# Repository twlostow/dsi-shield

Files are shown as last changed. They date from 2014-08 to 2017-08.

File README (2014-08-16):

DSI Core Readme
------------------------

0. Disclaimer

This project implements a MIPI DSI (MIPI Display Serial Interface) Verilog core.
Since the DSI specification is non-public and requires an NDA, the core was built
using bits and pieces available throughout the Web: presentations, display controller/SOC
datasheets, various application notes and Android kernel drivers. The author is not 
associated in any way with the MIPI Alliance. The core is provided as-is, it has never been
verified for compliance with the DSI standard and it probably lacks many of its features.
You use it at your own risk, there's no warranty.

1. License

- All HDL (unless otherwise noted) is released under LGPL v3.0
- All software (unless otherwise noted), is GPL v 3.0 or later.
- PCB design and schematics are licensed under CERN Open Hardware License v 1.2.

2. Acknowledgements

- Special thanks go to Sebastien Bourdeauducq, the creator of the Milkymist project, for his 
  excellent IP cores (HPDMC, FML and LM32 Xilinx port) used by in the DSI shield firmware.

- Andrew "Bunnie" Huang, for his EDID generation tools (Chumby WebTV project).

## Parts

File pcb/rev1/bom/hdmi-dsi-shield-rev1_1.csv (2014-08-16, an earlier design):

Comment | Description | Designator | Footprint | Mounted | Quantity | Value
100n | Capacitor | C1 | CAPC1608X87N | Yes | 1 | 100n
100n | Capacitor | C2 | CAPC1608X87N | Yes | 1 | 100n
100n | Capacitor | C3 | CAPC1608X87N | Yes | 1 | 100n
100n | Capacitor | C4 | CAPC1608X87N | Yes | 1 | 100n
100n | Capacitor | C5 | CAPC1608X87N | Yes | 1 | 100n
1u X5R | Capacitor | C6 | CAPC1608X87N | Yes | 1 | 1u X5R
100n | Capacitor | C7 | CAPC1608X87N | Yes | 1 | 100n
100n | Capacitor | C8 | CAPC1608X87N | Yes | 1 | 100n
1u X5R | Capacitor | C9 | CAPC1608X87N | Yes | 1 | 1u X5R
100n | Capacitor | C10 | CAPC1608X87N | Yes | 1 | 100n
100n | Capacitor | C11 | CAPC1608X87N | Yes | 1 | 100n
100n | Capacitor | C12 | CAPC1608X87N | Yes | 1 | 100n
100n | Capacitor | C13 | CAPC1608X87N | Yes | 1 | 100n
1u X5R | Capacitor | C14 | CAPC1608X87N | Yes | 1 | 1u X5R
100n | Capacitor | C15 | CAPC1608X87N | Yes | 1 | 100n
100n | Capacitor | C16 | CAPC1608X87N | Yes | 1 | 100n
100n | Capacitor | C17 | CAPC1608X87N | Yes | 1 | 100n
100n | Capacitor | C18 | CAPC1608X87N | Yes | 1 | 100n
1u X5R | Capacitor | C19 | CAPC1608X87N | Yes | 1 | 1u X5R
100n | Capacitor | C20 | CAPC1608X87N | Yes | 1 | 100n
100n | Capacitor | C21 | CAPC1608X87N | Yes | 1 | 100n
100n | Capacitor | C22 | CAPC1608X87N | Yes | 1 | 100n
100n | Capacitor | C23 | CAPC1608X87N | Yes | 1 | 100n
1u X5R | Capacitor | C24 | CAPC1608X87N | Yes | 1 | 1u X5R
100n | Capacitor | C25 | CAPC1608X87N | Yes | 1 | 100n
100n | Capacitor | C26 | CAPC1608X87N | Yes | 1 | 100n
100n | Capacitor | C27 | CAPC1608X87N | Yes | 1 | 100n
100n | Capacitor | C28 | CAPC1608X87N | Yes | 1 | 100n
1u X5R | Capacitor | C29 | CAPC1608X87N | No | 1 | 1u X5R
100n | Capacitor | C30 | CAPC1608X87N | No | 1 | 100n
100n | Capacitor | C31 | CAPC1608X87N | No | 1 | 100n
100n | Capacitor | C32 | CAPC1608X87N | No | 1 | 100n
100n | Capacitor | C33 | CAPC1608X87N | No | 1 | 100n
100n | Capacitor | C34 | CAPC1608X87N | No | 1 | 100n
1u X5R | Capacitor | C35 | CAPC1608X87N | No | 1 | 1u X5R
100n | Capacitor | C36 | CAPC1608X87N | No | 1 | 100n
100n | Capacitor | C37 | CAPC1608X87N | No | 1 | 100n
100n | Capacitor | C38 | CAPC1608X87N | No | 1 | 100n
100n | Capacitor | C40 | CAPC1608X87N | No | 1 | 100n
100n | Capacitor | C41 | CAPC1608X87N | No | 1 | 100n
1u X5R | Capacitor | C42 | CAPC1608X87N | Yes | 1 | 1u X5R
1u X5R | Capacitor | C43 | CAPC1608X87N | Yes | 1 | 1u X5R
1u X5R | Capacitor | C44 | CAPC1608X87N | Yes | 1 | 1u X5R
4.7u X5R | Capacitor | C45 | CAPC1608X87N | Yes | 1 | 4.7u X5R
10u X5R | Capacitor | C46 | INDC2012-0805 | Yes | 1 | 10u X5R
1u X5R | Capacitor | C47 | CAPC1608X87N | Yes | 1 | 1u X5R
1u X5R | Capacitor | C48 | CAPC1608X87N | Yes | 1 | 1u X5R
22p | Capacitor | C49 | CAPC1608X87N | Yes | 1 | 22p
10u X5R | Capacitor | C50 | INDC2012-0805 | Yes | 1 | 10u X5R
4.7u X5R | Capacitor | C51 | CAPC1608X87N | Yes | 1 | 4.7u X5R
1u X5R | Capacitor | C52 | CAPC1608X87N | Yes | 1 | 1u X5R
8.2p | Capacitor | C53 | CAPC1608X87N | Yes | 1 | 8.2p
10u X5R | Capacitor | C54 | INDC2012-0805 | Yes | 1 | 10u X5R
4.7u X5R | Capacitor | C55 | CAPC1608X87N | Yes | 1 | 4.7u X5R
4.7u X5R | Capacitor | C56 | CAPC1608X87N | Yes | 1 | 4.7u X5R
6.8p | Capacitor | C57 | CAPC1608X87N | Yes | 1 | 6.8p
10u X5R | Capacitor | C58 | INDC2012-0805 | Yes | 1 | 10u X5R
33p | Capacitor | C59 | CAPC1608X87N | Yes | 1 | 33p
47u | Polarized Capacitor Tantalum | C60 | TC3528-1411 | Yes | 1 | 47u
47u | Polarized Capacitor Tantalum | C61 | TC3528-1411 | Yes | 1 | 47u
1u X5R | Capacitor | C62 | INDC2012-0805 | Yes | 1 | 1u X5R
4.7u X5R | Capacitor | C63 | CAPC1608X87N | Yes | 1 | 4.7u X5R
1u X5R | Capacitor | C64 | CAPC1608X87N | Yes | 1 | 1u X5R
100n | Capacitor | C65 | CAPC1608X87N | Yes | 1 | 100n
10n | Capacitor | C66 | CAPC1608X87N | Yes | 1 | 10n
100n | Capacitor | C67 | CAPC1608X87N | Yes | 1 | 100n
10n | Capacitor | C68 | CAPC1608X87N | Yes | 1 | 10n
10n | Capacitor | C69 | CAPC1608X87N | Yes | 1 | 10n
10n | Capacitor | C70 | CAPC1608X87N | Yes | 1 | 10n
100n | Capacitor | C71 | CAPC1608X87N | Yes | 1 | 100n
100n | Capacitor | C72 | CAPC1608X87N | Yes | 1 | 100n
100n | Capacitor | C73 | CAPC1608X87N | Yes | 1 | 100n
100n | Capacitor | C75 | CAPC1608X87N | Yes | 1 | 100n
1u X5R | Capacitor | C76 | CAPC1608X87N | Yes | 1 | 1u X5R
100n | Capacitor | C77 | CAPC1608X87N | Yes | 1 | 100n
HDMI | Connector HDMI 19 Male + 1 Shield | CN1 | MOLEX_500254-1927 | Yes | 1 | MOLEX 500254-1927
USB | 5 Pin + 1 Shield USB Receptacle | CN2 | TYCO_1734035-1 | Yes | 1 | TYCO_1734035-1
DSI | Header, 15-Pin, Dual row | CN3 | CONN_2x15_2mm_side | Yes | 1
JTAG | Header, 6-Pin | CN4 | HDR1X6 | Yes | 1
IOH |  | CN5 | Header 10x1 8.5mm | Yes | 1
POWER |  | CN6 | Header 8x1 8.5mm | Yes | 1
IOL |  | CN7 | Header 8x1 8.5mm | Yes | 1
AD |  | CN8 | Header 6x1 8.5mm | Yes | 1
BAS170W | Diode | D1 | SOD323 | Yes | 1
BAS170W | Diode | D2 | SOD323 | Yes | 1
BAS170W | Diode | D3 | SOD323 | Yes | 1
BAS170W | Diode | D4 | SOD323 | Yes | 1
BZT52C24S | Zener Diode | D5 | SOD323 | Yes | 1 | BZT52C24S
BAS170W | Diode | D6 | SOD323 | Yes | 1
IP4292CZ10 | HDMI ESD protection diode | D7 | SOT1176-1 | Yes | 1 | IP4292CZ10
IP4292CZ10 | HDMI ESD protection diode | D8 | SOT1176-1 | Yes | 1
BAS170W | Diode | D9 | SOD323 | Yes | 1
XC6SLX9-3TQG144I | Spartan-6 LX 1.2V FPGA, 102 User I/Os, 144-Pin TQFP (0.5mm Pitch), Speed Grade 3, Industrial Grade, Pb-Free | IC1 | QFP50P2200X2200X160-144N | Yes | 1
M25P80-VMN6P | 8 Mbit, 2.7V to 3.6V Serial Flash Embedded Memory | IC2 | SOIC127P600X175-8N | Yes | 1
ADV7611 | HDMI receiver | IC3 | TSQFP50P1200X1200-65L | No | 1
LM26480 | 2xLDO, 2xBuck PMIC | IC4 | QFN50P400X400-24W2M | Yes | 1 | LM26480SQ-AA
TPS61041 |  | IC5 | SOT23-5AL | Yes | 1 | TPS61041DBVR
TPS61041 |  | IC6 | SOT23-5AL | Yes | 1 | TPS61041DBVR
CP2103 | USB-UART bridge | IC7 | QFN50P400X400-28W9M | Yes | 1 | CP2103-GM
PRTR5V0U2X | Ultra Low Capacitance Double Rail-to-Rail ESD Protection Diode | IC8 | SOT190P230X110-4N | Yes | 1
PRTR5V0U2X | Ultra Low Capacitance Double Rail-to-Rail ESD Protection Diode | IC9 | SOT190P230X110-4N | Yes | 1
MT46V32M16P-5B:F | 512MBit x16 DDR SDRAM | IC10 | TSOP66 | Yes | 1
PRTR5V0U2X | Ultra Low Capacitance Double Rail-to-Rail ESD Protection Diode | IC11 | SOT190P230X110-4N | Yes | 1 | PRTR5V0U2X
25 MHz 2x3.2mm | SMD oscillator 3.3V (Elfa) | IC12 | OSC_5x32mm | Yes | 1 | 25 MHz 2x3.2mm
f.bead | Inductor With Magnetic core | L1 | INDC1608-0603 | Yes | 1 | f.bead
4.7 uH | Inductor With Magnetic core | L2 | IND_PANASONIC_ELLVEG | Yes | 1 | ELLVEG4R7N
2.2 uH | Inductor With Magnetic core | L3 | IND_PANASONIC_ELLVEG | Yes | 1 | ELLVEG2R2N
2.2 uH | Inductor With Magnetic core | L4 | IND_PANASONIC_ELLVEG | Yes | 1 | ELLVEG2R2N
4.7 uH | Inductor With Magnetic core | L5 | IND_PANASONIC_ELLVEG | Yes | 1 | ELLVEG4R7N
BSS84 | P MOSFET 50V, 0.36W, 0.15A | Q1 | SOT23-3 | Yes | 1 | BSS84
2N7002 | N-Channel MOSFET | Q2 | SOT23-3 | Yes | 1
2N7002 | N-Channel MOSFET | Q3 | SOT23-3 | Yes | 1
2N7002 | N-Channel MOSFET | Q4 | SOT23-3 | Yes | 1
22R | Resistor | R1A | RESC1608X55N | Yes | 1 | 22R
22R | Resistor | R1B | RESC1608X55N | Yes | 1 | 22R
22R | Resistor | R1C | RESC1608X55N | Yes | 1 | 22R
22R | Resistor | R1D | RESC1608X55N | Yes | 1 | 22R
22R | Resistor | R1E | RESC1608X55N | Yes | 1 | 22R
160R | Resistor | R2A | RESC1608X55N | Yes | 1 | 160R
160R | Resistor | R2B | RESC1608X55N | Yes | 1 | 160R
160R | Resistor | R2C | RESC1608X55N | Yes | 1 | 160R
160R | Resistor | R2D | RESC1608X55N | Yes | 1 | 160R
160R | Resistor | R2E | RESC1608X55N | Yes | 1 | 160R
51R | Resistor | R3A | RESC1608X55N | Yes | 1 | 51R
51R | Resistor | R3B | RESC1608X55N | Yes | 1 | 51R
51R | Resistor | R3C | RESC1608X55N | Yes | 1 | 51R
51R | Resistor | R3D | RESC1608X55N | Yes | 1 | 51R
51R | Resistor | R3E | RESC1608X55N | Yes | 1 | 51R
51R | Resistor | R4A | RESC1608X55N | Yes | 1 | 51R
51R | Resistor | R4B | RESC1608X55N | Yes | 1 | 51R
51R | Resistor | R4C | RESC1608X55N | Yes | 1 | 51R
51R | Resistor | R4D | RESC1608X55N | Yes | 1 | 51R
51R | Resistor | R4E | RESC1608X55N | Yes | 1 | 51R
160R | Resistor | R5A | RESC1608X55N | Yes | 1 | 160R
160R | Resistor | R5B | RESC1608X55N | Yes | 1 | 160R
160R | Resistor | R5C | RESC1608X55N | Yes | 1 | 160R
160R | Resistor | R5D | RESC1608X55N | Yes | 1 | 160R
160R | Resistor | R5E | RESC1608X55N | Yes | 1 | 160R
22R | Resistor | R6A | RESC1608X55N | Yes | 1 | 22R
22R | Resistor | R6B | RESC1608X55N | Yes | 1 | 22R
22R | Resistor | R6C | RESC1608X55N | Yes | 1 | 22R
22R | Resistor | R6D | RESC1608X55N | Yes | 1 | 22R
22R | Resistor | R6E | RESC1608X55N | Yes | 1 | 22R
3.3k | Resistor | R7 | RESC1608X55N | Yes | 1 | 3.3k
3.3k | Resistor | R8 | RESC1608X55N | Yes | 1 | 3.3k
3.3k | Resistor | R9 | RESC1608X55N | Yes | 1 | 3.3k
3.3k | Resistor | R10 | RESC1608X55N | Yes | 1 | 3.3k
51 | Resistor | R11 | RESC1608X55N | Yes | 1 | 51
51 | Resistor | R12 | RESC1608X55N | Yes | 1 | 51
51 | Resistor | R13 | RESC1608X55N | Yes | 1 | 51
51 | Resistor | R14 | RESC1608X55N | Yes | 1 | 51
51 | Resistor | R15 | RESC1608X55N | Yes | 1 | 51
51 | Resistor | R16 | RESC1608X55N | Yes | 1 | 51
51 | Resistor | R17 | RESC1608X55N | Yes | 1 | 51
51 | Resistor | R18 | RESC1608X55N | Yes | 1 | 51
33 | Resistor | R19 | RESC1608X55N | Yes | 1 | 33
180 | Resistor | R20 | RESC1608X55N | Yes | 1 | 180
220 | Resistor | R21 | RESC1608X55N | Yes | 1 | 220
3.3k | Resistor | R22 | RESC1608X55N | Yes | 1 | 3.3k
1k | Resistor | R23 | RESC1608X55N | Yes | 1 | 1k
3.3k | Resistor | R24 | RESC1608X55N | Yes | 1 | 3.3k
3.3k | Resistor | R25 | RESC1608X55N | Yes | 1 | 3.3k
3.3k | Resistor | R26 | RESC1608X55N | Yes | 1 | 3.3k
1M | Resistor | R27 | RESC1608X55N | Yes | 1 | 1M
3.3k | Resistor | R28 | RESC1608X55N | Yes | 1 | 3.3k
3.3k | Resistor | R29 | RESC1608X55N | Yes | 1 | 3.3k
3k3 | Resistor | R30 | RESC1608X55N | Yes | 1 | 3k3
3k3 | Resistor | R31 | RESC1608X55N | Yes | 1 | 3k3
1k | Resistor | R32 | RESC1608X55N | No | 1 | 1k
3.3k | Resistor | R33 | RESC1608X55N | No | 1 | 3.3k
3.3k | Resistor | R34 | RESC1608X55N | No | 1 | 3.3k
100k | Resistor | R35 | RESC1608X55N | Yes | 1 | 100k
280k | Resistor | R36 | RESC1608X55N | Yes | 1 | 280k
200k | Resistor | R37 | RESC1608X55N | Yes | 1 | 200k
750k | Resistor | R38 | RESC1608X55N | Yes | 1 | 750k
100k | Resistor | R39 | RESC1608X55N | Yes | 1 | 100k
187k | Resistor | R40 | RESC1608X55N | Yes | 1 | 187k
464k | Resistor | R41 | RESC1608X55N | Yes | 1 | 464k
100k | Resistor | R42 | RESC1608X55N | Yes | 1 | 100k
178k | Resistor | R43 | RESC1608X55N | Yes | 1 | 178k
100k | Resistor | R44 | RESC1608X55N | Yes | 1 | 100k
560k | Resistor | R45 | RESC1608X55N | Yes | 1 | 560k
100k | Resistor | R46 | RESC1608X55N | Yes | 1 | 100k
100 | Resistor | R47 | RESC1608X55N | Yes | 1 | 100
0 | Resistor | R48 | RESC1608X55N | Yes | 1 | 0
100 | Resistor | R67 | RESC1608X55N | Yes | 1 | 100
1k | Resistor | R68 | RESC1608X55N | Yes | 1 | 1k
1k | Resistor | R69 | RESC1608X55N | Yes | 1 | 1k
3.3k | Resistor | R70 | RESC1608X55N | Yes | 1 | 3.3k
3.3k | Resistor | R71 | RESC1608X55N | Yes | 1 | 3.3k
0 | Resistor | R72 | RESC1608X55N | Yes | 1 | 0
0R | Resistor network 0804 PHYCOMP (Farnell) | RP1 | YC124 | Yes | 1 | 0R
0R | Resistor network 0804 PHYCOMP (Farnell) | RP2 | YC124 | Yes | 1 | 0R
0R | Resistor network 0804 PHYCOMP (Farnell) | RP3 | YC124 | Yes | 1 | 0R
0R | Resistor network 0804 PHYCOMP (Farnell) | RP4 | YC124 | Yes | 1 | 0R
0R | Resistor network 0804 PHYCOMP (Farnell) | RP6 | YC124 | Yes | 1 | 0R
0R | Resistor network 0804 PHYCOMP (Farnell) | RP7 | YC124 | No | 1 | 0R
0R | Resistor network 0804 PHYCOMP (Farnell) | RP8 | YC124 | No | 1 | 0R

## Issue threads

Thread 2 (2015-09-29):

Voltage on FPGA pin <PROGRAM_B_2> in Schematic main.sch

jojowolf, 2015-09-29:
hi Tomasz
Thanks for sharing this very interesting & good design

maybe not an important issue , but according to the Spartan6 Configuration specs (UG380.PDF)
on page 42 for "FPGA SPI Configuration Interface"
it says the Spartan-6 FPGA VCCO_2 supply must be the same voltage as VCC of the SPI device

so in the dsi-shield <main.sch> schematic , maybe it should be connected to 3V3 instead of 2V5 ?
(but anyway i guess it works also with 2V5 , but simply fyi about the official Xilinx specs)

Thanks again for sharing this project

jojowolf, 2015-09-29:
in fact some Xilinx boards have the SPI device with VCC 3V0 , and the VCCO_2 to +2.5V
so i guess it is OK with the FPGA pin <PROGRAM_B_2> connected to +2.5V (even if the UG380 does mention a different recommendation)

sorry for opening the issue : your design is CORRECT : so this issue can be CLOSED
Thanks

Closed 2015-09-29.

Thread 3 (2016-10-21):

License - CERN OHL or GPL?

evancox10, 2016-10-21:
Hi, I have a question about which license applies to the design files and documentation. The PCB has a silk screen that states its licensed under CERN OHL v1.2. However, the LICENSE file at the top of the repo is GNU LGPL v3. Can you clarify what the license is for the material?

Thanks,
Evan

evancox10, 2016-10-21:
Woops. If I had read the first page readme I would have seen that you covered this. Sorry!

Also, I noticed that many of the files in the IP Cores folder have no license information, some have a LGPL v2.1 license. I wanted to double check that incorporating these into this LGPL v3 project was ok. According to https://www.gnu.org/licenses/gpl-faq.html#AllCompatibility , does the combined work need to be released as GPLv3? Am I misunderstanding this?

Second, do you have any good resources you could point me to on the use of LGPL licensed HDL in an ASIC? This is clearly an evolving legal issue, and there may be no definitive answers. I am primarily concerned with the usage of the HDL in a commercial ASIC and whether or not that virally infects the rest of the chip.

Third, why not release the HDL under the CERN OHL? Do you know what CERN's position is on using the OHL vs (L)GPL for HDL?

From what I can tell, you seem to be at the forefront of many of these issues :)

dreamcat4, 2019-04-13:
Hi there. Stumbled across this project today while looking for a way to drive smartphone displays. And it seems like the only one!

In regards to licensing, it would be nice to take a general interest in these licensing and similar issues. And just remain contactable into the future about it. Which will help these project(s) to continue moving forwards without you, for other people to contribute their own work and improve the solution further.

Because there is a difference between Copyright and Licensing. The above is a good example of the linking clause being an issue. Well what to do about it?

https://en.wikipedia.org/wiki/GPL_linking_exception

This requires amendment(s) to the existing license, which can only be performed by the original (legal) copyright holder. So remaining contactable is important. Otherwise who else will want to come along be motivated to make a v3.0 with improved performance? Maybe on a bigger / faster FPGA ?

Because it seems one of the more significant use cases for this device would be 'open source VR heatsets'. However that really requires some extra performance above what was comented in the project's log over on the hackaday pages.

dreamcat4, 2019-04-13:
@twlostow In fact, this project might make for a good fit for the RISC-V open hardware project

https://en.wikipedia.org/wiki/RISC-V

So please also consider talking with stakeholders and experts over there, to see if there is any interest to develop this further. If you are looking for a more reputable place for this work to find a new home. Kind Regards

Closed 2017-03-31.

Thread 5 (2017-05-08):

Could you provide KiCad schematic/board ?

bvernoux, 2017-05-08:
Could you provide KiCad or other format (as it seems it is not done with KiCad) for schematic/board ?
As I have found only PDF files and you mention PCB design and schematics are licensed under CERN Open Hardware License v 1.2, so we could think it is fully open source including Schematics & Board ...

twlostow, 2017-08-31:
Done. Check out the repo.

Closed 2017-08-31.

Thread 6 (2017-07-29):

Adding Galaxy S4 AMOLED Adapter

Marccos, 2017-07-29:
Hi twlostow,

I saw at hackaday, that you managed to get a S4 Galaxy display working.
https://hackaday.io/project/364-mipi-dsi-display-shieldhdmi-adapter/log/16504-galaxy-s4-amoled-screen-working

I am interested to use this display for a small project. Could you upload the schematic/layout for this adapter or give me some hints where to find datasheets for this screen? if you give me some hints where to start, I can redesign the adapter(in KiCad) and upload my results in this case.

What changes in hdl/software need to be made to use this display (with revision 1.1 which is uploaded)?

--Marccos

BiatuAutMiahn, 2017-07-29:
I too am interested in this

BiatuAutMiahn, 2017-11-19:
Any updates on this?

mybays, 2019-08-31:
I too am interested in this

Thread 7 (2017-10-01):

Problem opening the kicad rev2 project

FacepalmMute, 2017-10-01:
Hey twlostow,

there are some problems when i try to open your rev2 kicad project.

1: Opening the .sch file gives me a dialog which says that some library's missing in /mnt/big/CernLib/KiCad/SchLib/... . Which library's do you use?

2: By opening the pcb file i get an error which says that my kicad version is to old, which is not the case. (newest 4.0.7+dfsg1-1)

twlostow, 2017-10-05:
1) these are my own libraries, not published yet. Using the rescue option
you can read the full schematic

2) open it in a nightly build

Tom

2017-10-01 13:17 GMT+02:00 Nikita Schewtschuk <notifications@github.com>:

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

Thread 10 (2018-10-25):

Cant find PCB and schematics

aziz2403, 2018-10-25:
Hi,

I cant find the PCB and Schematics that are published on here all I see is a bunch of code and no actual schematics for this.

twlostow, 2018-10-25:
https://github.com/twlostow/dsi-shield/tree/master/pcb/rev2

Closed 2018-10-25.

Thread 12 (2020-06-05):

Is Raspberry Pi Official Display supported?

GuzioMG, 2020-06-05:
On https://www.elektroda.pl/rtvforum/topic2913667.html I heard this module supports

> _720p@60 Hz lub_ [or] _1080p@48 Hz_

screens, but RaspPI screen is 480p@I_HAVE_NO_IDEA Hz, so I'm not sure, whether it's going to work or if something's going to blow up/don't work/burn/get damaged/glitch out.

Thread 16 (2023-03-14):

Mass production

xfce, 2023-03-14:
Hi
    @twlostow  and all,
I think I can help to mass product, as I am interested in FPGA, also use spatarn6 and adv7611( the hdmilight project on github),
my project is here [https://hackaday.io/project/189703-pinuo-fpga-hdmi-ambilight-control-system](url)

twlostow, 2023-03-15:
Hi,

Cool project (HDMILight)!. In the case of the MIPI adapter, the problem is not in the mass production, but in the mass support. Over the course of many years (since 2014 when this got published first), I've got hundreds of emails asking to sell the device, adapted to a particular display (meaning a PCB variant and quite often reverse engineering the init sequence). Potential buyers are eager to pay $100 or less... I don't think this is really worth the effort.

T.

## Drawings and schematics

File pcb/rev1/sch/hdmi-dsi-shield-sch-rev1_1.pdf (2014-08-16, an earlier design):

A

A

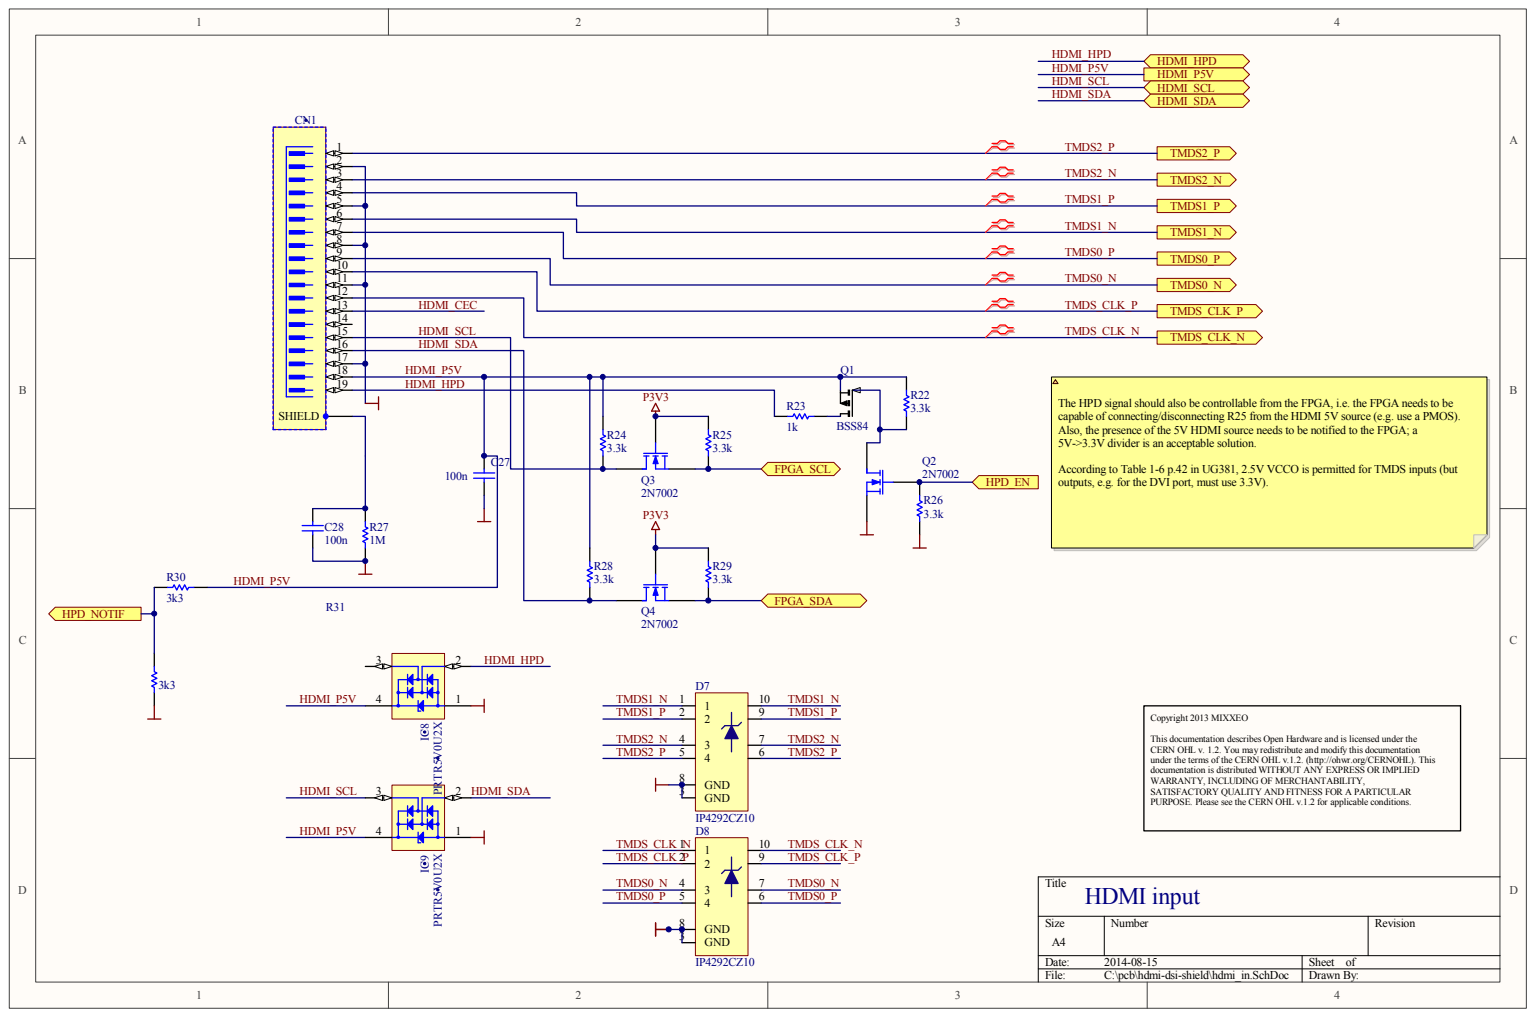
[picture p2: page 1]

The HPD signal should also be controllable from the FPGA, i.e. the FPGA needs to be
capable of connecting/disconnecting R25 from the HDMI 5V source (e.g. use a PMOS).
Also, the presence of the 5V HDMI source needs to be notified to the FPGA; a
5V->3.3V divider is an acceptable solution.

According to Table 1-6 p.42 in UG381, 2.5V VCCO is permitted for TMDS inputs (but
outputs, e.g. for the DVI port, must use 3.3V).

This documentation describes Open Hardware and is licensed under the
CERN OHL v. 1.2. You may redistribute and modify this documentation
under the terms of the CERN OHL v.1.2. (http://ohwr.org/CERNOHL). This
documentation is distributed WITHOUT ANY EXPRESS OR IMPLIED
WARRANTY, INCLUDING OF MERCHANTABILITY,
SATISFACTORY QUALITY AND FITNESS FOR A PARTICULAR
PURPOSE. Please see the CERN OHL v.1.2 for applicable conditions.

A | A

## SDRAM_A0

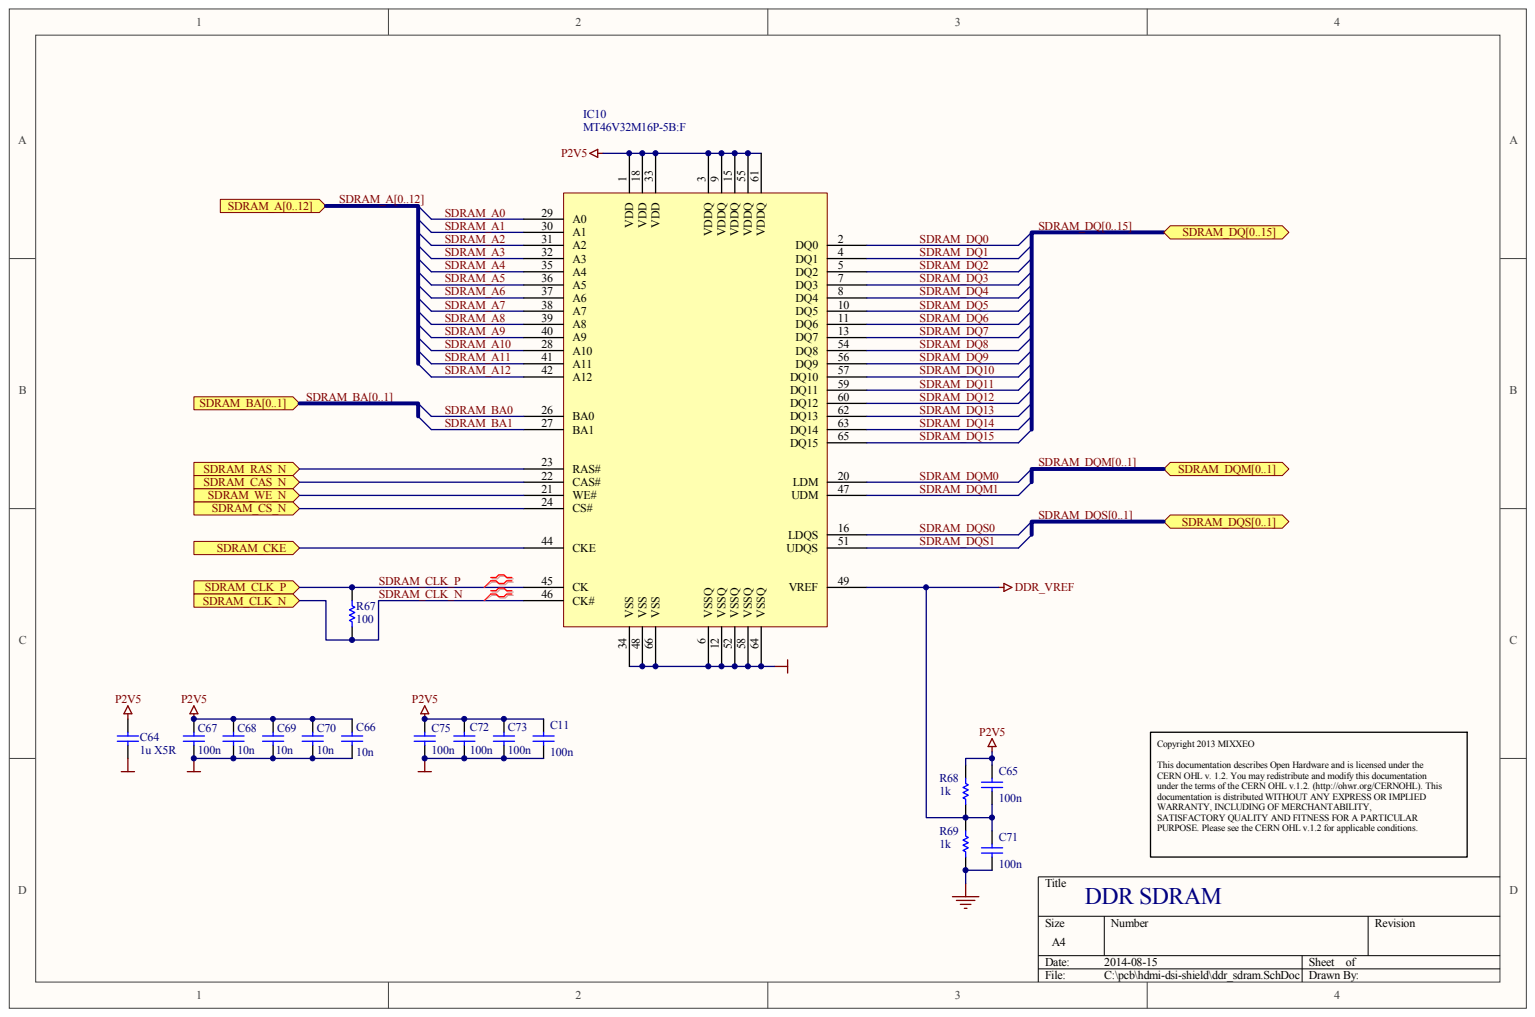
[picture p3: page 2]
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

A | A

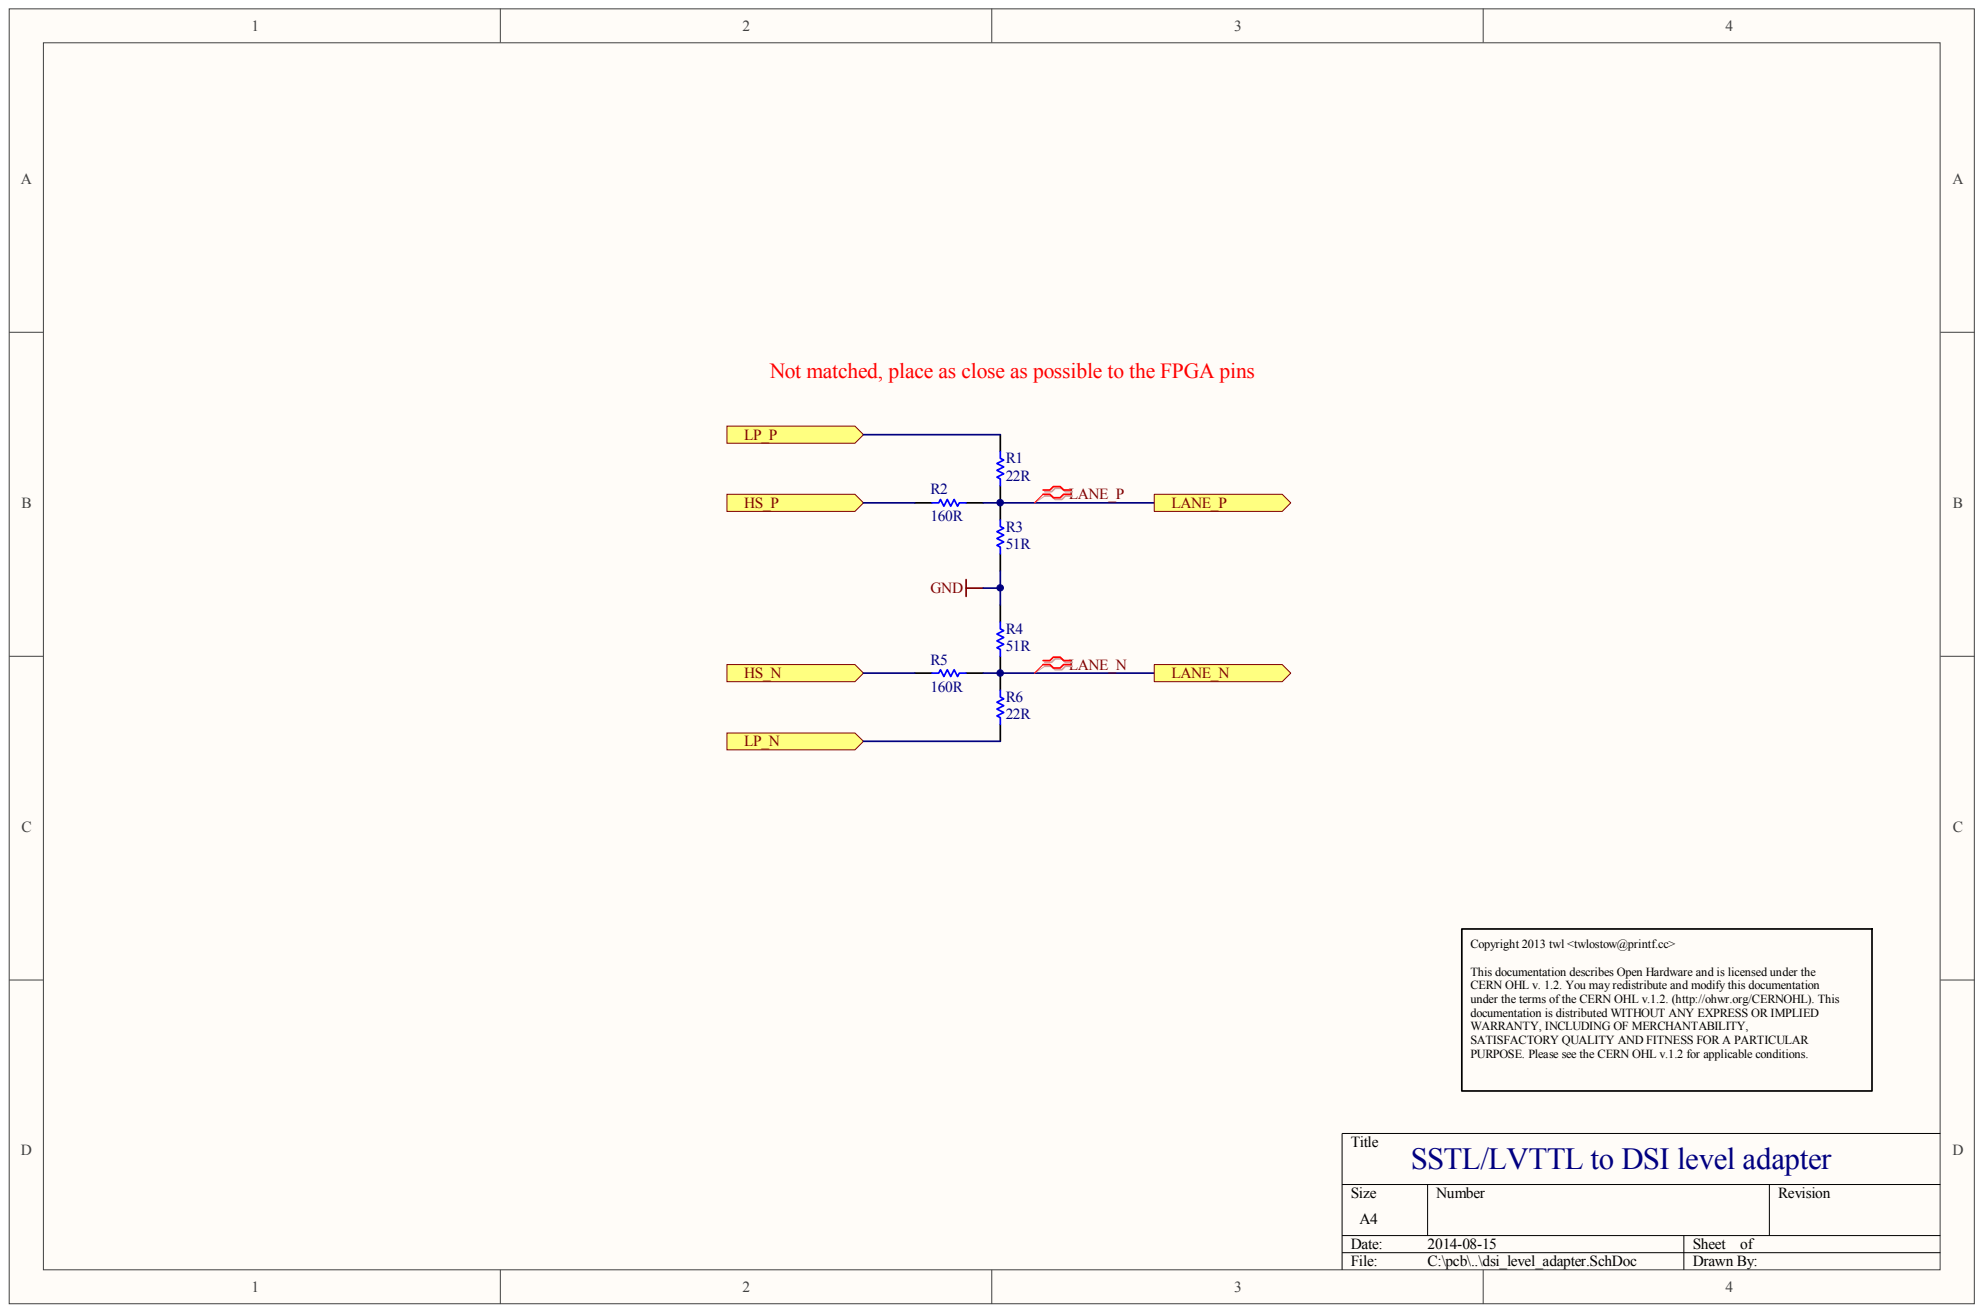
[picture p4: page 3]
Size; Number; Revision; File:; C:\pcb\..\dsi_level_adapter.SchDoc; Drawn By:; GND; LANE_P; LANE_N

Not matched, place as close as possible to the FPGA pins

Copyright 2013 twl <twlostow@printf.cc>

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

Title
SSTL/LVTTL to DSI level adapter

JTAG & configuration flash | TMS

## Host interface

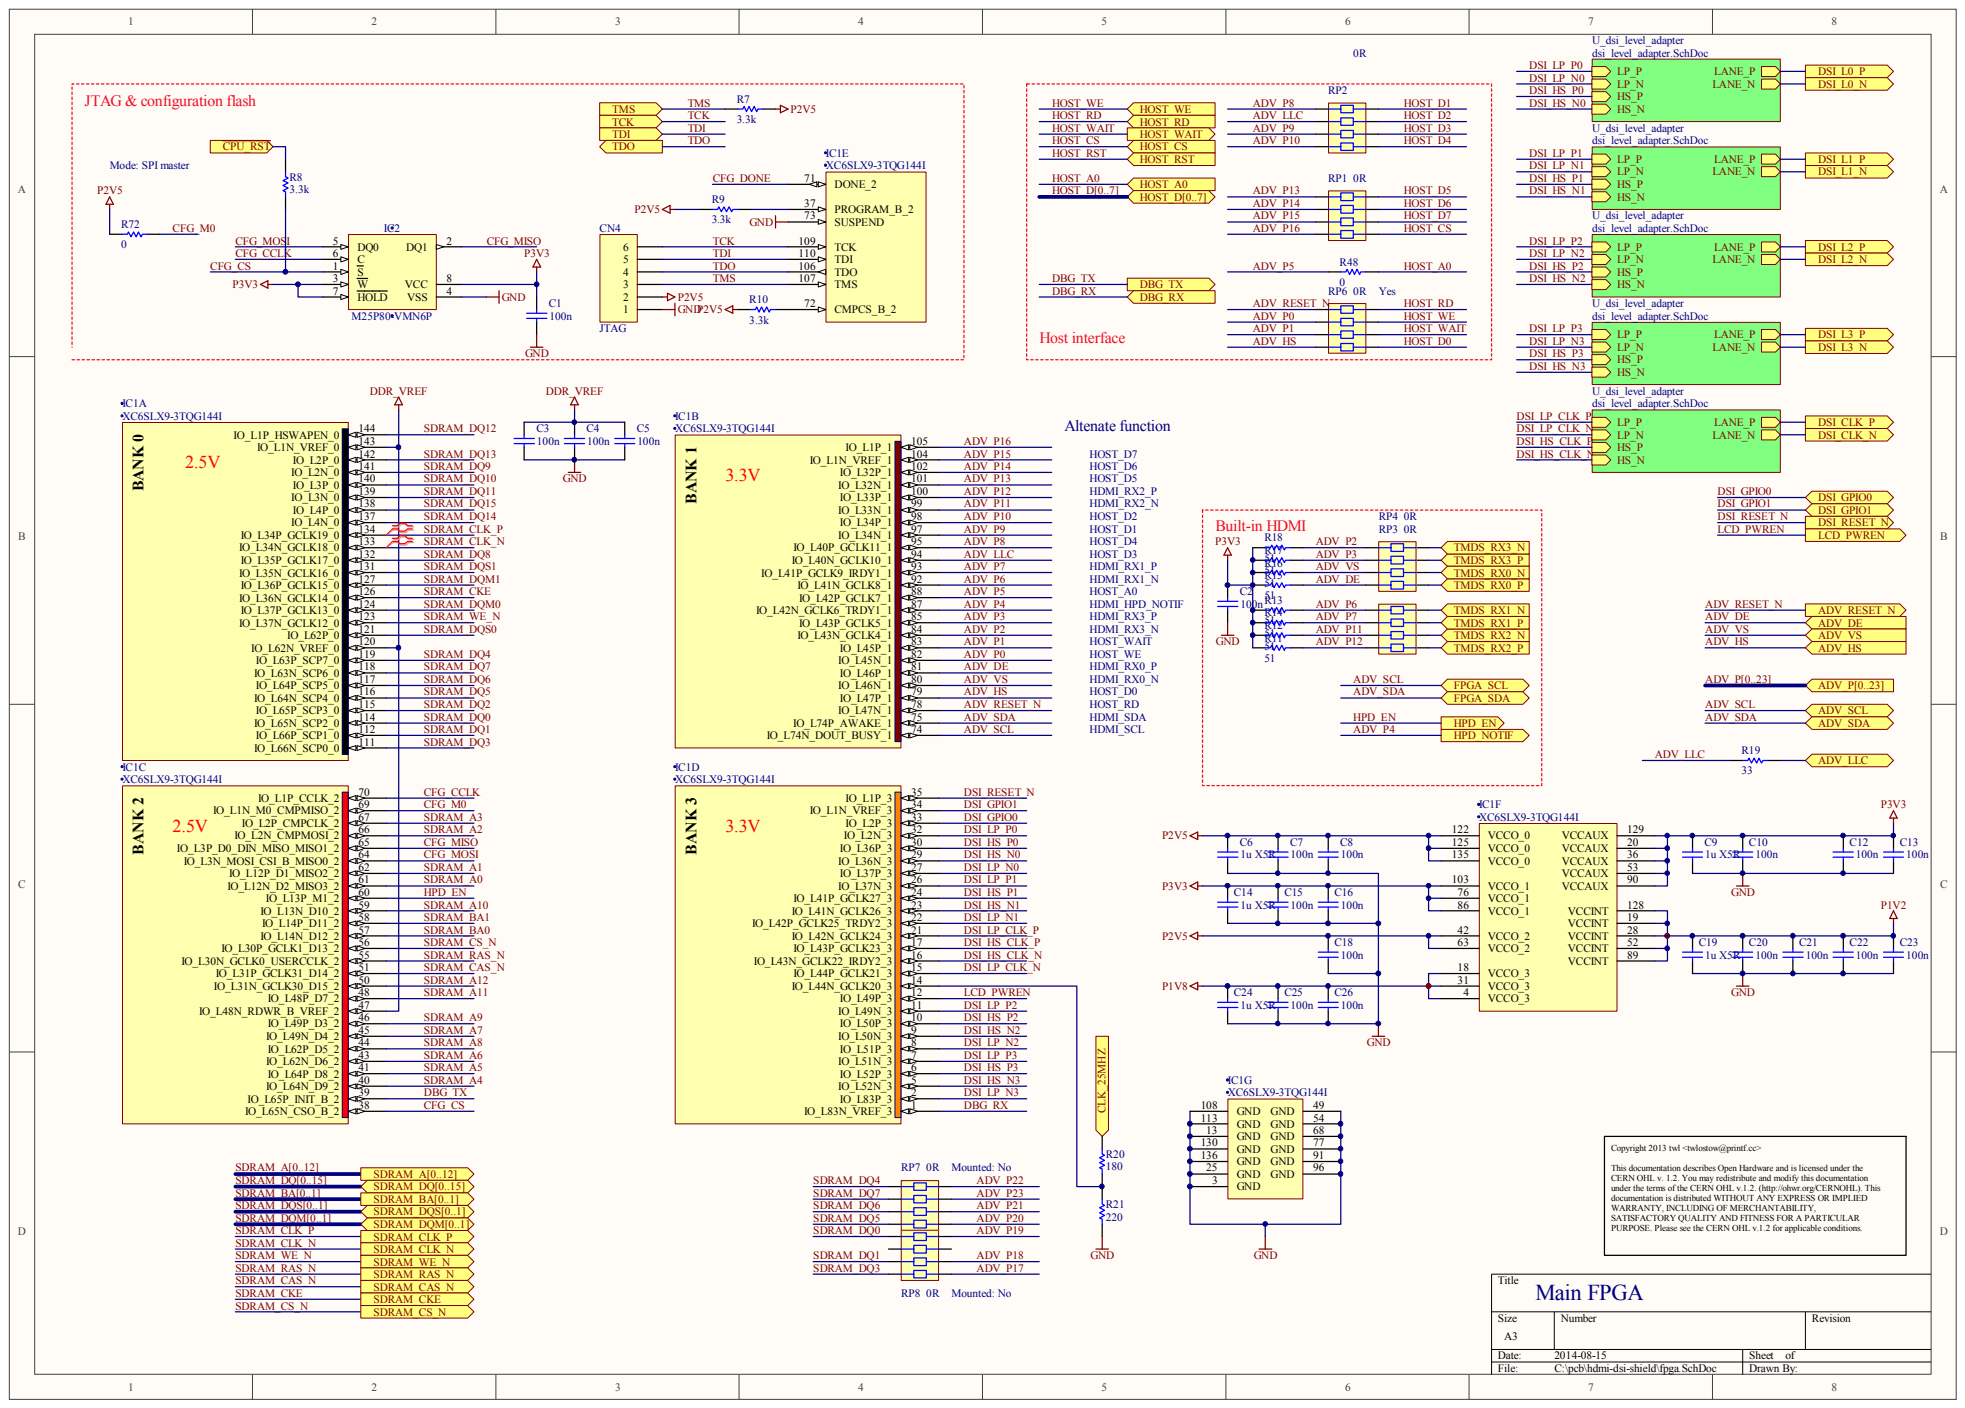
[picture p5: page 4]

Copyright 2013 twl <twlostow@printf.cc>

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

A

A

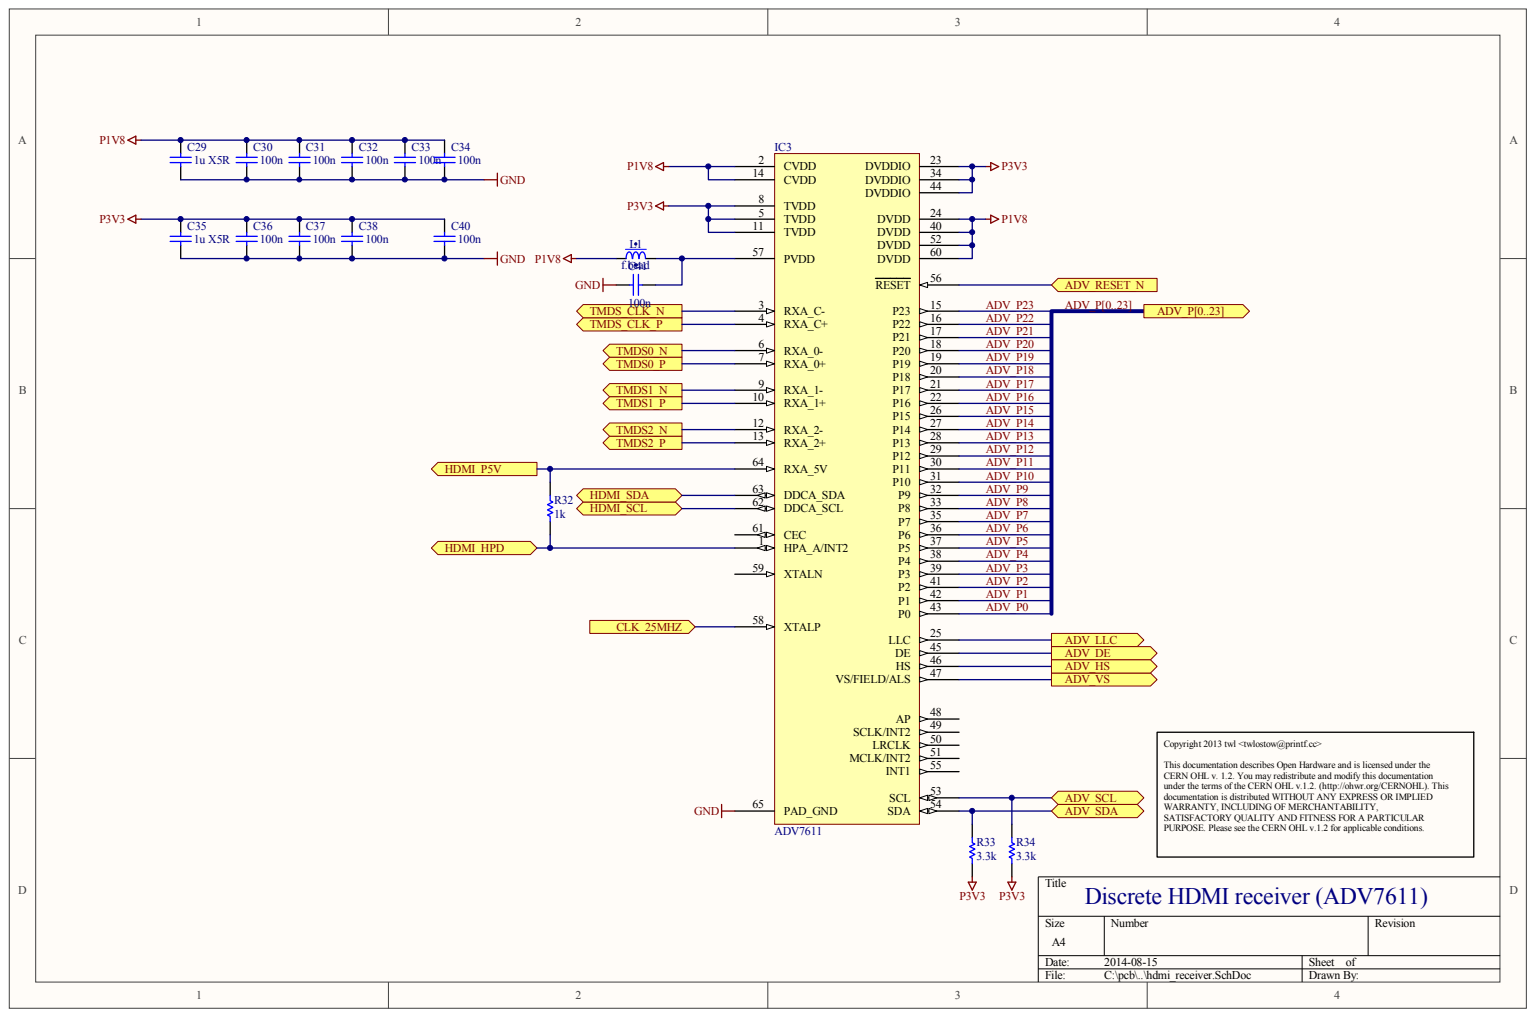
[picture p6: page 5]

Copyright 2013 twl <twlostow@printf.cc>

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

A

A

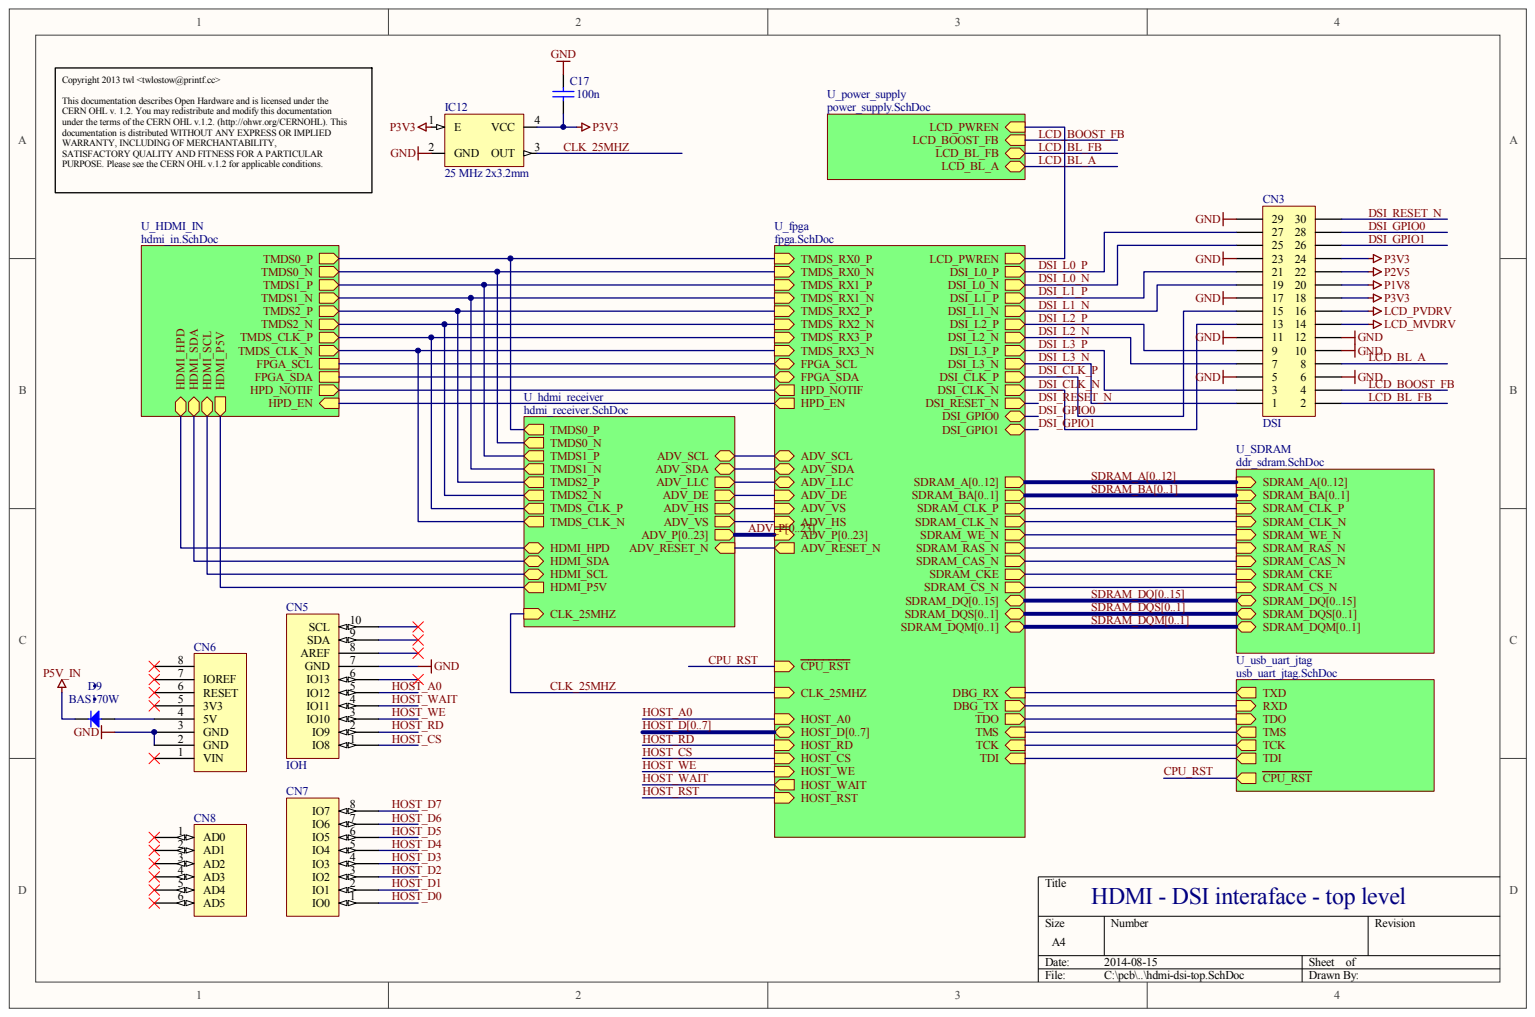
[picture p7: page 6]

Copyright 2013 twl <twlostow@printf.cc>

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

Title
HDMI - DSI interaface - top level

A | A
VINLDO12 1 | SYNC | 2

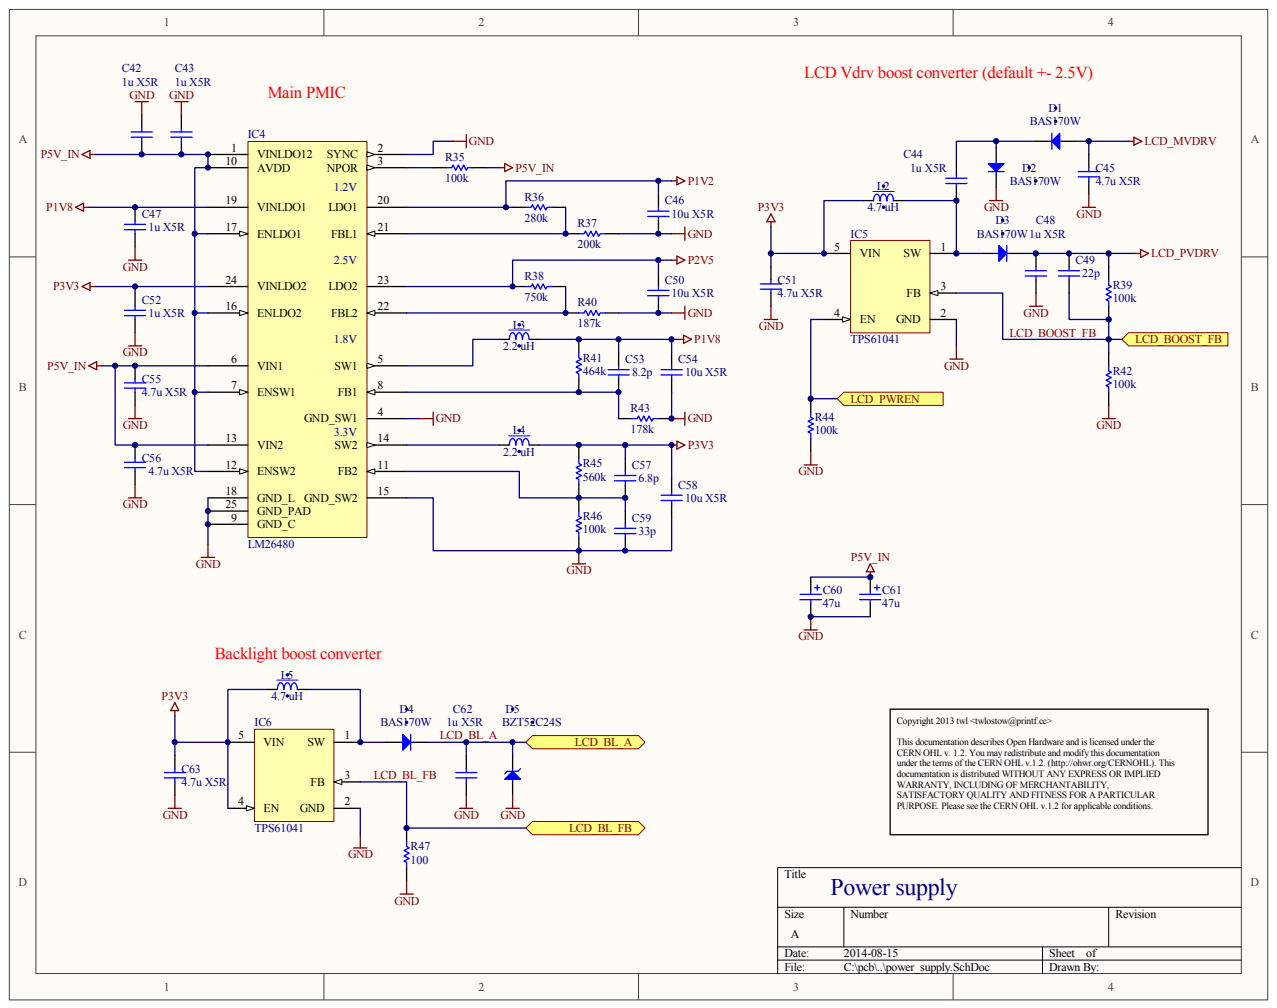
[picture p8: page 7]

LCD Vdrv boost converter (default +- 2.5V)

Copyright 2013 twl <twlostow@printf.cc>

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

A | A

P3V3

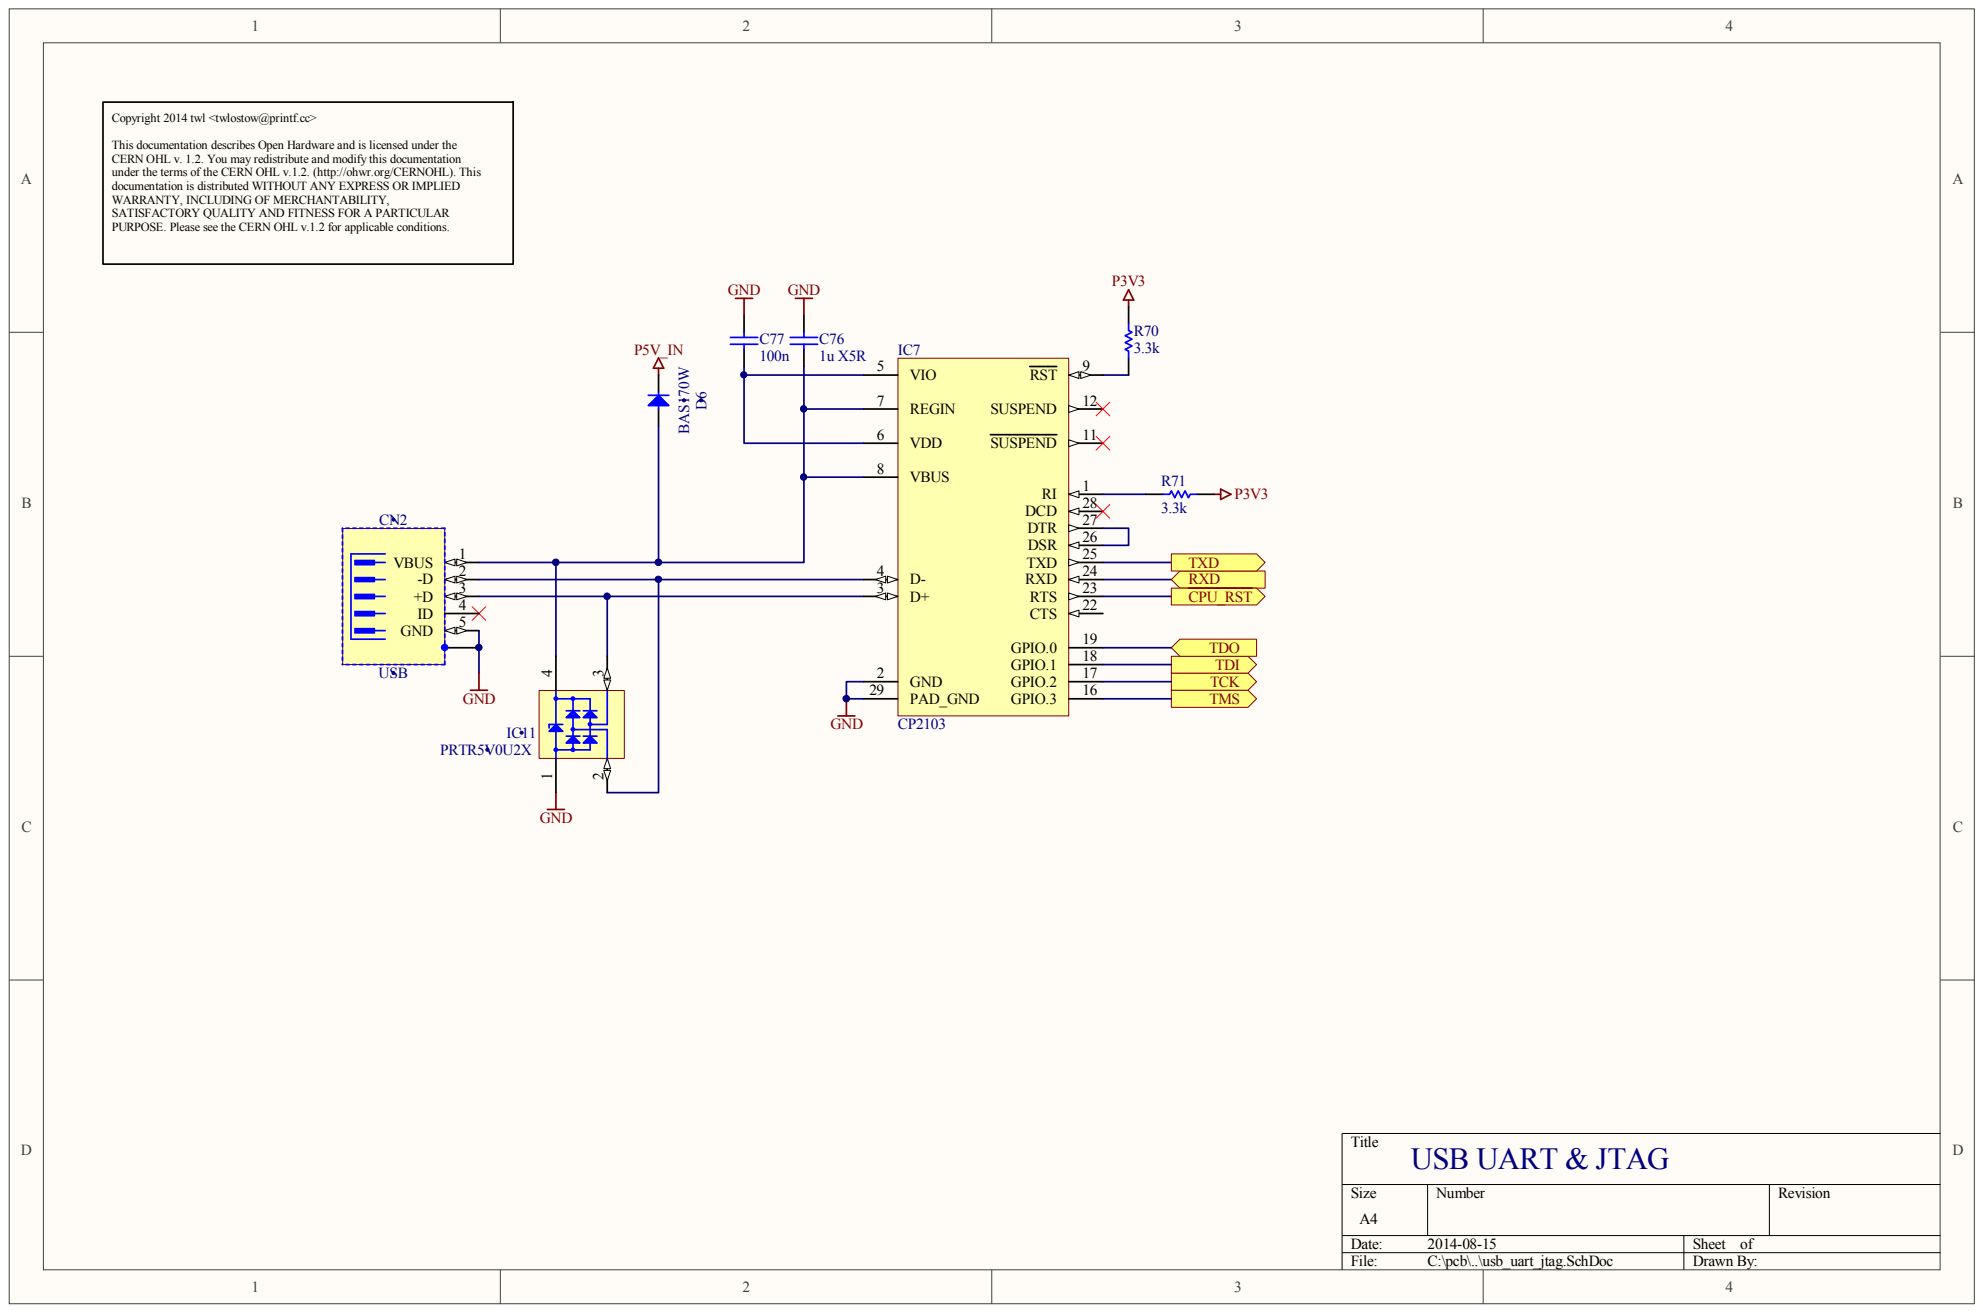
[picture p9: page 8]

Copyright 2014 twl <twlostow@printf.cc>
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

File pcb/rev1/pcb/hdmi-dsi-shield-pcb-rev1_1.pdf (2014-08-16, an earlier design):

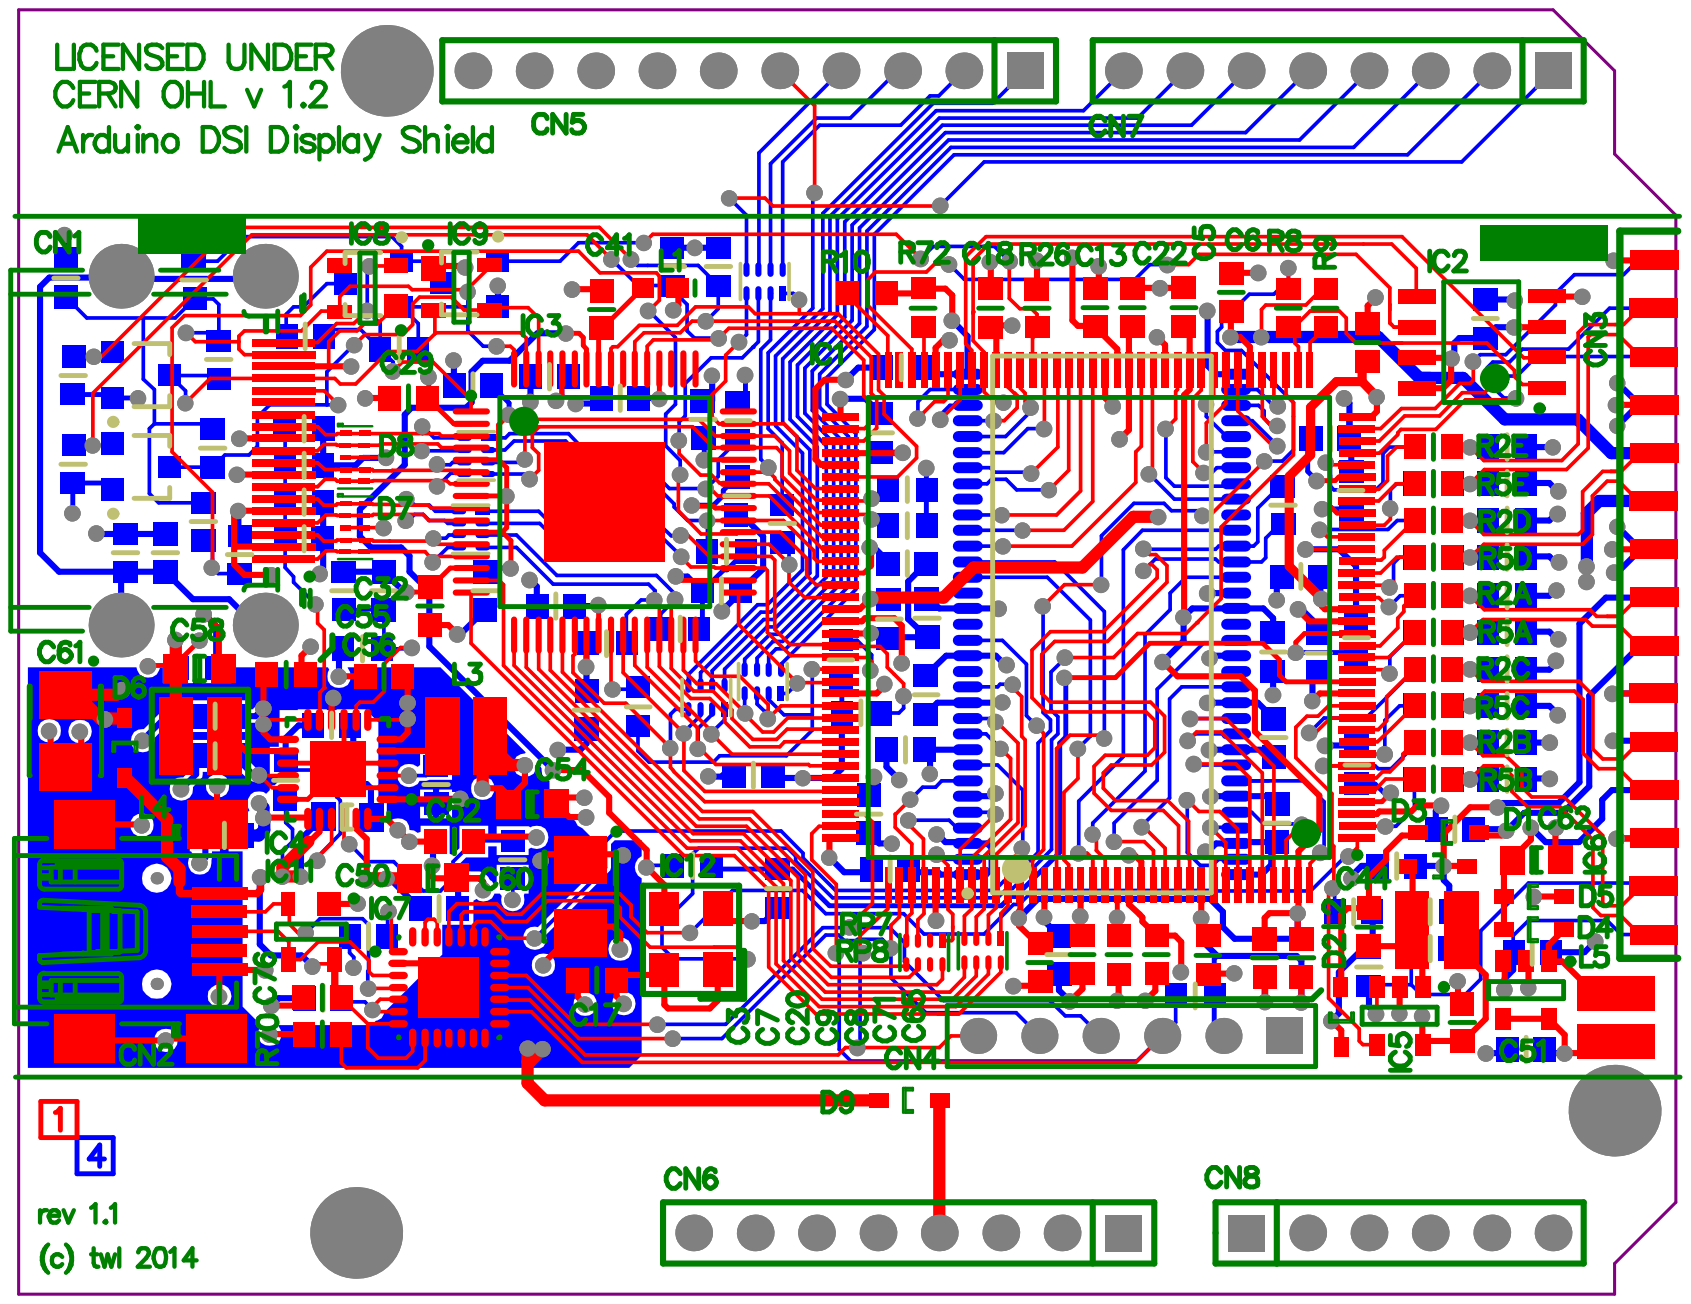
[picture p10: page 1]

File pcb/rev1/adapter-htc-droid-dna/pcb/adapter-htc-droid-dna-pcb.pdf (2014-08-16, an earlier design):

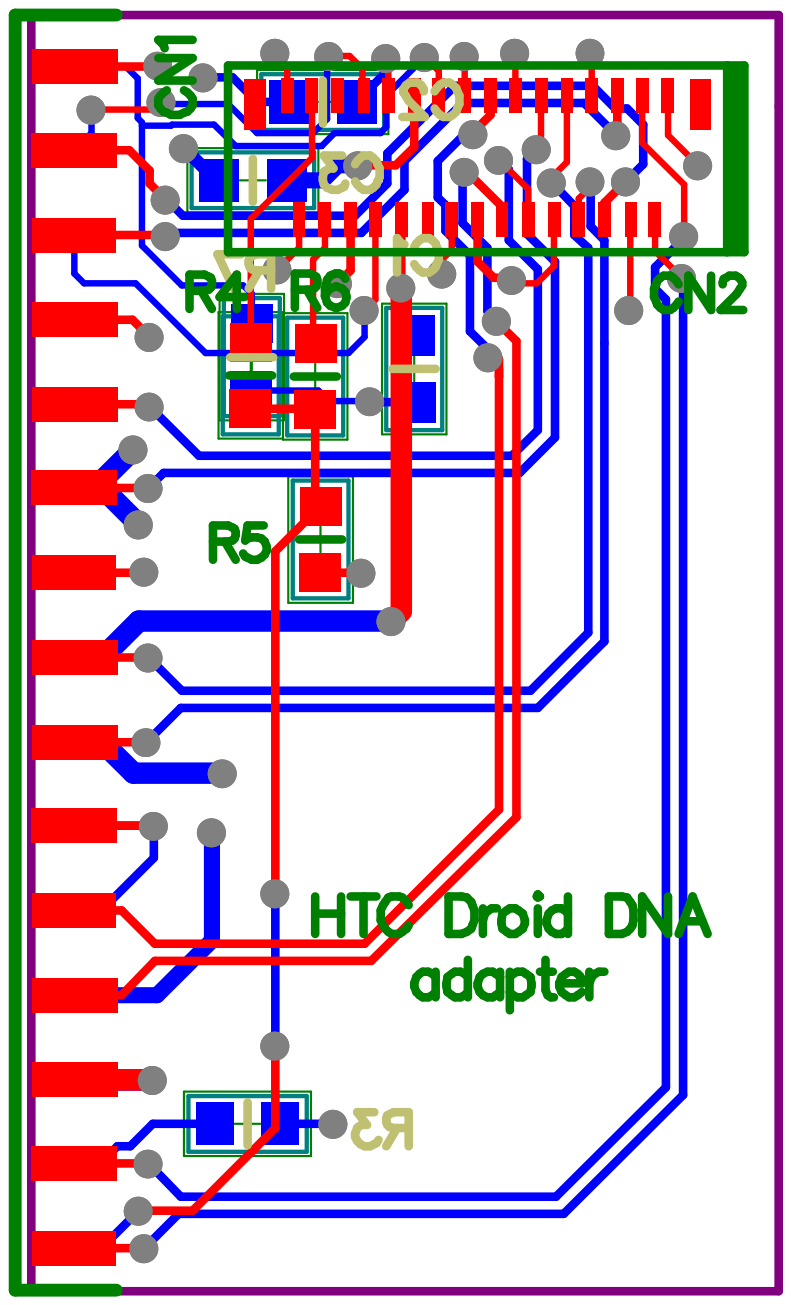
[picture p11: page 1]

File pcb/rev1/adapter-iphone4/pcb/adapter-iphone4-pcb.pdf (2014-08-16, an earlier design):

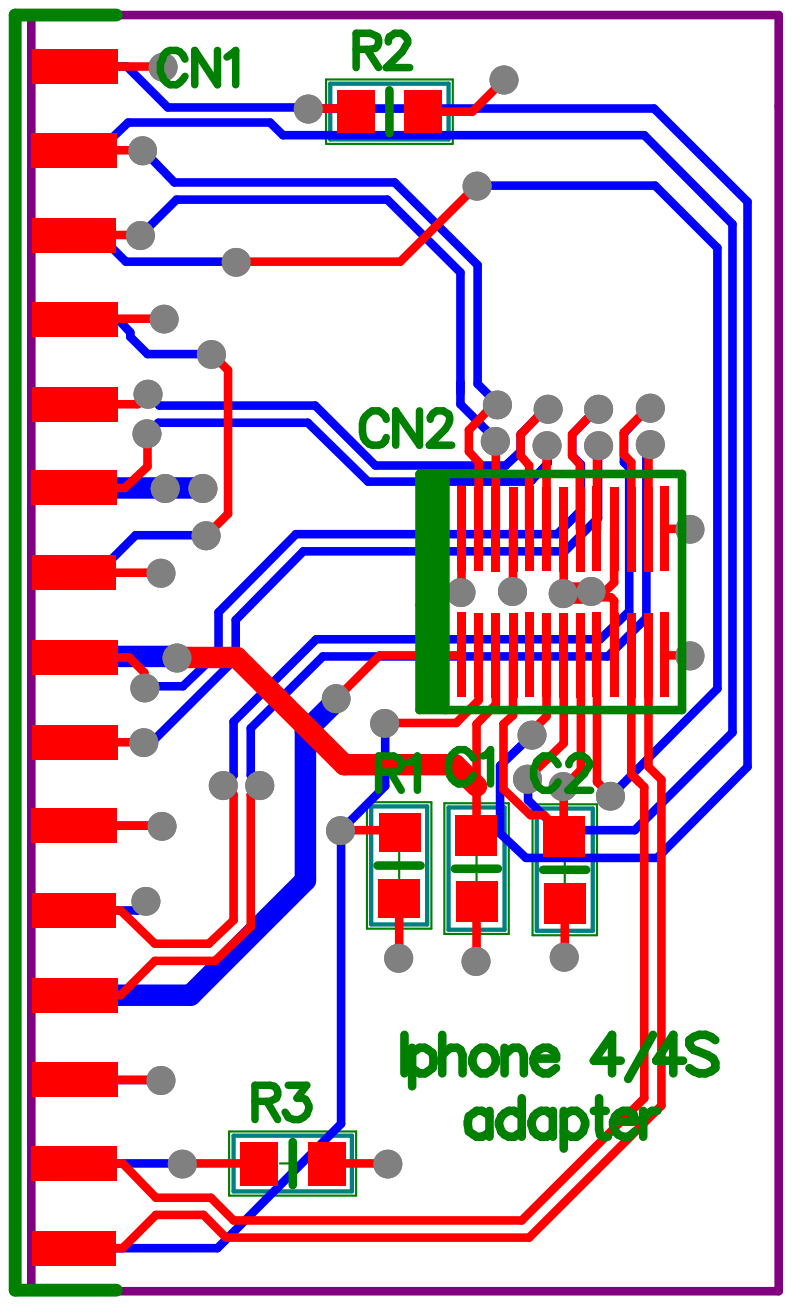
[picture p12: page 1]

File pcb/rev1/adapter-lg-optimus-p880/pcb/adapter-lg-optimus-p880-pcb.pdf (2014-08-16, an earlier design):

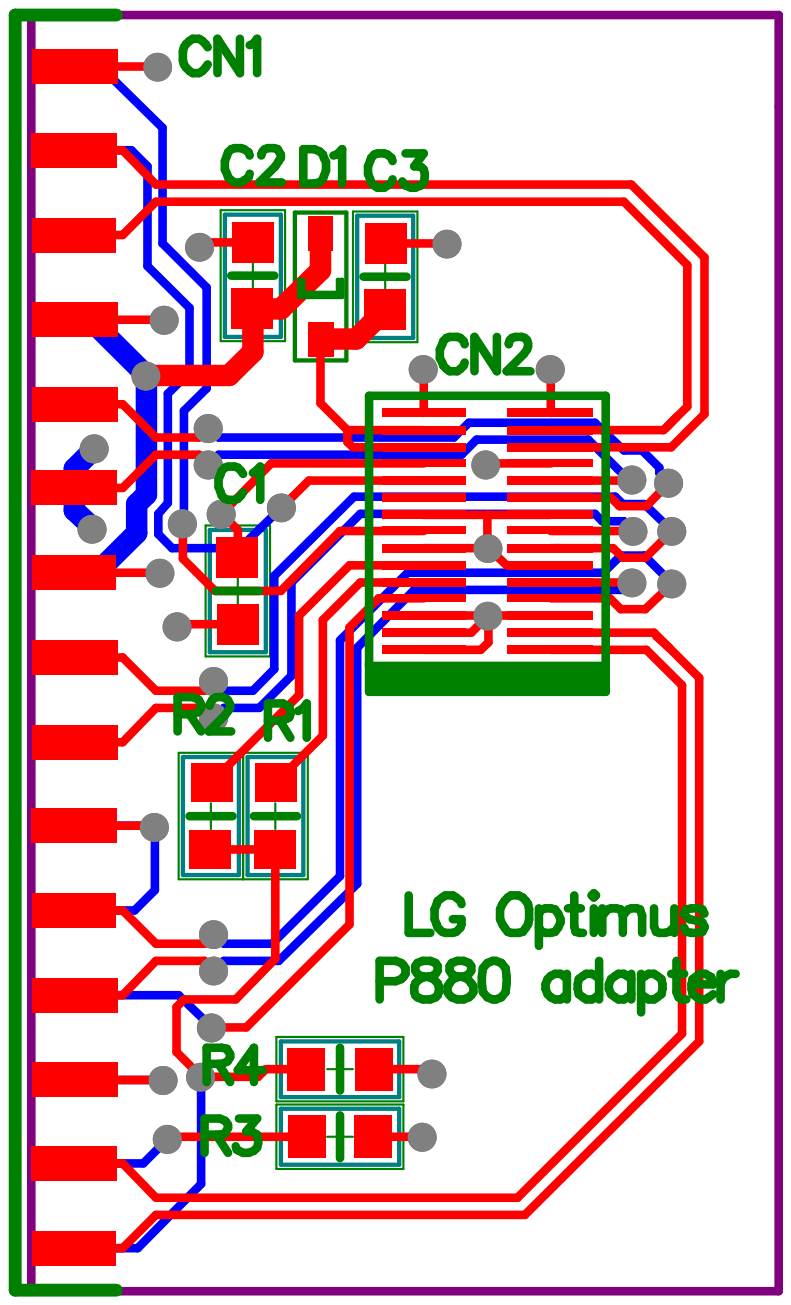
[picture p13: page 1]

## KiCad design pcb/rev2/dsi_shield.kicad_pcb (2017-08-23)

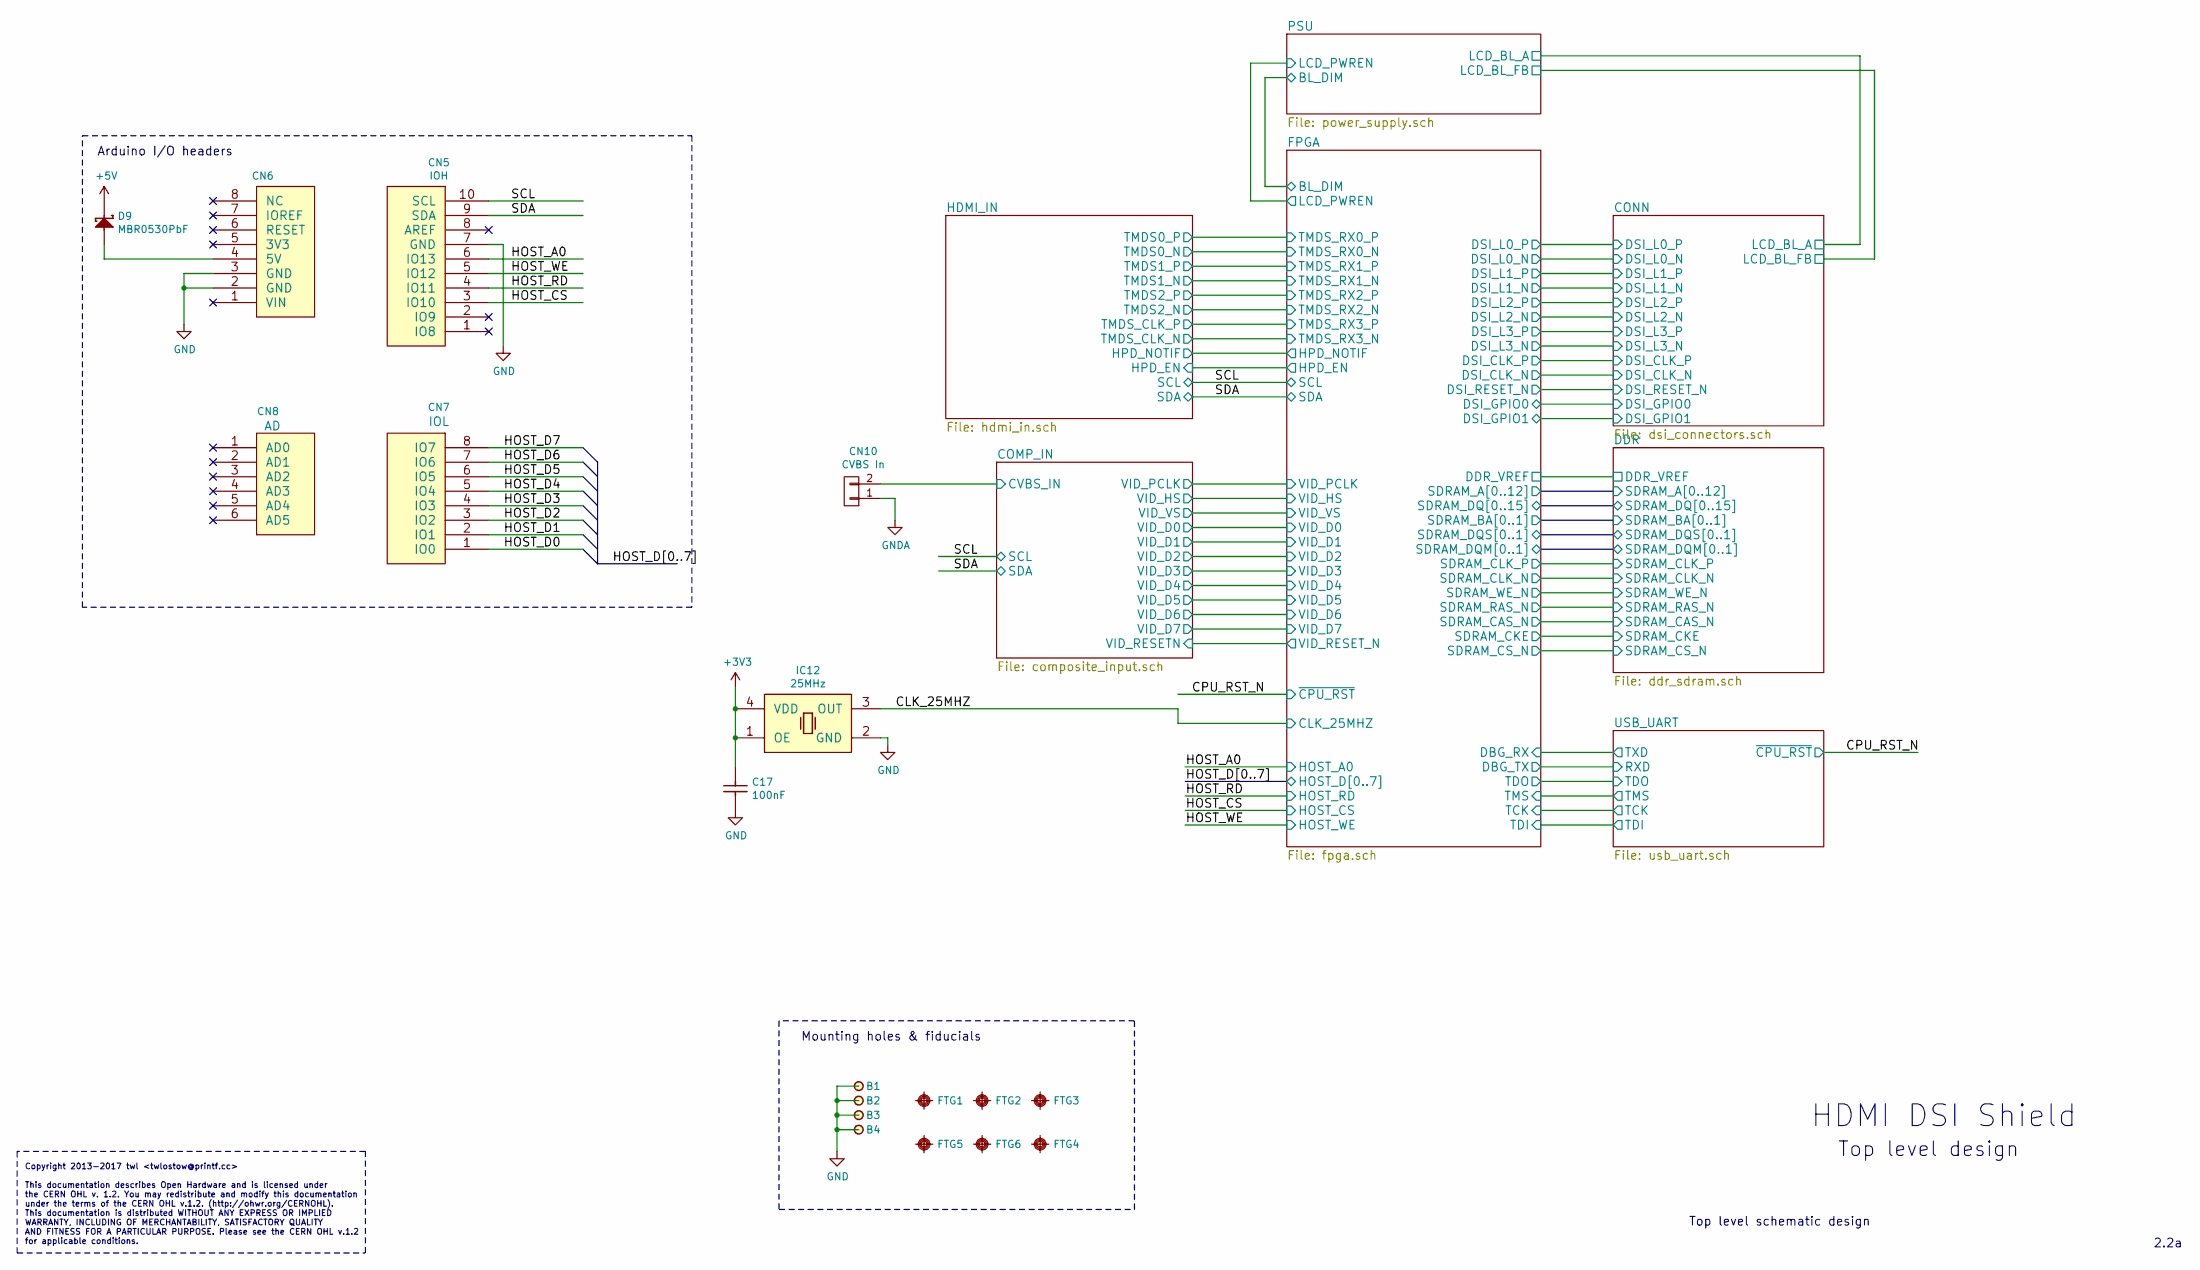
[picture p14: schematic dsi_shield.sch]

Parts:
B1, B2, B3, B4: PLATED_HOLE2.0_PAD3.5; c350h200; Part Number PLATED_HOLE2.0_PAD3.5
C17: CC0603_100NF_100V_10%_X7R; CAPC1608X90N; Voltage 100V; Tolerance ±10%; Part Number CC0603_100NF_100V_10%_X7R
CN5: IOH; Pin_Header_Straight_1x10
CN6: POWER_UNO; Pin_Header_Straight_1x08
CN7: IOL; Pin_Header_Straight_1x08
CN8: AD; Pin_Header_Straight_1x06
CN10: CVBS In; Pin_Header_Straight_1x02
D9: MBR0530PbF; SOD3715X145N; Voltage 30V; Part Number MBR0530PbF
FTG1, FTG2, FTG3, FTG4, FTG5, FTG6: FIDUCIAL_TARGET_S100-200; FIDUCIAL_TOP_S100-200; Part Number FIDUCIAL_TARGET_S100-200
IC12: OSC_25MHZ_PERICOM_FNETHE025; OSC_PERICOM_FNETHE025; Part Number OSC_25MHZ_PERICOM_FNETHE025

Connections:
+5V: D9.1 (C); also elsewhere on the board
/CLK_25MHZ: IC12.3 (OUT); also elsewhere on the board
/COMP_IN/CVBS_IN: CN10.2; also elsewhere on the board
/HOST_A0: CN5.6 (IO13); also elsewhere on the board
/HOST_CS: CN5.3 (IO10); also elsewhere on the board
/HOST_D0: CN7.1 (IO0); also elsewhere on the board
/HOST_D1: CN7.2 (IO1); also elsewhere on the board
/HOST_D2: CN7.3 (IO2); also elsewhere on the board
/HOST_D3: CN7.4 (IO3); also elsewhere on the board
/HOST_D4: CN7.5 (IO4); also elsewhere on the board
/HOST_D5: CN7.6 (IO5); also elsewhere on the board
/HOST_D6: CN7.7 (IO6); also elsewhere on the board
/HOST_D7: CN7.8 (IO7); also elsewhere on the board
/HOST_RD: CN5.4 (IO11); also elsewhere on the board
/HOST_WE: CN5.5 (IO12); also elsewhere on the board
/SCL: CN5.10 (SCL); also elsewhere on the board
/SDA: CN5.9 (SDA); also elsewhere on the board
GND: B1.1, B2.1, B3.1, B4.1, C17.2, CN5.7 (GND), CN6.2 (GND), CN6.3 (GND), IC12.2 (GND); also elsewhere on the board
GNDA: CN10.1; also elsewhere on the board
unnamed: CN6.4 (5V), D9.2 (A)

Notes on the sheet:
Copyright 2013-2017 twl <twlostow@printf.cc> This documentation describes Open Hardware and is licensed under the CERN OHL v. 1.2. You may redistribute and modify this documentation under the terms of the CERN OHL v.1.2. (http://ohwr.org/CERNOHL). This documentation is distributed WITHOUT ANY EXPRE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
HDMI DSI Shield
Top level design
2.2a
Top level schematic design
Mounting holes & fiducials
Arduino I/O headers

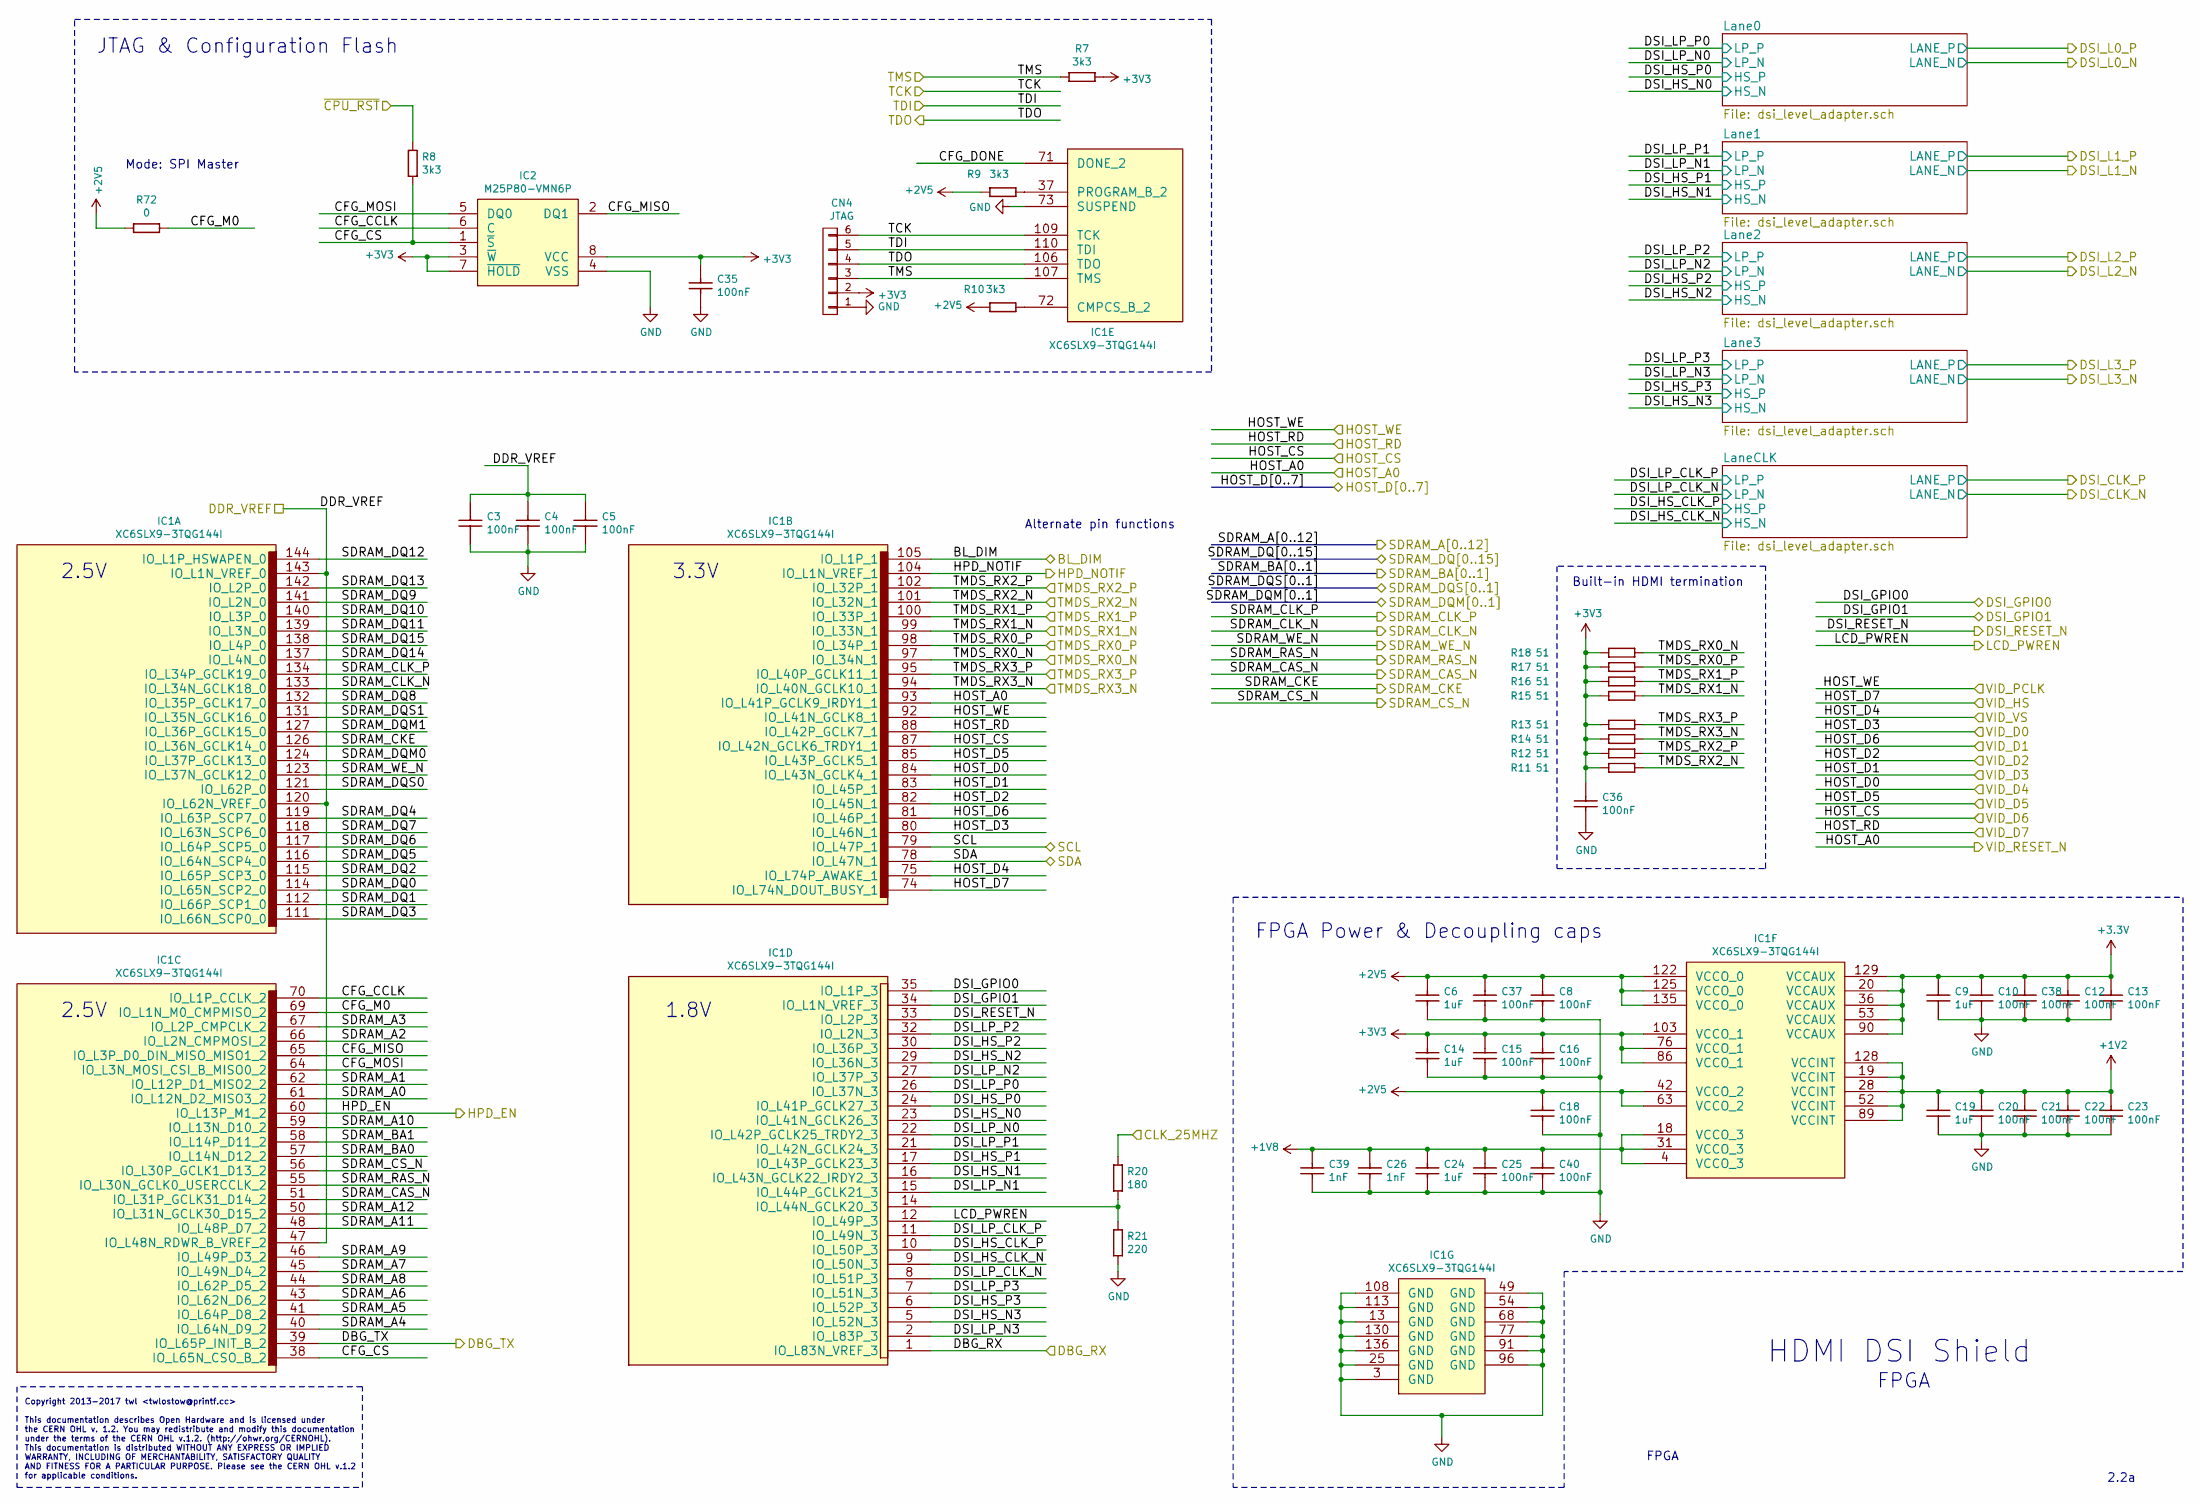
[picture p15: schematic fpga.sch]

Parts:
C3, C4, C5, C8, C10, C12, C13, C15, C16, C18, C20, C21, C22, C23, C25, C35, C36, C37, C38, C40: CC0603_100NF_50V_10%_X7R; CAPC1608X87N; Voltage 50V; Tolerance ±10%; Part Number CC0603_100NF_50V_10%_X7R
C6, C9, C14, C19, C24: CC0603_1UF_50V_10%_X5R; CAPC1608X87N; Voltage 50V; Tolerance ±10%; Part Number CC0603_1UF_50V_10%_X5R
C26, C39: CC0603_1NF_50V_5%_NP0; CAPC1608X90N; Voltage 50V; Tolerance ±5%; Part Number CC0603_1NF_50V_5%_NP0
CN4: JTAG; Pin_Header_Straight_1x06
IC1: XC6SLX9-3TQG144I; QFP50P2200X2200X160-144N; Part Number XC6SLX9-3TQG144I
IC2: M25P80-VMN6P; SOIC127P600X175-8N; Part Number M25P80-VMN6P
R7, R8, R9, R10: R0603_3K3_1%_0.1W_100PPM; RESC1608X55N; Voltage ~~; Tolerance ±1%; Part Number R0603_3K3_1%_0.1W_100PPM
R11, R12, R13, R14, R15, R16, R17, R18: R0603_51R_1%_0.1W_100PPM; RESC1608X55N; Voltage ~~; Tolerance ±1%; Part Number R0603_51R_1%_0.1W_100PPM
R20: R0603_180R_1%_0.1W_100PPM; RESC1608X55N; Voltage ~~; Tolerance ±1%; Part Number R0603_180R_1%_0.1W_100PPM
R21: R0603_220R_1%_0.1W_100PPM; RESC1608X55N; Voltage ~~; Tolerance ±1%; Part Number R0603_220R_1%_0.1W_100PPM
R72: R0603_0R_JUMPER; RESC1608X55N; Voltage ~~; Tolerance ~~; Part Number R0603_0R_JUMPER

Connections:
+1V2: C19.1, C20.1, C21.1, C22.1, C23.1, IC1.19 (VCCINT), IC1.28 (VCCINT), IC1.52 (VCCINT), IC1.89 (VCCINT), IC1.128 (VCCINT); also elsewhere on the board
+1V8: C24.1, C25.1, C26.1, C39.1, C40.1, IC1.4 (VCCO_3), IC1.18 (VCCO_3), IC1.31 (VCCO_3); also elsewhere on the board
+2V5: C6.1, C8.1, C18.1, C37.1, IC1.42 (VCCO_2), IC1.63 (VCCO_2), IC1.122 (VCCO_0), IC1.125 (VCCO_0), IC1.135 (VCCO_0), R9.2, R10.2, R72.1; also elsewhere on the board
/CLK_25MHZ: R20.1; also elsewhere on the board
/CONN/DSI_GPIO0: IC1.35 (IO_L1P_3); also elsewhere on the board
/CONN/DSI_GPIO1: IC1.34 (IO_L1N_VREF_3); also elsewhere on the board
/CONN/DSI_RESET_N: IC1.33 (IO_L2P_3); also elsewhere on the board
/CPU_RST_N: R8.2; also elsewhere on the board
/DDR/DDR_VREF: C3.1, C4.1, C5.1, IC1.47 (IO_L48N_RDWR_B_VREF_2), IC1.120 (IO_L62N_VREF_0), IC1.143 (IO_L1N_VREF_0); also elsewhere on the board
/DDR/SDRAM_A0: IC1.61 (IO_L12N_D2_MISO3_2); also elsewhere on the board
/DDR/SDRAM_A1: IC1.62 (IO_L12P_D1_MISO2_2); also elsewhere on the board
/DDR/SDRAM_A2: IC1.66 (IO_L2N_CMPMOSI_2); also elsewhere on the board
/DDR/SDRAM_A3: IC1.67 (IO_L2P_CMPCLK_2); also elsewhere on the board
/DDR/SDRAM_A4: IC1.40 (IO_L64N_D9_2); also elsewhere on the board
/DDR/SDRAM_A5: IC1.41 (IO_L64P_D8_2); also elsewhere on the board
/DDR/SDRAM_A6: IC1.43 (IO_L62N_D6_2); also elsewhere on the board
/DDR/SDRAM_A7: IC1.45 (IO_L49N_D4_2); also elsewhere on the board
/DDR/SDRAM_A8: IC1.44 (IO_L62P_D5_2); also elsewhere on the board
/DDR/SDRAM_A9: IC1.46 (IO_L49P_D3_2); also elsewhere on the board
/DDR/SDRAM_A10: IC1.59 (IO_L13N_D10_2); also elsewhere on the board
/DDR/SDRAM_A11: IC1.48 (IO_L48P_D7_2); also elsewhere on the board
/DDR/SDRAM_A12: IC1.50 (IO_L31N_GCLK30_D15_2); also elsewhere on the board
/DDR/SDRAM_BA0: IC1.57 (IO_L14N_D12_2); also elsewhere on the board
/DDR/SDRAM_BA1: IC1.58 (IO_L14P_D11_2); also elsewhere on the board
/DDR/SDRAM_CAS_N: IC1.51 (IO_L31P_GCLK31_D14_2); also elsewhere on the board
/DDR/SDRAM_CKE: IC1.126 (IO_L36N_GCLK14_0); also elsewhere on the board
/DDR/SDRAM_CLK_N: IC1.133 (IO_L34N_GCLK18_0); also elsewhere on the board
/DDR/SDRAM_CLK_P: IC1.134 (IO_L34P_GCLK19_0); also elsewhere on the board
/DDR/SDRAM_CS_N: IC1.56 (IO_L30P_GCLK1_D13_2); also elsewhere on the board
/DDR/SDRAM_DQ0: IC1.114 (IO_L65N_SCP2_0); also elsewhere on the board
/DDR/SDRAM_DQ1: IC1.112 (IO_L66P_SCP1_0); also elsewhere on the board
/DDR/SDRAM_DQ2: IC1.115 (IO_L65P_SCP3_0); also elsewhere on the board
/DDR/SDRAM_DQ3: IC1.111 (IO_L66N_SCP0_0); also elsewhere on the board
/DDR/SDRAM_DQ4: IC1.119 (IO_L63P_SCP7_0); also elsewhere on the board
/DDR/SDRAM_DQ5: IC1.116 (IO_L64N_SCP4_0); also elsewhere on the board
/DDR/SDRAM_DQ6: IC1.117 (IO_L64P_SCP5_0); also elsewhere on the board
/DDR/SDRAM_DQ7: IC1.118 (IO_L63N_SCP6_0); also elsewhere on the board
/DDR/SDRAM_DQ8: IC1.132 (IO_L35P_GCLK17_0); also elsewhere on the board
/DDR/SDRAM_DQ9: IC1.141 (IO_L2N_0); also elsewhere on the board
/DDR/SDRAM_DQ10: IC1.140 (IO_L3P_0); also elsewhere on the board
/DDR/SDRAM_DQ11: IC1.139 (IO_L3N_0); also elsewhere on the board
/DDR/SDRAM_DQ12: IC1.144 (IO_L1P_HSWAPEN_0); also elsewhere on the board
/DDR/SDRAM_DQ13: IC1.142 (IO_L2P_0); also elsewhere on the board
/DDR/SDRAM_DQ14: IC1.137 (IO_L4N_0); also elsewhere on the board
/DDR/SDRAM_DQ15: IC1.138 (IO_L4P_0); also elsewhere on the board
/DDR/SDRAM_DQM0: IC1.124 (IO_L37P_GCLK13_0); also elsewhere on the board
/DDR/SDRAM_DQM1: IC1.127 (IO_L36P_GCLK15_0); also elsewhere on the board
/DDR/SDRAM_DQS0: IC1.121 (IO_L62P_0); also elsewhere on the board
/DDR/SDRAM_DQS1: IC1.131 (IO_L35N_GCLK16_0); also elsewhere on the board
/DDR/SDRAM_RAS_N: IC1.55 (IO_L30N_GCLK0_USERCCLK_2); also elsewhere on the board
/DDR/SDRAM_WE_N: IC1.123 (IO_L37N_GCLK12_0); also elsewhere on the board
/FPGA/BL_DIM: IC1.105 (IO_L1P_1); also elsewhere on the board
/FPGA/CFG_CCLK: IC1.70 (IO_L1P_CCLK_2), IC2.6 (C)
/FPGA/CFG_CS: IC1.38 (IO_L65N_CSO_B_2), IC2.1 (~S), R8.1
/FPGA/CFG_DONE: IC1.71 (DONE_2)
/FPGA/CFG_M0: IC1.69 (IO_L1N_M0_CMPMISO_2), R72.2
/FPGA/CFG_MISO: IC1.65 (IO_L3P_D0_DIN_MISO_MISO1_2), IC2.2 (DQ1)
/FPGA/CFG_MOSI: IC1.64 (IO_L3N_MOSI_CSI_B_MISO0_2), IC2.5 (DQ0)
/FPGA/DBG_RX: IC1.1 (IO_L83N_VREF_3); also elsewhere on the board
/FPGA/DBG_TX: IC1.39 (IO_L65P_INIT_B_2); also elsewhere on the board
/FPGA/DSI_HS_CLK_N: IC1.9 (IO_L50N_3); also elsewhere on the board
/FPGA/DSI_HS_CLK_P: IC1.10 (IO_L50P_3); also elsewhere on the board
/FPGA/DSI_HS_N0: IC1.23 (IO_L41N_GCLK26_3); also elsewhere on the board
/FPGA/DSI_HS_N1: IC1.16 (IO_L43N_GCLK22_IRDY2_3); also elsewhere on the board
/FPGA/DSI_HS_N2: IC1.29 (IO_L36N_3); also elsewhere on the board
/FPGA/DSI_HS_N3: IC1.5 (IO_L52N_3); also elsewhere on the board
/FPGA/DSI_HS_P0: IC1.24 (IO_L41P_GCLK27_3); also elsewhere on the board
/FPGA/DSI_HS_P1: IC1.17 (IO_L43P_GCLK23_3); also elsewhere on the board
/FPGA/DSI_HS_P2: IC1.30 (IO_L36P_3); also elsewhere on the board
/FPGA/DSI_HS_P3: IC1.6 (IO_L52P_3); also elsewhere on the board
/FPGA/DSI_LP_CLK_N: IC1.8 (IO_L51P_3); also elsewhere on the board
/FPGA/DSI_LP_CLK_P: IC1.11 (IO_L49N_3); also elsewhere on the board
/FPGA/DSI_LP_N0: IC1.22 (IO_L42P_GCLK25_TRDY2_3); also elsewhere on the board
/FPGA/DSI_LP_N1: IC1.15 (IO_L44P_GCLK21_3); also elsewhere on the board
/FPGA/DSI_LP_N2: IC1.27 (IO_L37P_3); also elsewhere on the board
/FPGA/DSI_LP_N3: IC1.2 (IO_L83P_3); also elsewhere on the board
/FPGA/DSI_LP_P0: IC1.26 (IO_L37N_3); also elsewhere on the board
/FPGA/DSI_LP_P1: IC1.21 (IO_L42N_GCLK24_3); also elsewhere on the board
/FPGA/DSI_LP_P2: IC1.32 (IO_L2N_3); also elsewhere on the board
/FPGA/DSI_LP_P3: IC1.7 (IO_L51N_3); also elsewhere on the board
/FPGA/HPD_EN: IC1.60 (IO_L13P_M1_2); also elsewhere on the board
/FPGA/HPD_NOTIF: IC1.104 (IO_L1N_VREF_1); also elsewhere on the board
/FPGA/LCD_PWREN: IC1.12 (IO_L49P_3); also elsewhere on the board
/FPGA/TCK: CN4.6, IC1.109 (TCK); also elsewhere on the board
/FPGA/TDI: CN4.5, IC1.110 (TDI); also elsewhere on the board
/FPGA/TDO: CN4.4, IC1.106 (TDO); also elsewhere on the board
/FPGA/TMS: CN4.3, IC1.107 (TMS), R7.2; also elsewhere on the board
/HDMI_IN/TMDS0_N: IC1.97 (IO_L34N_1), R18.2; also elsewhere on the board
/HDMI_IN/TMDS0_P: IC1.98 (IO_L34P_1), R17.2; also elsewhere on the board
/HDMI_IN/TMDS1_N: IC1.99 (IO_L33N_1), R15.2; also elsewhere on the board
/HDMI_IN/TMDS1_P: IC1.100 (IO_L33P_1), R16.2; also elsewhere on the board
/HDMI_IN/TMDS2_N: IC1.101 (IO_L32N_1), R11.2; also elsewhere on the board
/HDMI_IN/TMDS2_P: IC1.102 (IO_L32P_1), R12.2; also elsewhere on the board
/HDMI_IN/TMDS_CLK_N: IC1.94 (IO_L40N_GCLK10_1), R14.2; also elsewhere on the board
/HDMI_IN/TMDS_CLK_P: IC1.95 (IO_L40P_GCLK11_1), R13.2; also elsewhere on the board
/HOST_A0: IC1.93 (IO_L41P_GCLK9_IRDY1_1); also elsewhere on the board
/HOST_CS: IC1.87 (IO_L42N_GCLK6_TRDY1_1); also elsewhere on the board
/HOST_D0: IC1.84 (IO_L43N_GCLK4_1); also elsewhere on the board
/HOST_D1: IC1.83 (IO_L45P_1); also elsewhere on the board
/HOST_D2: IC1.82 (IO_L45N_1); also elsewhere on the board
/HOST_D3: IC1.80 (IO_L46N_1); also elsewhere on the board
/HOST_D4: IC1.75 (IO_L74P_AWAKE_1); also elsewhere on the board
/HOST_D5: IC1.85 (IO_L43P_GCLK5_1); also elsewhere on the board
/HOST_D6: IC1.81 (IO_L46P_1); also elsewhere on the board
/HOST_D7: IC1.74 (IO_L74N_DOUT_BUSY_1); also elsewhere on the board
/HOST_RD: IC1.88 (IO_L42P_GCLK7_1); also elsewhere on the board
/HOST_WE: IC1.92 (IO_L41N_GCLK8_1); also elsewhere on the board
/SCL: IC1.79 (IO_L47P_1); also elsewhere on the board
/SDA: IC1.78 (IO_L47N_1); also elsewhere on the board
GND: C3.2, C4.2, C5.2, C6.2, C8.2, C9.2, C10.2, C12.2, C13.2, C14.2, C15.2, C16.2, C18.2, C19.2, C20.2, C21.2, C22.2, C23.2, C24.2, C25.2, C26.2, C35.2, C36.2, C37.2, C38.2, C39.2, C40.2, CN4.1, IC1.3 (GND), IC1.13 (GND), IC1.25 (GND), IC1.49 (GND), IC1.54 (GND), IC1.68 (GND), IC1.73 (SUSPEND), IC1.77 (GND), IC1.91 (GND), IC1.96 (GND), IC1.108 (GND), IC1.113 (GND), IC1.130 (GND), IC1.136 (GND), IC2.4 (VSS), R21.2; also elsewhere on the board
unnamed: IC1.14 (IO_L44N_GCLK20_3), R20.2, R21.1
unnamed: IC1.37 (PROGRAM_B_2), R9.1
unnamed: IC1.72 (CMPCS_B_2), R10.1

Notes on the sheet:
Mode: SPI Master
JTAG & Configuration Flash
2.5V
3.3V
1.8V
Built-in HDMI termination
FPGA Power & Decoupling caps
Copyright 2013-2017 twl <twlostow@printf.cc> This documentation describes Open Hardware and is licensed under the CERN OHL v. 1.2. You may redistribute and modify this documentation under the terms of the CERN OHL v.1.2. (http://ohwr.org/CERNOHL). This documentation is distributed WITHOUT ANY EXPRE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
Alternate pin functions
HDMI DSI Shield
FPGA
2.2a

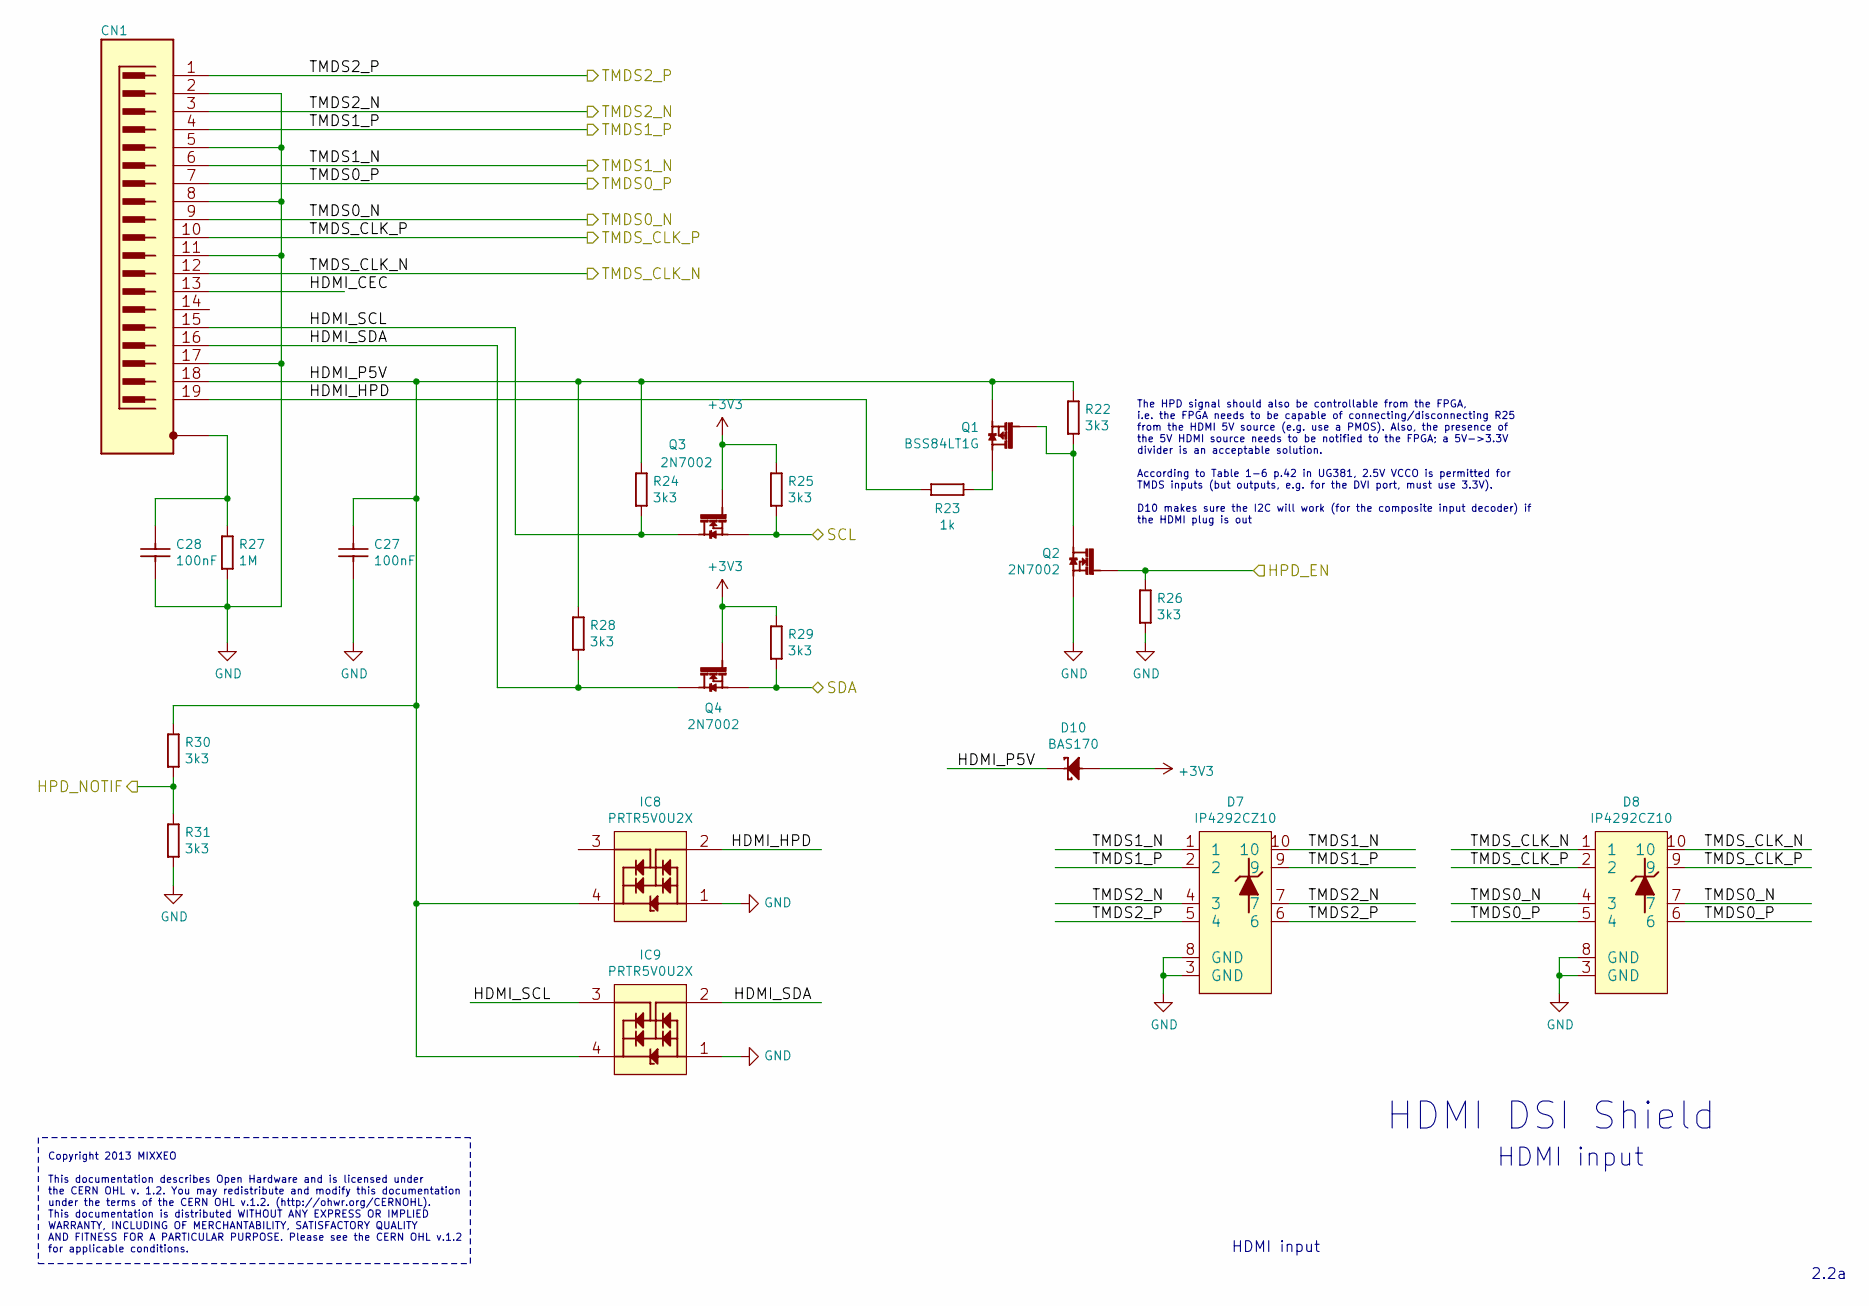
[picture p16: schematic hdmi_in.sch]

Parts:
C27, C28: CC0603_100NF_50V_10%_X7R; CAPC1608X87N; Voltage 50V; Tolerance ±10%; Part Number CC0603_100NF_50V_10%_X7R
CN1: MOLEX_500254-1927; Part Number MOLEX_500254-1927
D7, D8: IP4292CZ10; SOT1176-1
D10: BAS170; SOD2713X115N
IC8, IC9: PRTR5V0U2X; SOT190P230X110-4N; Voltage 5.5V; Part Number PRTR5V0U2X
Q1: BSS84LT1G; SOT95P240X110-3N; Part Number BSS84LT1G
Q2, Q3, Q4: 2N7002; SOT95P240X130-3N; Part Number 2N7002
R22, R24, R25, R26, R28, R29, R30, R31: R0603_3K3_1%_0.1W_100PPM; RESC1608X55N; Voltage ~~; Tolerance ±1%; Part Number R0603_3K3_1%_0.1W_100PPM
R23: R0603_1K_1%_0.1W_100PPM; RESC1608X55N; Voltage ~~; Tolerance ±1%; Part Number R0603_1K_1%_0.1W_100PPM
R27: R0603_1M_1%_0.1W_100PPM; RESC1608X55N; Voltage ~~; Tolerance ±1%; Part Number R0603_1M_1%_0.1W_100PPM

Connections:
/FPGA/HPD_EN: Q2.1 (G), R26.1; also elsewhere on the board
/FPGA/HPD_NOTIF: R30.2, R31.1; also elsewhere on the board
/HDMI_IN/HDMI_CEC: CN1.13
/HDMI_IN/HDMI_HPD: CN1.19, IC8.2 (I/O1), R23.1
/HDMI_IN/HDMI_P5V: C27.1, CN1.18, D10.1 (C), IC8.4 (VCC), IC9.4 (VCC), Q1.2 (S), R22.1, R24.1, R28.1, R30.1
/HDMI_IN/HDMI_SCL: CN1.15, IC9.3 (I/O2), Q3.3 (D), R24.2
/HDMI_IN/HDMI_SDA: CN1.16, IC9.2 (I/O1), Q4.3 (D), R28.2
/HDMI_IN/TMDS0_N: CN1.9, D8.4 (3), D8.7; also elsewhere on the board
/HDMI_IN/TMDS0_P: CN1.7, D8.5 (4), D8.6; also elsewhere on the board
/HDMI_IN/TMDS1_N: CN1.6, D7.1, D7.10; also elsewhere on the board
/HDMI_IN/TMDS1_P: CN1.4, D7.2, D7.9; also elsewhere on the board
/HDMI_IN/TMDS2_N: CN1.3, D7.4 (3), D7.7; also elsewhere on the board
/HDMI_IN/TMDS2_P: CN1.1, D7.5 (4), D7.6; also elsewhere on the board
/HDMI_IN/TMDS_CLK_N: CN1.12, D8.1, D8.10; also elsewhere on the board
/HDMI_IN/TMDS_CLK_P: CN1.10, D8.2, D8.9; also elsewhere on the board
/SCL: Q3.2 (S), R25.2; also elsewhere on the board
/SDA: Q4.2 (S), R29.2; also elsewhere on the board
GND: C27.2, C28.2, CN1.2, CN1.5, CN1.8, CN1.11, CN1.17, D7.3 (GND), D7.8 (GND), D8.3 (GND), D8.8 (GND), IC8.1 (GND), IC9.1 (GND), Q2.2 (S), R26.2, R27.2, R31.2; also elsewhere on the board
unnamed: C28.1, CN1.SHIE (SHIELD), R27.1
unnamed: Q1.1 (G), Q2.3 (D), R22.2
unnamed: Q1.3 (D), R23.2

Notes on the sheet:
The HPD signal should also be controllable from the FPGA, i.e. the FPGA needs to be capable of connecting/disconnecting R25 from the HDMI 5V source (e.g. use a PMOS). Also, the presence of the 5V HDMI source needs to be notified to the FPGA; a 5V->3.3V divider is an acceptable solution. According t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
Copyright 2013 MIXXEO This documentation describes Open Hardware and is licensed under the CERN OHL v. 1.2. You may redistribute and modify this documentation under the terms of the CERN OHL v.1.2. (http://ohwr.org/CERNOHL). This documentation is distributed WITHOUT ANY EXPRESS OR IMPLIED WARRANTY,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
HDMI DSI Shield
HDMI input
2.2a

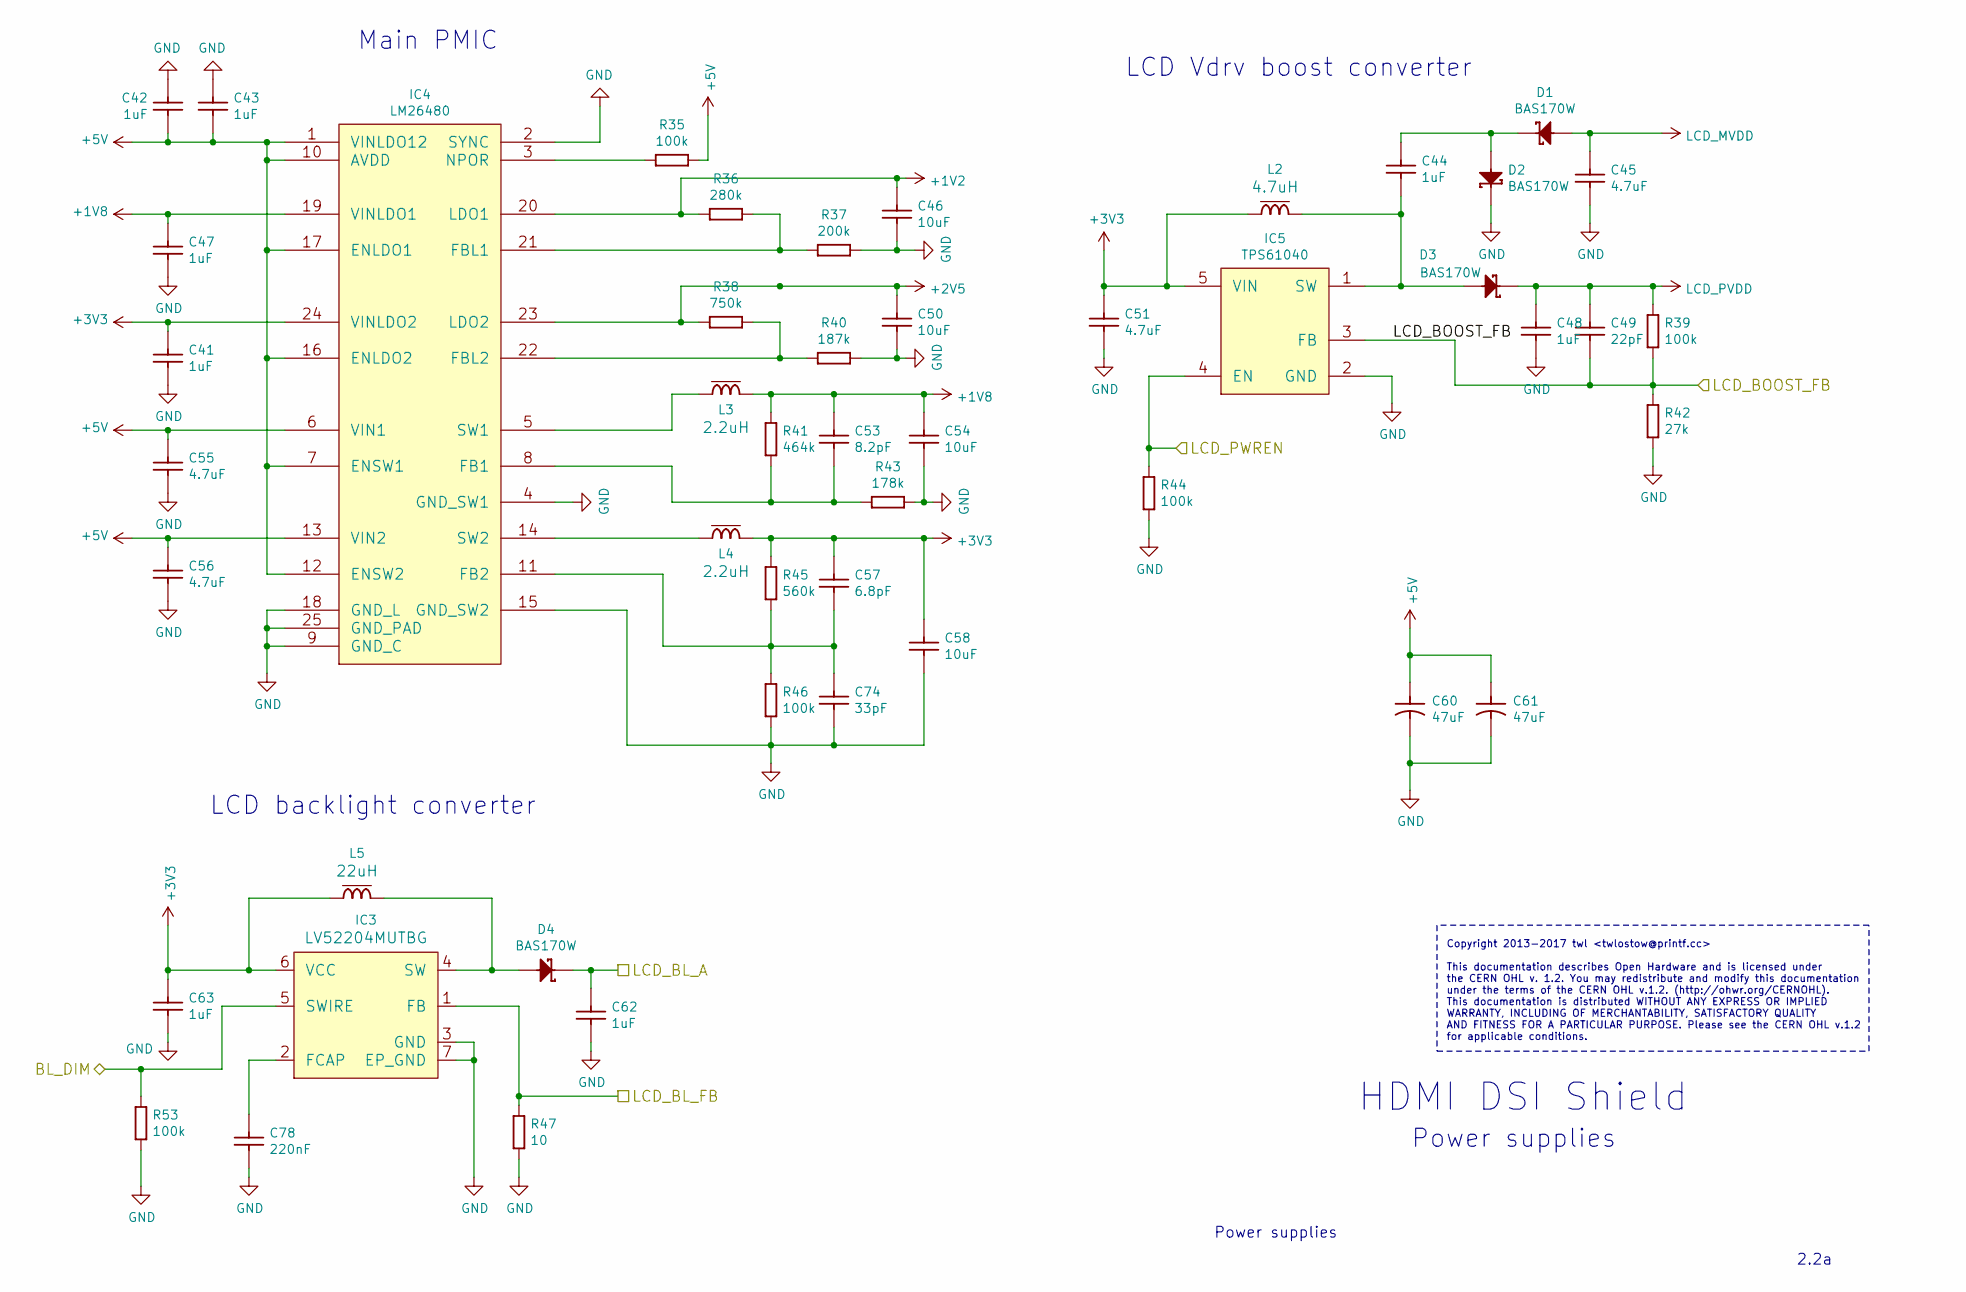
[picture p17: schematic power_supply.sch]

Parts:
C41, C42, C43, C44, C47, C48, C62, C63: CC0603_1UF_50V_10%_X5R; CAPC1608X87N; Voltage 50V; Tolerance ±10%; Part Number CC0603_1UF_50V_10%_X5R
C45, C51, C55, C56: CC0603_4.7UF_6.3V_10%_X5R; CAPC1608X87N; Voltage 6.3V; Tolerance ±10%; Part Number CC0603_4.7UF_6.3V_10%_X5R
C46, C50, C54, C58: CC0805_10UF_16V_10%_X5R; CAPC2012X135N; Voltage 16V; Tolerance ±10%; Part Number CC0805_10UF_16V_10%_X5R
C49: CC0603_22PF_50V_5%_NP0; CAPC1608X87N; Voltage 50V; Tolerance ±5%; Part Number CC0603_22PF_50V_5%_NP0
C53: CC0603_8.2PF_50V_0.5PF_NP0; CAPC1608X87N; Voltage 50V; Tolerance ±0.5pF; Part Number CC0603_8.2PF_50V_0.5PF_NP0
C57: CC0603_6.8PF_50V_0.5PF_NP0; CAPC1608X87N; Voltage 50V; Tolerance ±0.5pF; Part Number CC0603_6.8PF_50V_0.5PF_NP0
C60, C61: CTE3528-21_47UF_6.3V_10%_LESR0250; CAPMP3528X210N; Voltage 6.3V; Tolerance ±10%; Part Number CTE3528-21_47UF_6.3V_10%_LESR0250
C74: CC0603_33PF_50V_5%_NP0; CAPC1608X87N; Voltage 50V; Tolerance ±5%; Part Number CC0603_33PF_50V_5%_NP0
C78: CC0603_220NF_10V_10%_X7R; CAPC1608X87N; Voltage 10V; Tolerance ±10%; Part Number CC0603_220NF_10V_10%_X7R
D1, D2, D3, D4: BAS170W; SOD2713X115N
IC3: LV52204MUTBG; UDFN6_2X2_065P
IC4: LM26480; QFN50P400X400X80-25N-S230
IC5: TPS61040; SOT95P275X110-5N
L2: 4.7uH; IND_PANASONIC_ELLVEG; Manufacturer Part Number DLCSM0315D-4R7-K
L3, L4: 2.2uH; IND_PANASONIC_ELLVEG; Manufacturer Part Number DLCSM0315D-2R2-K
L5: 22uH; IND_PANASONIC_ELLVEG; Manufacturer Part Number DLCSM0315D-220M-K
R35, R39, R44, R46, R53: R0603_100K_1%_0.1W_100PPM; RESC1608X55N; Voltage ~~; Tolerance ±1%; Part Number R0603_100K_1%_0.1W_100PPM
R36: R0603_280K_1%_0.1W_100PPM; RESC1608X55N; Voltage ~~; Tolerance ±1%; Part Number R0603_270K_1%_0.1W_100PPM
R37: R0603_200K_1%_0.1W_100PPM; RESC1608X55N; Voltage ~~; Tolerance ±1%; Part Number R0603_200K_1%_0.1W_100PPM
R38: R0603_750K_1%_0.1W_100PPM; RESC1608X55N; Voltage ~~; Tolerance ±1%; Part Number R0603_750K_1%_0.1W_100PPM
R40: R0603_187K_1%_0.1W_100PPM; RESC1608X55N; Voltage ~~; Tolerance ±1%; Part Number R0603_187K_1%_0.1W_100PPM
R41: R0603_464K_1%_0.1W_100PPM; RESC1608X55N; Voltage ~~; Tolerance ±1%; Part Number R0603_464K_1%_0.1W_100PPM
R42: R0603_27K_1%_0.1W_100PPM; RESC1608X55N; Voltage ~~; Tolerance ±1%; Part Number R0603_27K_1%_0.1W_100PPM
R43: R0603_178K_1%_0.1W_100PPM; RESC1608X55N; Voltage ~~; Tolerance ±1%; Part Number R0603_178K_1%_0.1W_100PPM
R45: R0603_560K_1%_0.1W_100PPM; RESC1608X55N; Voltage ~~; Tolerance ±1%; Part Number R0603_560K_1%_0.1W_100PPM
R47: R0603_10R_1%_0.1W_200PPM; RESC1608X55N; Voltage ~~; Tolerance ±1%; Part Number R0603_10R_1%_0.1W_200PPM

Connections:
+1V2: C46.1, IC4.20 (LDO1), R36.1; also elsewhere on the board
+1V8: C47.1, C53.1, C54.1, IC4.19 (VINLDO1), L3.2, R41.1; also elsewhere on the board
+2V5: C50.1, IC4.23 (LDO2), R38.1; also elsewhere on the board
+5V: C42.2, C43.2, C55.1, C56.1, C60.1, C61.1, IC4.1 (VINLDO12), IC4.6 (VIN1), IC4.7 (ENSW1), IC4.10 (AVDD), IC4.12 (ENSW2), IC4.13 (VIN2), IC4.16 (ENLDO2), IC4.17 (ENLDO1), R35.2; also elsewhere on the board
/CONN/LCD_BL_A: C62.1, D4.1 (C); also elsewhere on the board
/CONN/LCD_BL_FB: IC3.1 (FB), R47.1; also elsewhere on the board
/FPGA/BL_DIM: IC3.5 (SWIRE), R53.1; also elsewhere on the board
/FPGA/LCD_PWREN: IC5.4 (EN), R44.1; also elsewhere on the board
/PSU/LCD_BOOST_FB: C49.2, IC5.3 (FB), R39.2, R42.1
GND: C41.2, C42.1, C43.1, C45.2, C46.2, C47.2, C48.2, C50.2, C51.2, C54.2, C55.2, C56.2, C58.2, C60.2, C61.2, C62.2, C63.2, C74.2, C78.2, D2.1 (C), IC3.3 (GND), IC3.7 (EP_GND), IC4.2 (SYNC), IC4.4 (GND_SW1), IC4.9 (GND_C), IC4.15 (GND_SW2), IC4.18 (GND_L), IC4.25 (GND_PAD), IC5.2 (GND), R37.2, R40.2, R42.2, R43.2, R44.2, R46.2, R47.2, R53.2; also elsewhere on the board
LCD_MVDD: C45.1, D1.2 (A); also elsewhere on the board
LCD_PVDD: C48.1, C49.1, D3.1 (C), R39.1; also elsewhere on the board
unnamed: C44.1, D1.1 (C), D2.2 (A)
unnamed: C44.2, D3.2 (A), IC5.1 (SW), L2.2
unnamed: C53.2, IC4.8 (FB1), R41.2, R43.1
unnamed: C57.2, C74.1, IC4.11 (FB2), R45.2, R46.1
unnamed: C78.1, IC3.2 (FCAP)
unnamed: D4.2 (A), IC3.4 (SW), L5.2
unnamed: IC4.3 (NPOR), R35.1
unnamed: IC4.5 (SW1), L3.1
unnamed: IC4.14 (SW2), L4.1
unnamed: IC4.21 (FBL1), R36.2, R37.1
unnamed: IC4.22 (FBL2), R38.2, R40.1

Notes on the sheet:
Main PMIC
LCD Vdrv boost converter
Copyright 2013-2017 twl <twlostow@printf.cc> This documentation describes Open Hardware and is licensed under the CERN OHL v. 1.2. You may redistribute and modify this documentation under the terms of the CERN OHL v.1.2. (http://ohwr.org/CERNOHL). This documentation is distributed WITHOUT ANY EXPRE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
HDMI DSI Shield
Power supplies
2.2a
LCD backlight converter

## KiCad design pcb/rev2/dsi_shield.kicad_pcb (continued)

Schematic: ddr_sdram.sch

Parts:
C11, C65, C67, C71, C72, C73, C75: CC0603_100NF_100V_10%_X7R; CAPC1608X90N; Voltage 100V; Tolerance ±10%; Part Number CC0603_100NF_100V_10%_X7R
C64: CC0603_1UF_50V_10%_X5R; CAPC1608X87N; Voltage 50V; Tolerance ±10%; Part Number CC0603_1UF_50V_10%_X5R
C66, C68, C69, C70: CC0603_10NF_50V_10%_X7R; CAPC1608X87N; Voltage 50V; Tolerance ±10%; Part Number CC0603_10NF_50V_10%_X7R
IC10: MT46V32M16P-5B:F; TSOP66
R67: R0603_100R_1%_0.1W_100PPM; RESC1608X55N; Voltage ~~; Tolerance ±1%; Part Number R0603_100R_1%_0.1W_100PPM
R68, R69: R0603_1K_1%_0.1W_100PPM; RESC1608X55N; Voltage ~~; Tolerance ±1%; Part Number R0603_1K_1%_0.1W_100PPM

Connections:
+2V5: C11.1, C64.1, C65.1, C66.1, C67.1, C68.1, C69.1, C70.1, C72.1, C73.1, C75.1, IC10.1, IC10.3, IC10.9, IC10.15, IC10.18, IC10.33, IC10.55, IC10.61, R68.1; also elsewhere on the board
/DDR/DDR_VREF: C65.2, C71.1, IC10.49, R68.2, R69.1; also elsewhere on the board
/DDR/SDRAM_A0: IC10.29; also elsewhere on the board
/DDR/SDRAM_A1: IC10.30; also elsewhere on the board
/DDR/SDRAM_A2: IC10.31; also elsewhere on the board
/DDR/SDRAM_A3: IC10.32; also elsewhere on the board
/DDR/SDRAM_A4: IC10.35; also elsewhere on the board
/DDR/SDRAM_A5: IC10.36; also elsewhere on the board
/DDR/SDRAM_A6: IC10.37; also elsewhere on the board
/DDR/SDRAM_A7: IC10.38; also elsewhere on the board
/DDR/SDRAM_A8: IC10.39; also elsewhere on the board
/DDR/SDRAM_A9: IC10.40; also elsewhere on the board
/DDR/SDRAM_A10: IC10.28; also elsewhere on the board
/DDR/SDRAM_A11: IC10.41; also elsewhere on the board
/DDR/SDRAM_A12: IC10.42; also elsewhere on the board
/DDR/SDRAM_BA0: IC10.26; also elsewhere on the board
/DDR/SDRAM_BA1: IC10.27; also elsewhere on the board
/DDR/SDRAM_CAS_N: IC10.22; also elsewhere on the board
/DDR/SDRAM_CKE: IC10.44; also elsewhere on the board
/DDR/SDRAM_CLK_N: IC10.46, R67.2; also elsewhere on the board
/DDR/SDRAM_CLK_P: IC10.45, R67.1; also elsewhere on the board
/DDR/SDRAM_CS_N: IC10.24; also elsewhere on the board
/DDR/SDRAM_DQ0: IC10.2; also elsewhere on the board
/DDR/SDRAM_DQ1: IC10.4; also elsewhere on the board
/DDR/SDRAM_DQ2: IC10.5; also elsewhere on the board
/DDR/SDRAM_DQ3: IC10.7; also elsewhere on the board
/DDR/SDRAM_DQ4: IC10.8; also elsewhere on the board
/DDR/SDRAM_DQ5: IC10.10; also elsewhere on the board
/DDR/SDRAM_DQ6: IC10.11; also elsewhere on the board
/DDR/SDRAM_DQ7: IC10.13; also elsewhere on the board
/DDR/SDRAM_DQ8: IC10.54; also elsewhere on the board
/DDR/SDRAM_DQ9: IC10.56; also elsewhere on the board
/DDR/SDRAM_DQ10: IC10.57; also elsewhere on the board
/DDR/SDRAM_DQ11: IC10.59; also elsewhere on the board
/DDR/SDRAM_DQ12: IC10.60; also elsewhere on the board
/DDR/SDRAM_DQ13: IC10.62; also elsewhere on the board
/DDR/SDRAM_DQ14: IC10.63; also elsewhere on the board
/DDR/SDRAM_DQ15: IC10.65; also elsewhere on the board
/DDR/SDRAM_DQM0: IC10.20; also elsewhere on the board
/DDR/SDRAM_DQM1: IC10.47; also elsewhere on the board
/DDR/SDRAM_DQS0: IC10.16; also elsewhere on the board
/DDR/SDRAM_DQS1: IC10.51; also elsewhere on the board
/DDR/SDRAM_RAS_N: IC10.23; also elsewhere on the board
/DDR/SDRAM_WE_N: IC10.21; also elsewhere on the board
GND: C11.2, C64.2, C66.2, C67.2, C68.2, C69.2, C70.2, C71.2, C72.2, C73.2, C75.2, IC10.6, IC10.12, IC10.34, IC10.48, IC10.52, IC10.58, IC10.64, IC10.66, R69.2; also elsewhere on the board

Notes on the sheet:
Copyright 2013-2017 twl <twlostow@printf.cc> This documentation describes Open Hardware and is licensed under the CERN OHL v. 1.2. You may redistribute and modify this documentation under the terms of the CERN OHL v.1.2. (http://ohwr.org/CERNOHL). This documentation is distributed WITHOUT ANY EXPRE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
HDMI DSI Shield
DDR SDRAM
2.2a

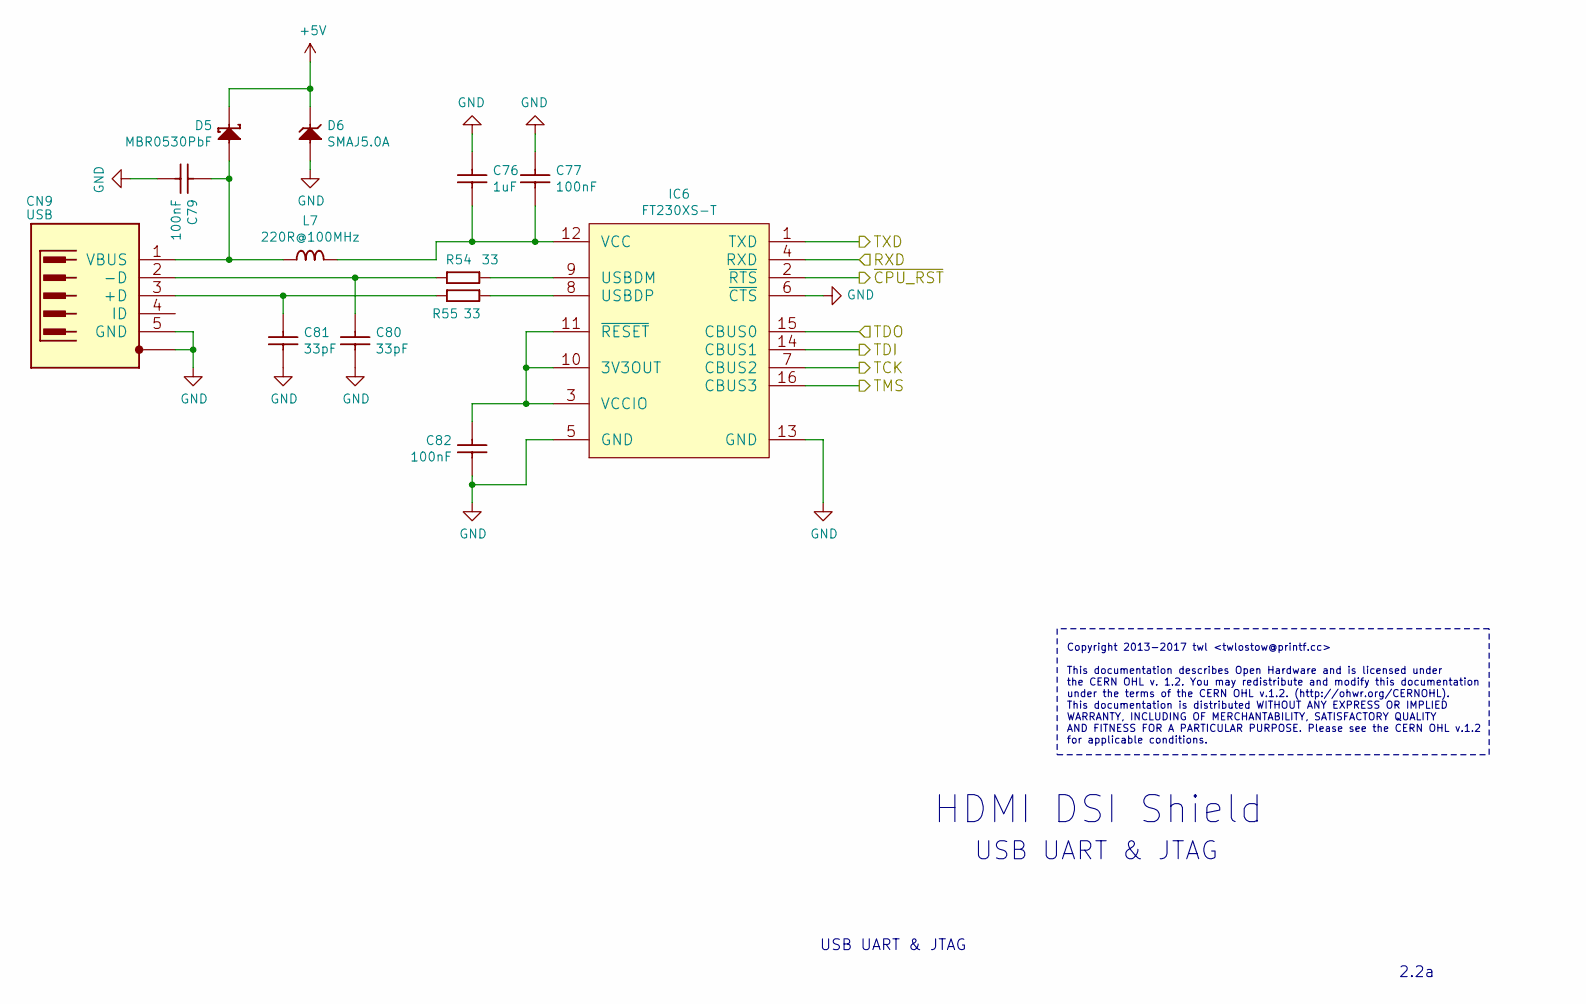
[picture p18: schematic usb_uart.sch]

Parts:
C76: CC0603_1UF_50V_10%_X5R; CAPC1608X87N; Voltage 50V; Tolerance ±10%; Part Number CC0603_1UF_50V_10%_X5R
C77, C79, C82: CC0603_100NF_100V_10%_X7R; CAPC1608X90N; Voltage 100V; Tolerance ±10%; Part Number CC0603_100NF_100V_10%_X7R
C80, C81: CC0603_33PF_50V_5%_NP0; CAPC1608X87N; Voltage 50V; Tolerance ±5%; Part Number CC0603_33PF_50V_5%_NP0
CN9: TYCO_1734035-1; Part Number TYCO_1734035-1
D5: MBR0530PbF; SOD3715X145N; Voltage 30V; Part Number MBR0530PbF
D6: SMAJ5.0A; DIOM5226X262N; Voltage 5V; Part Number SMAJ5.0A
IC6: FT230XS-T; SOP63P600X175-16N; Part Number FT230XS-T
L7: IND0805_MURATA_BLM21PG221SN1D; INDC2012X105N; Tolerance ±25%; Part Number IND0805_MURATA_BLM21PG221SN1D
R54, R55: R0603_33R_1%_0.1W_100PPM; RESC1608X55N; Voltage ~~; Tolerance ±1%; Part Number R0603_33R_1%_0.1W_100PPM

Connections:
+5V: D5.1 (C), D6.1 (C); also elsewhere on the board
/CPU_RST_N: IC6.2 (~RTS); also elsewhere on the board
/FPGA/DBG_RX: IC6.1 (TXD); also elsewhere on the board
/FPGA/DBG_TX: IC6.4 (RXD); also elsewhere on the board
/FPGA/TCK: IC6.7 (CBUS2); also elsewhere on the board
/FPGA/TDI: IC6.14 (CBUS1); also elsewhere on the board
/FPGA/TDO: IC6.15 (CBUS0); also elsewhere on the board
/FPGA/TMS: IC6.16 (CBUS3); also elsewhere on the board
GND: C76.1, C77.1, C79.2, C80.2, C81.2, C82.2, CN9.5 (GND), CN9.6 (SH), D6.2 (A), IC6.5 (GND), IC6.6 (~CTS), IC6.13 (GND); also elsewhere on the board
unnamed: C76.2, C77.2, IC6.12 (VCC), L7.2
unnamed: C79.1, CN9.1 (VBUS), D5.2 (A), L7.1
unnamed: C80.1, CN9.2 (-D), R54.1
unnamed: C81.1, CN9.3 (+D), R55.1
unnamed: C82.1, IC6.3 (VCCIO), IC6.10 (3V3OUT), IC6.11 (~RESET)
unnamed: IC6.8 (USBDP), R55.2
unnamed: IC6.9 (USBDM), R54.2

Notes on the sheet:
HDMI DSI Shield
USB UART & JTAG
2.2a
Copyright 2013-2017 twl <twlostow@printf.cc> This documentation describes Open Hardware and is licensed under the CERN OHL v. 1.2. You may redistribute and modify this documentation under the terms of the CERN OHL v.1.2. (http://ohwr.org/CERNOHL). This documentation is distributed WITHOUT ANY EXPRE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

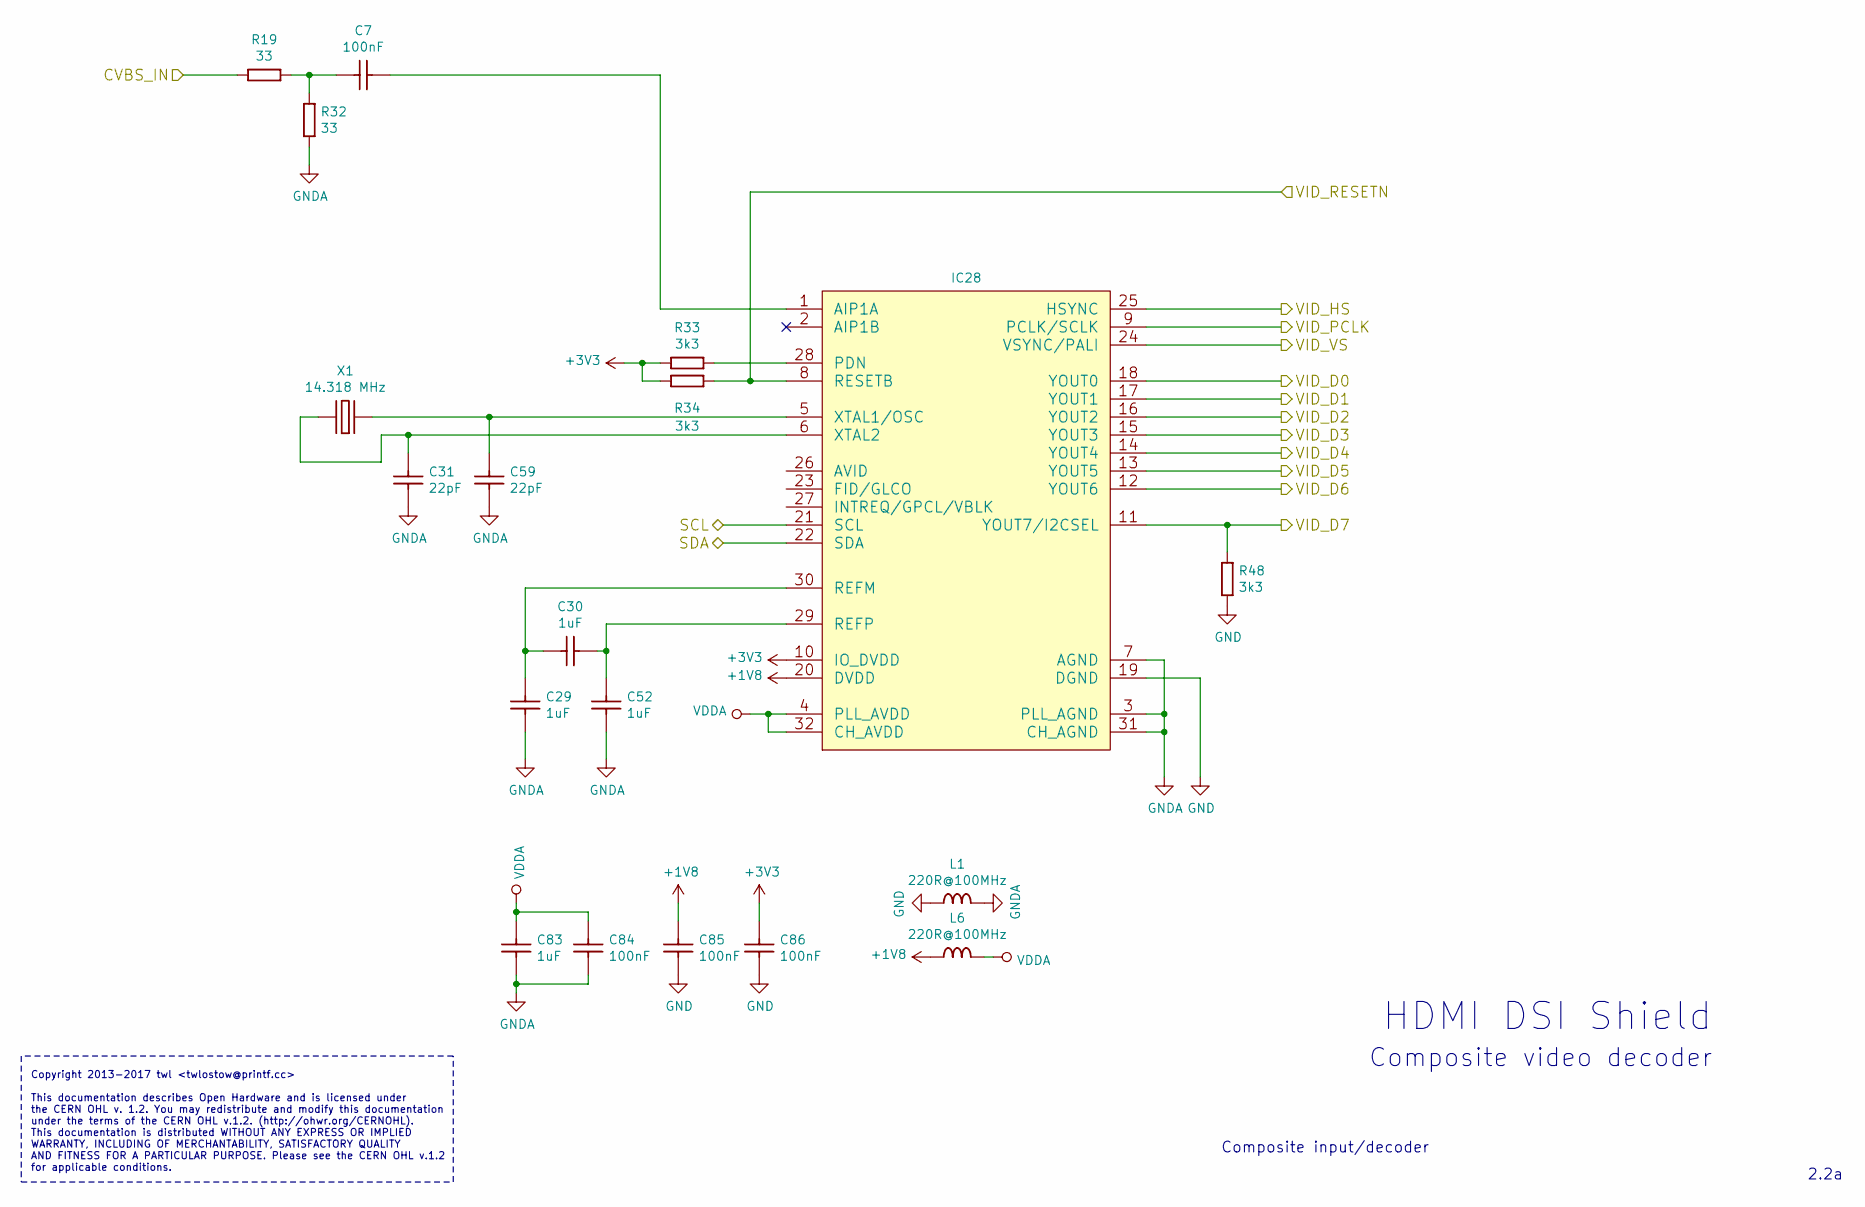
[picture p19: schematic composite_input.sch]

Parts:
C7, C84, C85, C86: CC0603_100NF_100V_10%_X7R; CAPC1608X90N; Voltage 100V; Tolerance ±10%; Part Number CC0603_100NF_100V_10%_X7R
C29, C30, C52, C83: CC0603_1UF_50V_10%_X5R; CAPC1608X87N; Voltage 50V; Tolerance ±10%; Part Number CC0603_1UF_50V_10%_X5R
C31, C59: CC0603_22PF_50V_5%_NP0; CAPC1608X87N; Voltage 50V; Tolerance ±5%; Part Number CC0603_22PF_50V_5%_NP0
IC28: TVP5150AM1PBS; TSQFP50P700X700-32L
L1, L6: IND0805_MURATA_BLM21PG221SN1D; INDC2012X105N; Tolerance ±25%; Part Number IND0805_MURATA_BLM21PG221SN1D
R19, R32: R0603_33R_1%_0.1W_100PPM; RESC1608X55N; Voltage ~~; Tolerance ±1%; Part Number R0603_33R_1%_0.1W_100PPM
R33, R34, R48: R0603_3K3_1%_0.1W_100PPM; RESC1608X55N; Voltage ~~; Tolerance ±1%; Part Number R0603_3K3_1%_0.1W_100PPM
X1: XTAL_12MHZ_TXC_7A-14.31818MAAJ-T; XTAL_TXC_7A; Part Number XTAL_12MHZ_TXC_7A-14.31818MAAJ-T

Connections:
+1V8: C85.1, IC28.20 (DVDD), L6.1; also elsewhere on the board
/COMP_IN/CVBS_IN: R19.1; also elsewhere on the board
/HOST_A0: IC28.8 (RESETB), R34.2; also elsewhere on the board
/HOST_CS: IC28.12 (YOUT6); also elsewhere on the board
/HOST_D0: IC28.14 (YOUT4); also elsewhere on the board
/HOST_D1: IC28.15 (YOUT3); also elsewhere on the board
/HOST_D2: IC28.16 (YOUT2); also elsewhere on the board
/HOST_D3: IC28.18 (YOUT0); also elsewhere on the board
/HOST_D4: IC28.24 (VSYNC/PALI); also elsewhere on the board
/HOST_D5: IC28.13 (YOUT5); also elsewhere on the board
/HOST_D6: IC28.17 (YOUT1); also elsewhere on the board
/HOST_D7: IC28.25 (HSYNC); also elsewhere on the board
/HOST_RD: IC28.11 (YOUT7/I2CSEL), R48.1; also elsewhere on the board
/HOST_WE: IC28.9 (PCLK/SCLK); also elsewhere on the board
/SCL: IC28.21 (SCL); also elsewhere on the board
/SDA: IC28.22 (SDA); also elsewhere on the board
GND: C85.2, C86.2, IC28.19 (DGND), L1.1, R48.2; also elsewhere on the board
GNDA: C29.2, C31.2, C52.1, C59.2, C83.2, C84.2, IC28.3 (PLL_AGND), IC28.7 (AGND), IC28.31 (CH_AGND), L1.2, R32.2; also elsewhere on the board
unnamed: C7.1, R19.2, R32.1
unnamed: C7.2, IC28.1 (AIP1A)
unnamed: C29.1, C30.2, IC28.30 (REFM)
unnamed: C30.1, C52.2, IC28.29 (REFP)
unnamed: C31.1, IC28.6 (XTAL2), X1.1 (OSC1)
unnamed: C59.1, IC28.5 (XTAL1/OSC), X1.2 (OSC2)
unnamed: IC28.28 (PDN), R33.2
VDDA: C83.1, C84.1, IC28.4 (PLL_AVDD), IC28.32 (CH_AVDD), L6.2

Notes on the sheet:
Copyright 2013-2017 twl <twlostow@printf.cc> This documentation describes Open Hardware and is licensed under the CERN OHL v. 1.2. You may redistribute and modify this documentation under the terms of the CERN OHL v.1.2. (http://ohwr.org/CERNOHL). This documentation is distributed WITHOUT ANY EXPRE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
HDMI DSI Shield
Composite video decoder
2.2a
Composite input/decoder

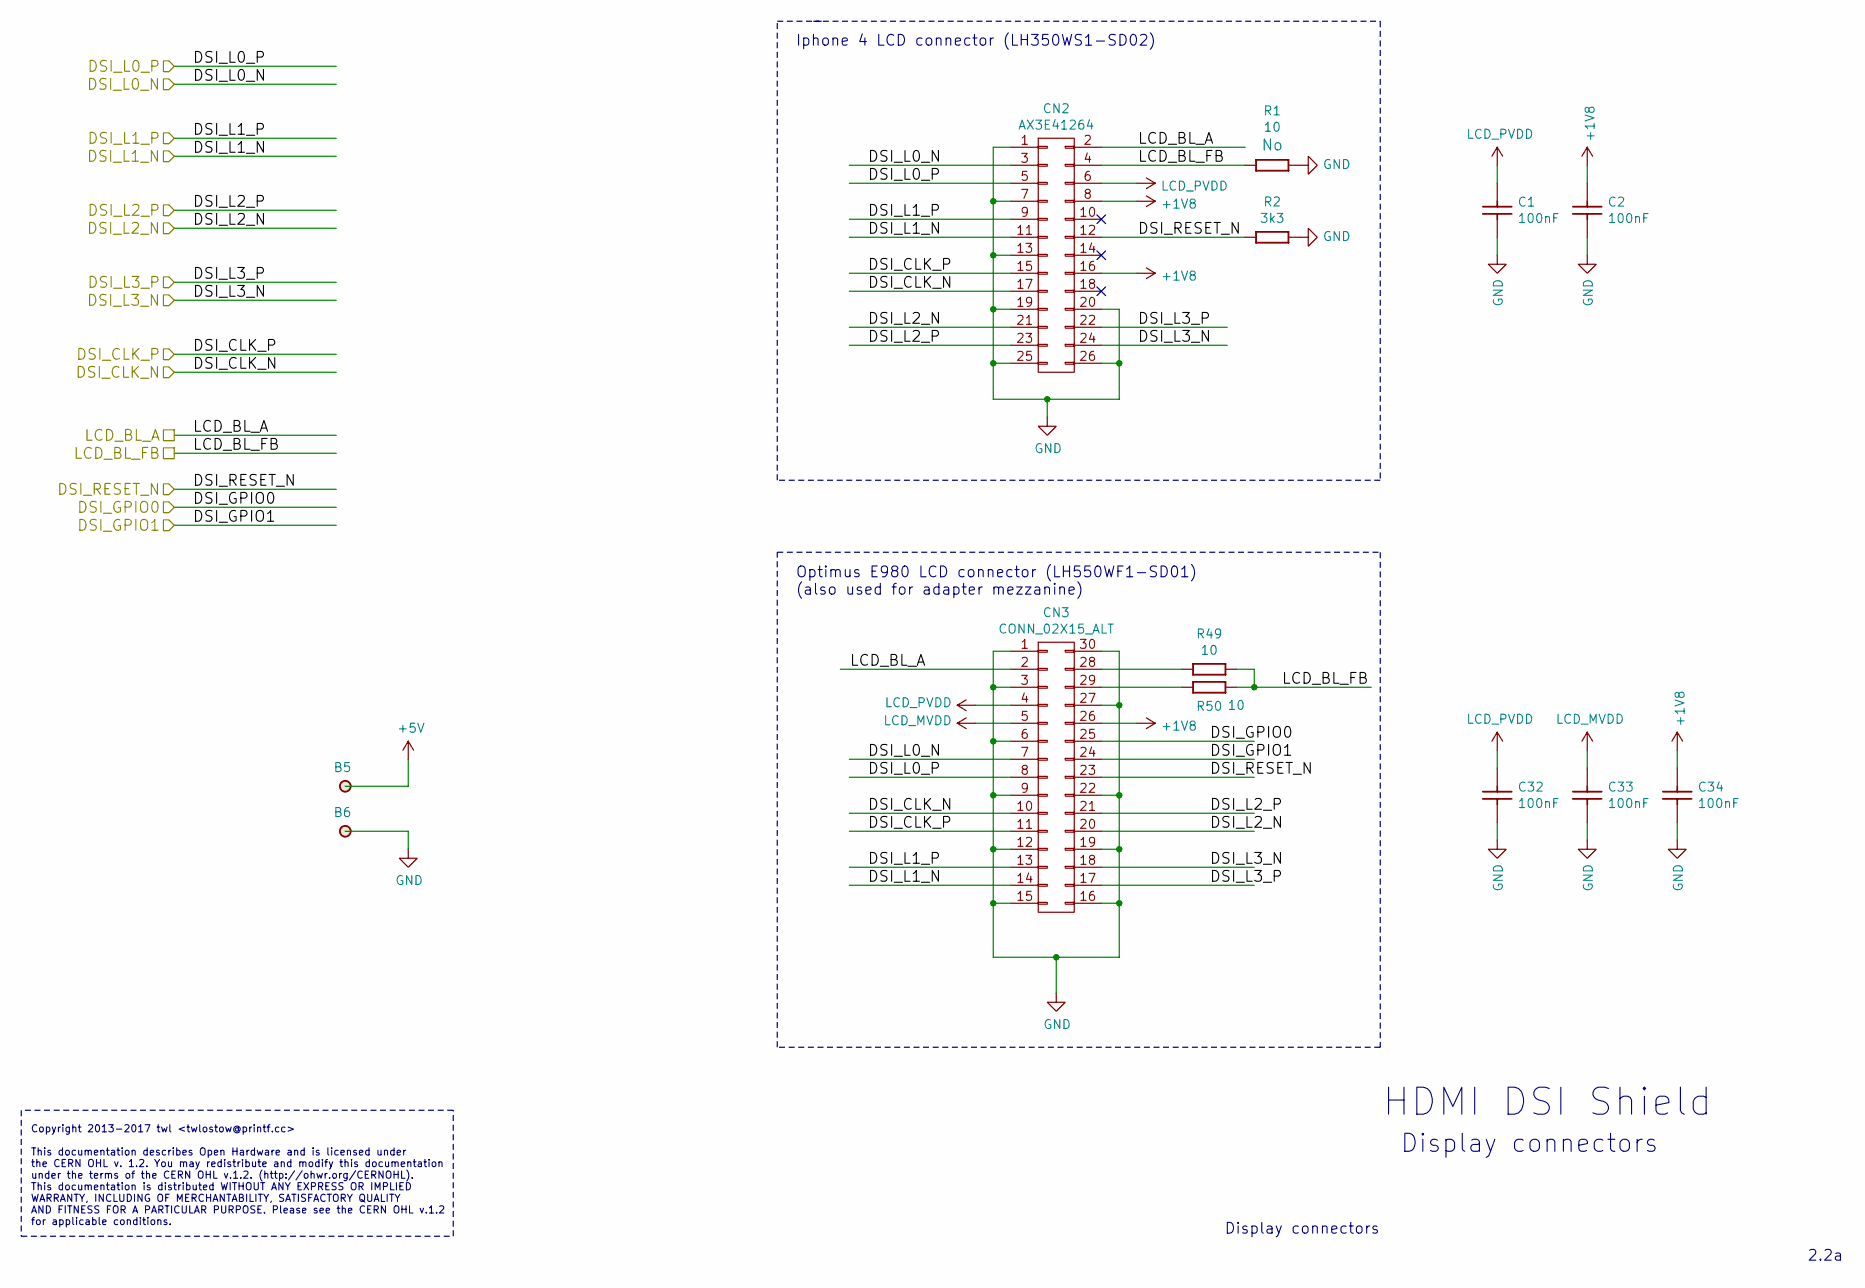
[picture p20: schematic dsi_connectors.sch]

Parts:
B5, B6: PLATED_HOLE0.8_PAD1.3; c130h80; Part Number PLATED_HOLE0.8_PAD1.3
C1, C2, C32, C33, C34: CC0603_100NF_100V_10%_X7R; CAPC1608X90N; Voltage 100V; Tolerance ±10%; Part Number CC0603_100NF_100V_10%_X7R
CN2: AX3E41264; IPHONE4_LCD_CONN
CN3: CONN_02X15_ALT; GB042-30S-E1000
R1, R49, R50: R0603_10R_1%_0.1W_200PPM; RESC1608X55N; Voltage ~~; Tolerance ±1%; Part Number R0603_10R_1%_0.1W_200PPM
R2: R0603_3K3_1%_0.1W_100PPM; RESC1608X55N; Voltage ~~; Tolerance ±1%; Part Number R0603_3K3_1%_0.1W_100PPM

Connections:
+1V8: C2.1, C34.1, CN2.8, CN2.16, CN3.26; also elsewhere on the board
+5V: B5.1; also elsewhere on the board
/CONN/DSI_CLK_N: CN2.17, CN3.10; also elsewhere on the board
/CONN/DSI_CLK_P: CN2.15, CN3.11; also elsewhere on the board
/CONN/DSI_GPIO0: CN3.25; also elsewhere on the board
/CONN/DSI_GPIO1: CN3.24; also elsewhere on the board
/CONN/DSI_L0_N: CN2.3, CN3.7; also elsewhere on the board
/CONN/DSI_L0_P: CN2.5, CN3.8; also elsewhere on the board
/CONN/DSI_L1_N: CN2.11, CN3.14; also elsewhere on the board
/CONN/DSI_L1_P: CN2.9, CN3.13; also elsewhere on the board
/CONN/DSI_L2_N: CN2.21, CN3.20; also elsewhere on the board
/CONN/DSI_L2_P: CN2.23, CN3.21; also elsewhere on the board
/CONN/DSI_L3_N: CN2.24, CN3.18; also elsewhere on the board
/CONN/DSI_L3_P: CN2.22, CN3.17; also elsewhere on the board
/CONN/DSI_RESET_N: CN2.12, CN3.23, R2.1; also elsewhere on the board
/CONN/LCD_BL_A: CN2.2, CN3.2; also elsewhere on the board
/CONN/LCD_BL_FB: CN2.4, R1.1, R49.2, R50.2; also elsewhere on the board
GND: B6.1, C1.2, C2.2, C32.2, C33.2, C34.2, CN2.1, CN2.7, CN2.13, CN2.19, CN2.20, CN2.25, CN2.26, CN3.1, CN3.3, CN3.6, CN3.9, CN3.12, CN3.15, CN3.16, CN3.19, CN3.22, CN3.27, CN3.30, R1.2, R2.2; also elsewhere on the board
LCD_MVDD: C33.1, CN3.5; also elsewhere on the board
LCD_PVDD: C1.1, C32.1, CN2.6, CN3.4; also elsewhere on the board
unnamed: CN3.28, R49.1
unnamed: CN3.29, R50.1

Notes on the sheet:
Iphone 4 LCD connector (LH350WS1-SD02)
Optimus E980 LCD connector (LH550WF1-SD01) (also used for adapter mezzanine)
HDMI DSI Shield
Display connectors
2.2a
Copyright 2013-2017 twl <twlostow@printf.cc> This documentation describes Open Hardware and is licensed under the CERN OHL v. 1.2. You may redistribute and modify this documentation under the terms of the CERN OHL v.1.2. (http://ohwr.org/CERNOHL). This documentation is distributed WITHOUT ANY EXPRE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

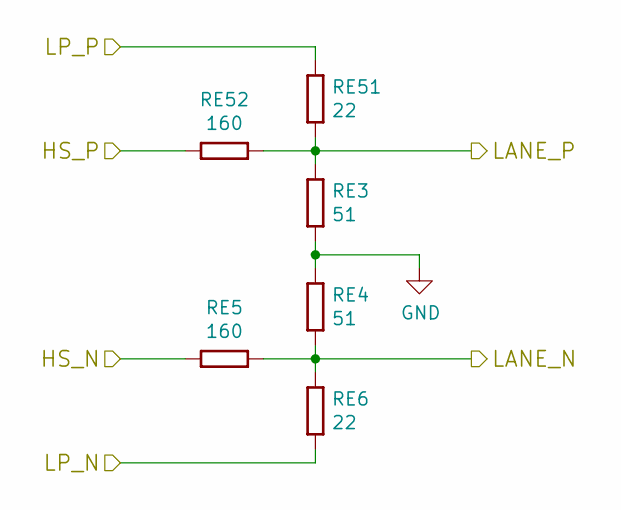
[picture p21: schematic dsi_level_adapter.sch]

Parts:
RA3, RA4: R0603_51R_1%_0.1W_100PPM; RESC1608X55N; Voltage ~~; Tolerance ±1%; Part Number R0603_51R_1%_0.1W_100PPM
RA5, RA52: R0603_160R_1%_0.1W_100PPM; RESC1608X55N; Voltage ~~; Tolerance ±1%; Part Number R0603_160R_1%_0.1W_100PPM
RA6, RA51: R0603_22R_1%_0.1W_100PPM; RESC1608X55N; Voltage ~~; Tolerance ±1%; Part Number R0603_22R_1%_0.1W_100PPM

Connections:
/CONN/DSI_L0_N: RA4.2, RA5.1, RA6.1; also elsewhere on the board
/CONN/DSI_L0_P: RA3.1, RA51.2, RA52.1; also elsewhere on the board
/FPGA/DSI_HS_N0: RA5.2; also elsewhere on the board
/FPGA/DSI_HS_P0: RA52.2; also elsewhere on the board
/FPGA/DSI_LP_N0: RA6.2; also elsewhere on the board
/FPGA/DSI_LP_P0: RA51.1; also elsewhere on the board
GND: RA3.2, RA4.1; also elsewhere on the board

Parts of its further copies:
RB3, RB4: R0603_51R_1%_0.1W_100PPM; RESC1608X55N; Voltage ~~; Tolerance ±1%; Part Number R0603_51R_1%_0.1W_100PPM
RB5, RB52: R0603_160R_1%_0.1W_100PPM; RESC1608X55N; Voltage ~~; Tolerance ±1%; Part Number R0603_160R_1%_0.1W_100PPM
RB6, RB51: R0603_22R_1%_0.1W_100PPM; RESC1608X55N; Voltage ~~; Tolerance ±1%; Part Number R0603_22R_1%_0.1W_100PPM
RC3, RC4: R0603_51R_1%_0.1W_100PPM; RESC1608X55N; Voltage ~~; Tolerance ±1%; Part Number R0603_51R_1%_0.1W_100PPM
RC5, RC52: R0603_160R_1%_0.1W_100PPM; RESC1608X55N; Voltage ~~; Tolerance ±1%; Part Number R0603_160R_1%_0.1W_100PPM
RC6, RC51: R0603_22R_1%_0.1W_100PPM; RESC1608X55N; Voltage ~~; Tolerance ±1%; Part Number R0603_22R_1%_0.1W_100PPM
RD3, RD4: R0603_51R_1%_0.1W_100PPM; RESC1608X55N; Voltage ~~; Tolerance ±1%; Part Number R0603_51R_1%_0.1W_100PPM
RD5, RD52: R0603_160R_1%_0.1W_100PPM; RESC1608X55N; Voltage ~~; Tolerance ±1%; Part Number R0603_160R_1%_0.1W_100PPM
RD6, RD51: R0603_22R_1%_0.1W_100PPM; RESC1608X55N; Voltage ~~; Tolerance ±1%; Part Number R0603_22R_1%_0.1W_100PPM
RE3, RE4: R0603_51R_1%_0.1W_100PPM; RESC1608X55N; Voltage ~~; Tolerance ±1%; Part Number R0603_51R_1%_0.1W_100PPM
RE5, RE52: R0603_160R_1%_0.1W_100PPM; RESC1608X55N; Voltage ~~; Tolerance ±1%; Part Number R0603_160R_1%_0.1W_100PPM
RE6, RE51: R0603_22R_1%_0.1W_100PPM; RESC1608X55N; Voltage ~~; Tolerance ±1%; Part Number R0603_22R_1%_0.1W_100PPM

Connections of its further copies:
/CONN/DSI_CLK_N: RE4.2, RE5.1, RE6.1; also elsewhere on the board
/CONN/DSI_CLK_P: RE3.1, RE51.2, RE52.1; also elsewhere on the board
/CONN/DSI_L1_N: RB4.2, RB5.1, RB6.1; also elsewhere on the board
/CONN/DSI_L1_P: RB3.1, RB51.2, RB52.1; also elsewhere on the board
/CONN/DSI_L2_N: RC4.2, RC5.1, RC6.1; also elsewhere on the board
/CONN/DSI_L2_P: RC3.1, RC51.2, RC52.1; also elsewhere on the board
/CONN/DSI_L3_N: RD4.2, RD5.1, RD6.1; also elsewhere on the board
/CONN/DSI_L3_P: RD3.1, RD51.2, RD52.1; also elsewhere on the board
/FPGA/DSI_HS_CLK_N: RE5.2; also elsewhere on the board
/FPGA/DSI_HS_CLK_P: RE52.2; also elsewhere on the board
/FPGA/DSI_HS_N1: RB5.2; also elsewhere on the board
/FPGA/DSI_HS_N2: RC5.2; also elsewhere on the board
/FPGA/DSI_HS_N3: RD5.2; also elsewhere on the board
/FPGA/DSI_HS_P1: RB52.2; also elsewhere on the board
/FPGA/DSI_HS_P2: RC52.2; also elsewhere on the board
/FPGA/DSI_HS_P3: RD52.2; also elsewhere on the board
/FPGA/DSI_LP_CLK_N: RE6.2; also elsewhere on the board
/FPGA/DSI_LP_CLK_P: RE51.1; also elsewhere on the board
/FPGA/DSI_LP_N1: RB6.2; also elsewhere on the board
/FPGA/DSI_LP_N2: RC6.2; also elsewhere on the board
/FPGA/DSI_LP_N3: RD6.2; also elsewhere on the board
/FPGA/DSI_LP_P1: RB51.1; also elsewhere on the board
/FPGA/DSI_LP_P2: RC51.1; also elsewhere on the board
/FPGA/DSI_LP_P3: RD51.1; also elsewhere on the board
GND: RB3.2, RB4.1, RC3.2, RC4.1, RD3.2, RD4.1, RE3.2, RE4.1; also elsewhere on the board

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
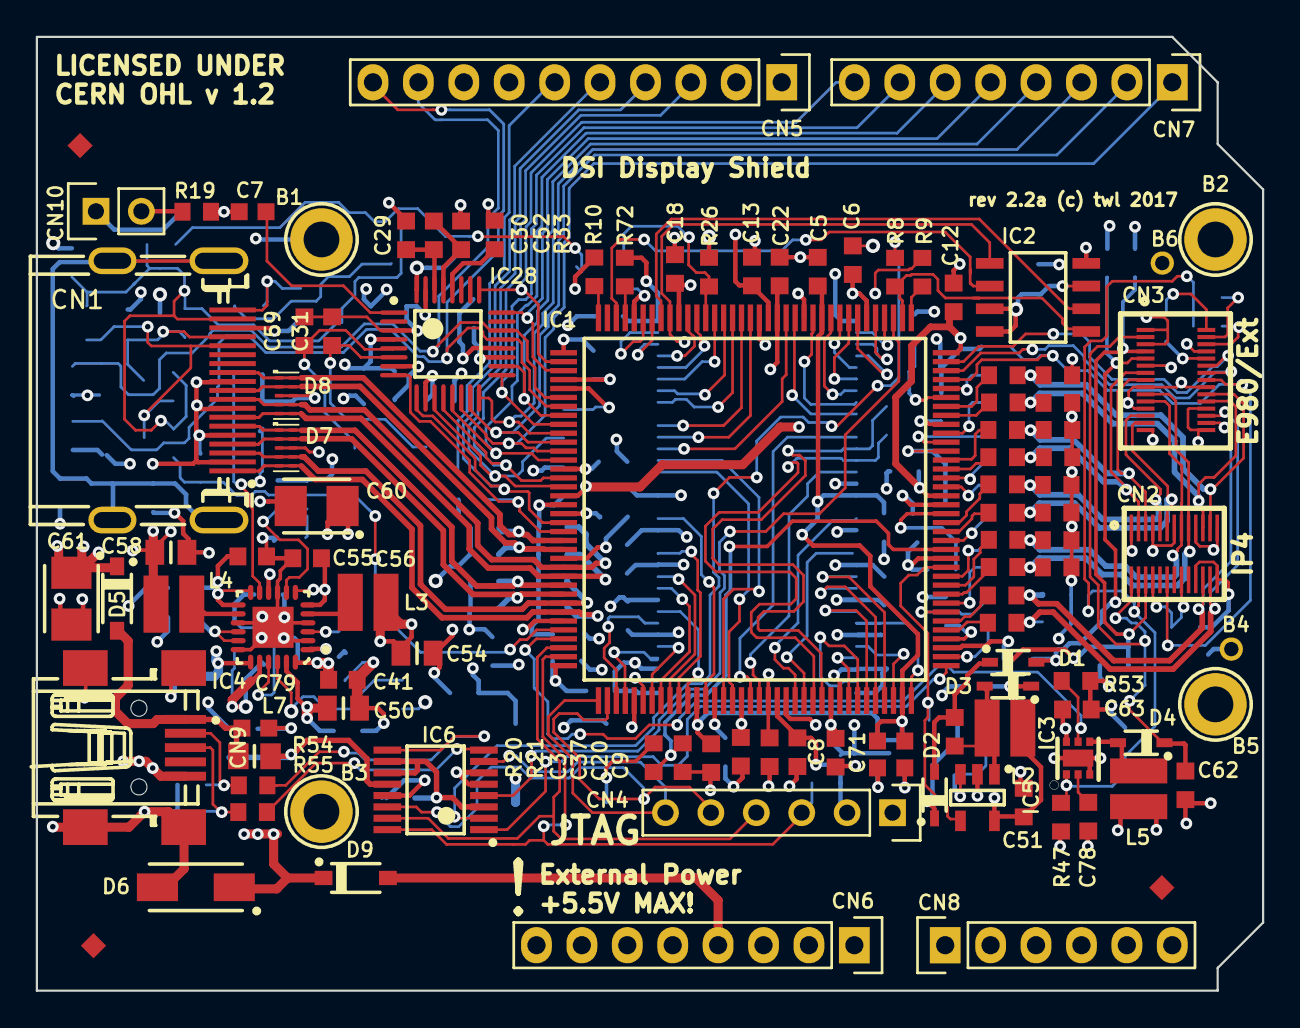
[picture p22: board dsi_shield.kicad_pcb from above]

Board: 4 copper layers, 68.6 x 53.3 mm, 224 parts (0 on the bottom side), 167 nets.

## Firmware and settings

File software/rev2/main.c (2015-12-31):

/*
 * DSI Shield
 * Copyright (C) 2013-2015 twl <twlostow@printf.cc>
 *
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
 * You should have received a copy of the GNU Lesser General Public
 * License along with this library; if not, write to the Free Software
 * Foundation, Inc., 51 Franklin Street, Fifth Floor, Boston, MA  02110-1301
 * USA
 */

/* main.c - main DSI Shield application */

#include <stdint.h>
#include <stdio.h>

#include "board.h"
#include "libhpdmc.h"
#include "dsi_core.h"
#include "fb.h"
#include "panels.h"
#include "sysctl.h"
#include "pll.h"
#include "uart.h"
#include "config.h"
#include "pp-printf.h"
#include "flash.h"
#include "menu.h"

static struct dsi_panel_config *panel;

int  sdram_init();

void center_text(const struct fb_font *font,
                 int                   y,
                 int                   scale,
                 const char           *str,
                 uint32_t              color)
{
    fb_text(font, (fb_width - fb_text_width(font,
                                            scale,
                                            str)) / 2, y, scale, str, color);
}

void show_nosignal_screen()
{
    fb_clear(fb_makecolor(0, 0, 0));

    fb_rect(0, 0, fb_width - 1, fb_height - 1, fb_makecolor(255, 255, 255));

    //    fb_draw_bitmap ( fb_width / 2 - bmp_logo.h / 2, fb_height / 2 -
    // bmp_logo.w , &bmp_logo );

    center_text(&font_helv17,
                fb_height / 2 + 40,
                4,
                "No HDMI signal :-(",
                fb_makecolor(255, 32, 32));


    char str[80];

    pp_sprintf(str,
               "Panel: %s (%d x %d)",
               panel->name,
               panel->width,
               panel->height);

    fb_text(&font_helv17,
            fb_width / 2 - 300,
            fb_height / 2 + 120,
            2,
            str,
            fb_makecolor(255, 255, 255));
    pp_sprintf(str,
               "Data rate: %d lanes x %d MBps",
               panel->num_lanes,
               dsi_calc_bitrate(panel));

    fb_text(&font_helv17,
            fb_width / 2 - 300,
            fb_height / 2 + 150,
            2,
            str,
            fb_makecolor(255, 255, 255));

    int byte_clock = pll_phy_freq() / 8 * panel->num_lanes;
    pp_sprintf(str, "Pixel clock: %d MHz", byte_clock / 3 / 1000000);

    fb_text(&font_helv17,
            fb_width / 2 - 300,
            fb_height / 2 + 180,
            2,
            str,
            fb_makecolor(255, 255, 255));

    pp_sprintf(str, "Refresh rate: %d Hz", dsi_calc_vrefresh(panel));
    fb_text(&font_helv17,
            fb_width / 2 - 300,
            fb_height / 2 + 210,
            2,
            str,
            fb_makecolor(255, 255, 255));


    pp_sprintf(str, "System clock: %d Hz", pll_system_freq());
    fb_text(&font_helv17,
            fb_width / 2 - 300,
            fb_height / 2 + 240,
            2,
            str,
            fb_makecolor(255, 255, 255));
}

#define ST_IDLE 0
#define ST_NO_HDMI 3
#define ST_GOT_HDMI 1
#define ST_ACTIVE_HDMI 2

void panel_set_brightness(int brightness)
{
    int v = brightness * 31 / 100;

    writel(SYS_PWM_CTL, v);
}

void hdmi_fsm_update()
{
    static int state = ST_IDLE;

    switch (state)
    {
    case ST_IDLE:

        if (!fb_hdmi_check_link())
        {
            panel_set_brightness(0);
            show_nosignal_screen();
            panel_set_brightness(current_config.brightness);

            state = ST_NO_HDMI;
        } else
            state = ST_NO_HDMI;

        break;

    case ST_NO_HDMI:

        if (fb_hdmi_check_link())
        {
            //					pp_printf("HDMI: link up\n");
            fb_enable_overlay();
            fb_clear(fb_makecolor(0xff, 0xff, 0xf8));
            state = ST_ACTIVE_HDMI;
        }
        break;

    case ST_ACTIVE_HDMI:

        if (!fb_hdmi_check_link())
        {
            //					pp_printf("HDMI: link down\n");
            panel_set_brightness(0);

            fb_disable_overlay();
            show_nosignal_screen();
            panel_set_brightness(current_config.brightness);
            state = ST_NO_HDMI;
        }
        break;
    }
}

void run()
{
    for (;;)
    {
        cfg_menu_refresh();
        hdmi_fsm_update();
    }
}

void init()
{
    uart_init_hw();

    pp_printf("DSI Shield (build %s, %s) starting up...\n",
              build_revision,
              build_date);

    writel(SYS_PWM_CTL, 0);

    sdram_init();
    flash_init();

    cfg_init();
    cfg_menu_init();

    writel(SYS_GPIO_OUT, SYS_GPIO_OUT_EDID_EN);

    panel =  cfg_current_panel();

    if (panel->pll_cfg)
        pll_reconfigure(panel->pll_cfg);

    dsi_init(panel);

    if (panel->edid_data)
        fb_load_edid(panel->edid_data);

    fb_set_mode(panel->width, panel->height);

    pp_printf("Startup complete.\n");
}

int main()
{
    init();
    run();
    return 0;
}

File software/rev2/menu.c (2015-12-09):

/*
 * DSI Shield
 *
 * Copyright (C) 2013-2014 twl
 *
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
 * You should have received a copy of the GNU General Public License along
 * with this program.  If not, see <http://www.gnu.org/licenses/>.
 */

/* menu.c - config menu stuff */

#include <stdio.h>
#include <string.h>

#include "uart.h"
#include "pp-printf.h"
#include "config.h"
#include "panels.h"

#define ESC_CHAR 0x1b
#define ESC_TIMEOUT 10000

#define KEY_UP 0x1b41
#define KEY_DOWN 0x1b42
#define KEY_LEFT 0x1b44
#define KEY_RIGHT 0x1b43
#define KEY_ENTER 0x0d

#define CMD_ENTER 1
#define CMD_FORMAT 2
#define CMD_KEY 3

int kb_state = 0;

int kb_expect()
{
    int timeout;

    for (timeout = ESC_TIMEOUT; timeout > 0; timeout--)
        if (uart_poll()) return uart_read_byte();

    return -1;
}

int kb_input()
{
    int i, timeout;

    if (!uart_poll()) return 0;

    int c = uart_read_byte();

    if (c == ESC_CHAR)
    {
        c = kb_expect();

        if (c < 0) return ESC_CHAR;

        if (c != '[')
        {
            return 0;
        }
        c = kb_expect();

        if (c < 0) return 0;

        return (c & 0xff) | 0x1b00;
    }

    return c;
}

struct menu_item
{
    const char *label;
    int         (*func)(int   cmd,
                        void *data);
};

int cb_display_type(int cmd, void *data)
{
    int key = (int)data;

    switch (cmd)
    {
    case CMD_FORMAT:
        pp_sprintf((char *)data, "%s", current_config.display_type);
        return 1;

    case CMD_KEY:
    {
        int idx = cfg_find_panel_index(current_config.display_type);
        struct dsi_panel_config *panel;

        if ((key == KEY_LEFT) && (idx > 0)) idx--;
        else if ((key == KEY_RIGHT) && (idx < panel_count() - 1)) idx++;

        panel = panel_get_config(idx);

        strcpy(current_config.display_type, panel->name);
    }

        return 0;

    case CMD_ENTER:
        return 0;
    }
}

int cb_display_brightness(int cmd, void *data)
{
    int   i, b;
    char *buf = (char *)data;

    switch (cmd)
    {
    case CMD_FORMAT:
    {
        *buf++ = '[';


        b = current_config.brightness * 32 / 100;

        for (i = 0; i < 32; i++) *buf++ = (i < b ? '#' : ' ');

        *buf++ = ']';

        pp_sprintf(buf, " %d%%", current_config.brightness);


        return 1;
    }

    case CMD_KEY:
    {
        int key = (int)data;

        if (key == KEY_LEFT) current_config.brightness -= 5;
        else if (key == KEY_RIGHT) current_config.brightness += 5;

        if (current_config.brightness < 0) current_config.brightness = 0;

        if (current_config.brightness > 100) current_config.brightness =
                100;

        panel_set_brightness(current_config.brightness);
        break;

    case CMD_ENTER:
        return 0;
    }
    }
    return 0;
}

int cb_save_restart(int cmd, void *data)
{
    if (cmd == CMD_ENTER)
    {
        cfg_write(&current_config);

        pp_printf("\033[2J\033[;H");
        pp_printf("Rebooting device...\n");
        delay(2000000);
        asm volatile ("li t0,0");
        asm volatile ("jr t0");

        //	exit(0);
    }

    return 0;
}

int cb_device_info(int cmd, void *data)
{
    int cnt, i;

    if (cmd == CMD_ENTER)
    {
        pp_printf("\033[2J\033[;H");
        pp_printf("DSI Shield Device Info\n\n");
        pp_printf("Firmware version: %s, built on %s\n",
                  build_revision,
                  build_date);
        pp_printf("Supported displays: \n");
        cnt = panel_count();

        for (i = 0; i < cnt; i++)
        {
            struct dsi_panel_config *panel = panel_get_config(i);
            pp_printf(
                "- %s (%dx%d, DSI %d-lane, %d MBps/lane, %d Hz refresh\n",
                panel->name,
                panel->width,
                panel->height,
                panel->num_lanes,

                dsi_calc_bitrate(panel),
                dsi_calc_vrefresh(panel)
                );
        }

        return 1;
    }

    if (cmd == CMD_KEY)
    {
        return 0;
    }

    return 0;
}

static struct menu_item cfg_menu_items[] =
{
    { "Select display type",
      cb_display_type                                           },
    { "Adjust brightness",
      cb_display_brightness                                     },
    { "Device info",
      cb_device_info                                            },
    { "Save settings & restart",
      cb_save_restart                                           },
    { NULL }
};


struct menu_state {
    char             *title;
    struct menu_item *items;
    struct menu_item *active;
    int               state;
    int               current_item;
    int               n_items;
};


static struct menu_state cfg_menu =
{
    "DSI Shield Setup (up/down to navigate, left/right to adjust)",
    cfg_menu_items
};


void menu_init(struct menu_state *state)
{
    int i;

    state->current_item = 0;
    state->active       = NULL;
    state->n_items      = 0;

    for (i = 0; state->items[i].label; i++) state->n_items++;
}

void menu_refresh(struct menu_state *menu)
{
    char buf[64];
    struct menu_item *item;

    int i;

    int c = kb_input();


    if (!c) return;

    if (menu->active)
    {
        if (!menu->active->func(CMD_KEY, (void *)c))
        {
            pp_printf("disactivate\n");
            menu->active = NULL;
        } else return;
    }

    switch (c)
    {
    case KEY_UP:

        if (menu->current_item > 0) menu->current_item--;
        break;

    case KEY_DOWN:

        if (menu->current_item < menu->n_items - 1) menu->current_item++;
        break;

    case KEY_ENTER:
        item = &menu->items[menu->current_item];


        if (item->func)
        {
            if (item->func(CMD_ENTER, menu))
            {
                menu->active = item;
                return;
            }
            else menu->active = NULL;
        }
        break;

    default:
    {
        item = &menu->items[menu->current_item];

        if (item->func) item->func(CMD_KEY, (void *)c);

        break;
    }
    }

    pp_printf("\033[2J\033[;H");
    pp_printf("%s\n\n", menu->title);

    int max_len = 0, l, j;

    for (i = 0; i < menu->n_items; i++)
    {
        l = strlen(menu->items[i].label);

        if (l > max_len) max_len = l;
    }

    for (i = 0; i < menu->n_items; i++)
    {
        struct menu_item *item = &menu->items[i];

        if (i == menu->current_item)
            pp_printf("\033[7m");

        l = strlen(item->label);

        pp_printf(" %s", item->label);

        for (j = 0; j < max_len + 1 - strlen(item->label); j++)
            pp_printf(" ");

        pp_printf("\033[0m");

        if (item->func && item->func(CMD_FORMAT, buf))
        {
            pp_printf(" : %s", buf);
        }

        pp_printf("\n");
    }
}

void cfg_menu_refresh()
{
    menu_refresh(&cfg_menu);
}

void cfg_menu_init()
{
    menu_init(&cfg_menu);
}

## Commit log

2014-08-16 rev 1.0, release candidate (PCB+HDL+Software)
    [adapter-iphone4.csv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]
2014-12-11 pcb: added component designators
    [hdmi-dsi-top.GBO]
2015-09-06 rev2 sw working on rev1 pcb with DNA display
2015-09-16 e980 @ 56 Hz
2015-12-09 top/rev2: bit-banged SPI flash & PLL reconf support
2015-12-09 sw: fake I/O registers for UART used to speed up simulations
2015-12-09 sw: new FW with config menu & dynamic display switching, supports both IP4 and E980
2015-12-10 software: clean up Makefile, moved flash stuff to common dir, added missing files
    [main.c]
2015-12-31 software: code formatting, removing warnings, copyright stuff hdl: missing manifests
    [flash.c, main.c]
2015-12-31 hdl: fixed PWM frequency for dimming the backlight
2017-08-16 moved rev1 resign to a separate directory
    [adapter-iphone4.csv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]
2017-08-23 pcb/rev2: Completed rev2 PCB port to KiCad, passes DRC+LVS. NOT MANUFACTURED.
    [composite_input.sch, ddr_sdram.sch, dsi_connectors.sch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]

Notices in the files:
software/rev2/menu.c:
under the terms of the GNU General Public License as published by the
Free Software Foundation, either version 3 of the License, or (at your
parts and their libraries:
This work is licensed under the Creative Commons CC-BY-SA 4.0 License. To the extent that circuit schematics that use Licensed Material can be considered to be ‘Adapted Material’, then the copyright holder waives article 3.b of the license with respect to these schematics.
